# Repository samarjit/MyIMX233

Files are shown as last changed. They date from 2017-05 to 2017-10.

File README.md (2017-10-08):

# Let me see if I can build a linux Computer (It works now!)

I am starting to build a single board computer with freescale microprocessor iMX233 128 LQFP and 64MB DDR2 SDRAM in 66TSOP. This single board computer will be bare bones with lots of GPIO exposed.
There is no special goal for this project. I am just curious to see if it works. In future I might add an LCD. The PCB is two layered only and can be manufactured cheap.

## TODOs (done)
* Increase pad lengths of LQFP footprint. (done. Hope to mitigate the soldermask between pads issue  |<-0.06mm space-><-0.08mm web-><-0.06mm space->|  = 0.2mm) 
* Perhaps add a jumper on the 2.5v LineReg and separate out VDD_MEM to be able to test the 2.5v is not 0 due to loading. (skipped)
* 88 USB_ID SSP1_DETECT ? Should I use this to CD of SD card connector or micro USB ID pin?  In my circuit it is pulled low via LED. Tux,calculator does the same too.
* Add option to boot resistors LCD_RS and LCD_00..LCD_05 (done)
* 14 LCD_RS ? High for register boot mode. Or low with 47k resistor for OTP boot mode. Olimex is confusing OTP is set MMBR and LCD_RS is high. (done)
* Schottkey Diode D1 VDD4P2 direction. Its strange in ref diagram vs 5v wall. VDD4P2 -|>||- VDDBATT. (done Optional. Not populated in running board)
* Series resistor 1E for preventing oscillations (done 3 series resistor added, usb, batt, 4p2)
/in old circuit Test by removing Diode, and LED_RS to gnd via resistor.
* RESET circuit? Make sure not to get into USB recovery mode. add zener 1.0v so that it never reached 3.3v or just remove reset circuit altogether.
* Configure to get rid of batteries as per rev-c circuit. Add 1k resistors in DCDC_BATT and BATT and some caps to GND.
* Need to convert the SD card connector to a cheaper version available on ebay or alibaba. (done part-ATTEND 112J-TDAR-R01)
I got the files from https://forum.kicad.info/t/microsd-component-footprint-help/3095/5 and placed in parts/ folder. 
It would be awesome if I can find some 3D model of it. If someone finds it please create an issue. (Yes found)
* Make DDR RAM pin pads longer (new)
* Make alternate USB plug preferably through hole or longer pads in micro USB. (new)
* Make micro-SD pads larger and longer and add a few decoupling capacitors.(new)
* Make more rooms for the inductor as most inductors are really big 8mm long plus place for hand soldering.(new)

## TODOs (ignored)
* POWER off circuit? 
* Is Micro SD pullups on all pins necessary? SSP1_DETECT used? (done added them in the bottom side. Data3/CS pulled low)
* Added 120R between CLK nCLK.

### Length Tuning
* D0..D7 LDQS LDM - 39.7mm tuning (real 40.2mm)
* CLK nCLK - real 32.2/32.6mm
* D8..D15 UDQS UDM - 25.5mm tuning (real 26.0mm)
* Address: 32.35mm ~ 25mm
* CKE- 20.2mm
* SD: 24.8mm tuning (real 25.3mm)

## Installation steps
Cloning this repository should work.
It does use opendous
conn_fci from https://github.com/cpavlina/kicad-pcblib.git, https://github.com/cpavlina/kicad-schlib.git
Copy kicad-pcblib\conn-fci.pretty to  KiCad\share\kicad\modules\conn-fci.pretty
Add kicad-schlib-master\library\conn-fci.lib  to SchematicEditor -> ComponentLibraries
Add opendous to component libraries too.

## Drivers for this project.
* Until recently I didn't know of a decent opensource software for PCB designing or circuit designing which can be used to design complicated circuits involving microprocessor.
I recently discovered KiCAD which is opensource pcb designing software and people have done microprocessor design with it eg. OLinuXino. I am trying to learn PCB designing using KiCAD now.
* Second driver was Clementine Core project which I saw in circuitmaker website. This schematic looked so simple and pcb was on 2 layer design, which changed my thought process altogether that linux running board designs may be something I can try.
* Third driver was LibreCalc which almost proved that KiCAD can be used to design IMX233 based board. I hope to learn from their mistakes, but a newbee like me can uncover a whole lot of new mystries.

So I have put together a mashup of schematic design of IMX233 and 64MB RAM from freescale reference design and other sources. 

**Freescale microprocessor:**
* MCIMX233CAG4C

**DDR RAM - I think all these below RAM chips are compatible.**
* AS4C32M16MD1-5TCN
* HY5DU121622D(L)T(P)-J
* MT46V32M16P-5B:J (This is the only one I can source, so I am using this)

This project is a work in progress and there is no gurantee that I will ever be able to complete it :).

But if you want to try building same stuff as I am building. Go ahead and fork it.
Download KiCad. I am using nightly version of it, because it does not require you to export the netlist and import it again in pcb editor. Make the workflow really easy.
I can see one bug in KiCAD, which is after modifying the footprint by adding a step file. It looses the saved settings. 

Once you have installed KiCAD, open **MyIMX233.pro** file. 

[MyIMX233.sch](MyIMX233.sch) - Schematic file.

[MyIMX233.kicad_pcb](MyIMX233.kicad_pcb) - PCB

[ReferenceSch](ReferenceSch) - contains reference materials. I uploaded all of them for providing content incase someone wants to understand the design.

## Progress: 

### Oct 8 It worked! You can start building one today for yourself :)
Few soldering quirks are there. USB pads are quite small to solder. Also pad to hold USB in place is also very small and bad for soldering. Even the SD card pads are also small for soldering. These were new footprints so in next version I will make longer pads for these. RAM pads can be made slightly longer for reliable soldering. 
Soldered board and powered up without SD card. Some error were coming 0x80207002. Boot loader looking for I2C and it is not initialized. Turned out to be soldering of one pin was not proper for LQFP128. Fixed this pin issue then SD card missing related errors were coming. Added SD card with bogus data 0x8020A007 - ERROR_DDI_SD_CONFIG_BLOCK_NOT_FOUND. Added SD card formatted properly but still 0x8020A007. Little bit further digging showed that SD card MBR boot is not enabled by default. We need to burn an OPT bit HW_OCOTP_ROM0::SD_MBR_BOOT to enable booting from SD card. This process is irreversible. Default boot mode is BCB. I read up again librecalc's failure blog.  It gave two perl programs to burn the SD card with u-boot in BCB mode. The 2nd perl program didn't run as it assumed smaller SD cards only. I edited the perl program to make it find proper boot signatures. Now we can see something HTLC in UART console.
That's too less info to debug further. At this point I posted in freescale community. https://community.nxp.com/message/949934. I decided to blow the MBR OTP flag using BitBurner. Then added MBR based uSD card and same u-boot. Now again it shows HTLC. Good news is that MBR booting works. But it fails very soon. Need bootlets which gives more detailed log instead of u-boot. Turned out voltages are fluctuating all 3v3, 4v2, 1v8, 1v. They were fluctuating in a cycle. I burned official Olinuxino image in SD card. That seems to have bootlets so it gave more info. After right after memory `FRAC 0x92926192` it reboots. I heated up all the pins of DDR and iMX233 with soldering iron. It goes 1 more line ahead in log `init_ddr_mt46v32m16_133Mhz` and sometimes `power 0x00820710`. I added a big capacitor in place of battery which goes the log to further and says uSD card general error ending with r14<0>HTLLLL... I tried adding a few caps on 3v3. But nothing helped. Then I tried the other jumper of battery mode. Then it started loading kernel. 
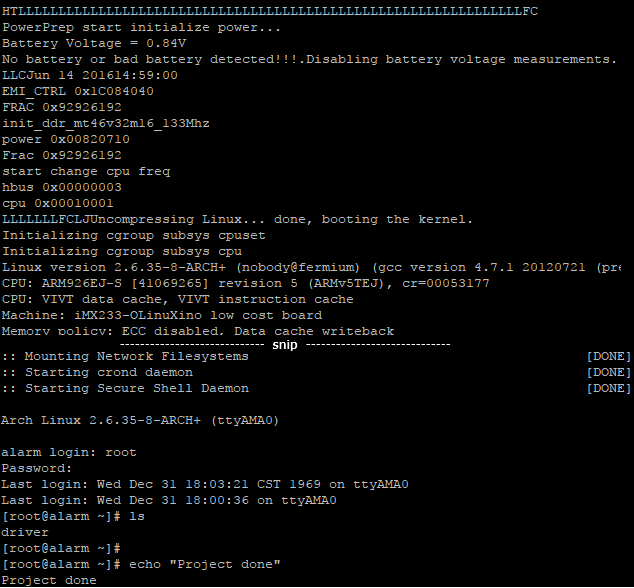
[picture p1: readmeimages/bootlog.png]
Bootup logs

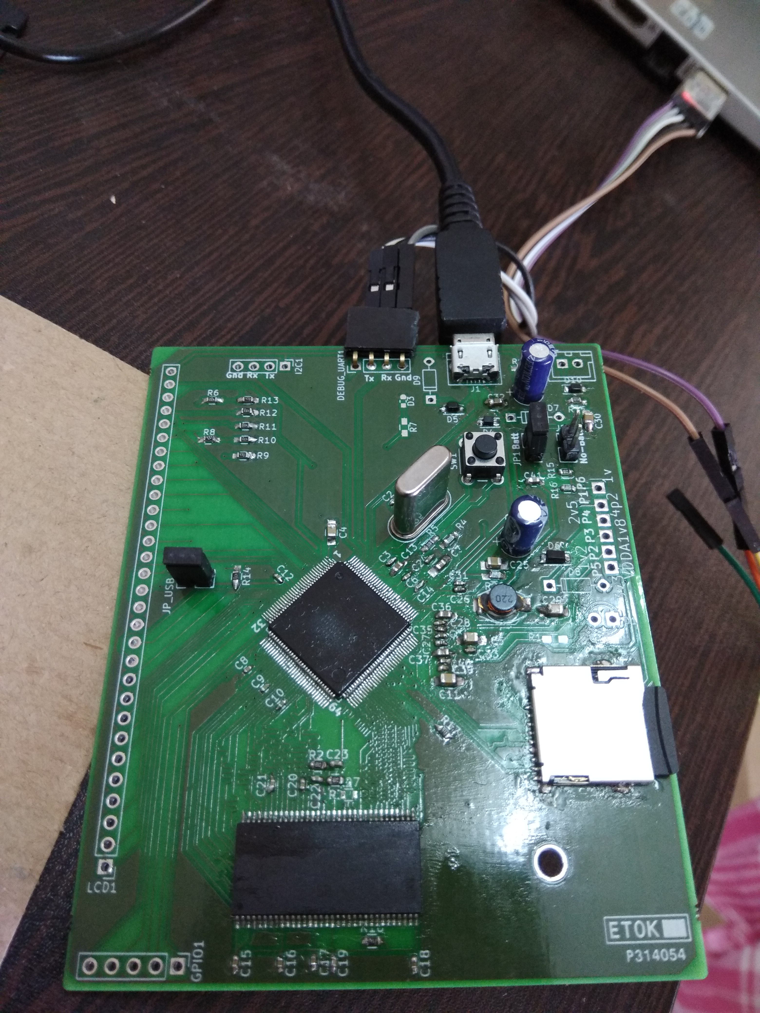
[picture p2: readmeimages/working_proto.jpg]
Final Board


### Aug 2017
Started modifying the schematic to make battery and USB wall power optional using jumpers. Also realized boot selection can be done using resistors. Sent for fabrication of PCB to pcbpower.

### July 2017 end first soldered board
Good news is most of the components fitted. Also I got some confidence about my KiCAD skills.
Some shortcomings were observed, like the pads for soldering were two short for the fine pitched LQFP128 0.4mm pitch and solder mask dams were not created between pads which made it incredibly hard to solder. I will have to customize the LQFP128 footprint to make it suitable for hand soldering. Some 0402 caps were placed very close, I realized the courtyard verification of components is not turned on by default. I had limited success like UART was working USB was working, BitBurner was working and showing all the OPT(One Time Programmable) bits. Some gibberish was coming on UART console. I used solder paste for soldering, so I thought some shorting might be happening. Then I tried to do reflow soldering to make the solder joints liquify once and then quickly cool it using a frying pan. It actually fried my board! I also mistakenly soldered uSD card with power on! Carelessness!
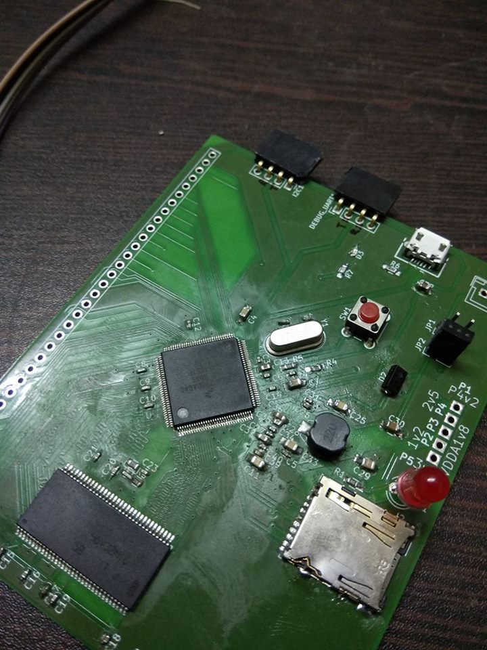
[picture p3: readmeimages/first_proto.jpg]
First Proto Soldered


* I also ordered components. I didn't realize this would be a pain. element14 is not that accessible for an individual. I ordered mostly from Shelfkey and some from KitsNSpares. I am still tensed if footprints I chose will match the actual components. Second I am very much tensed about soldering 0402 components.
* Final version of PCB sent for fab in pcbpower. 
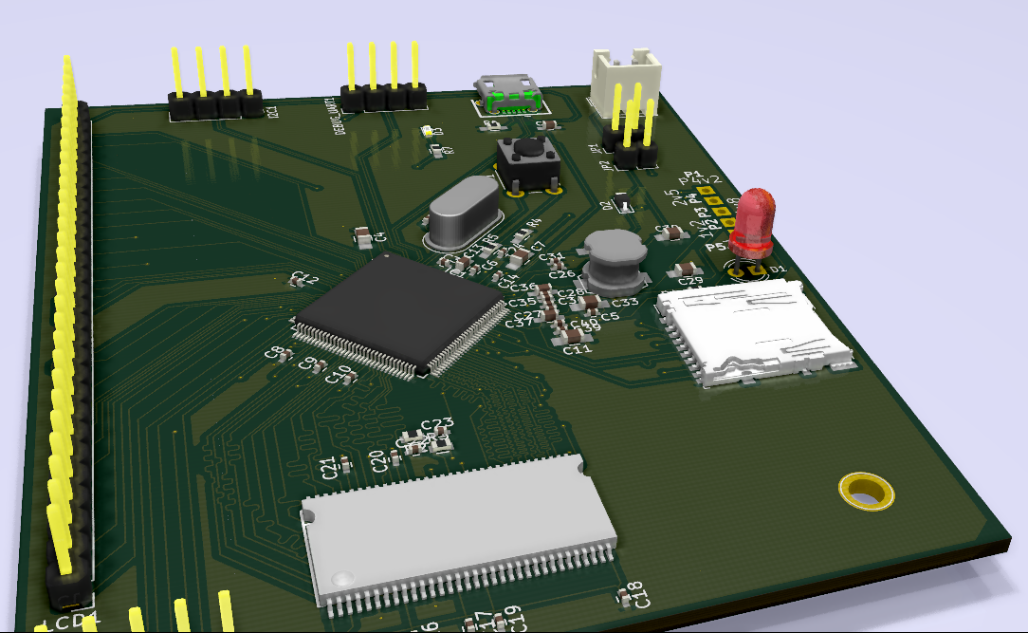
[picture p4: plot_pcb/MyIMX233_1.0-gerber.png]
Sent to fab


* Added few options to use DCDC. I was not comfortable of grounding DCDC_BATT and BATT pins, so I added a few jumpers. Also added provisions to add battery. 

* Learnt basic Freecad to build the Step files of DDR SDRAM 66TSOP. Here is the project I created - [MT46V32M16P-5B-Freecad-Step](https://github.com/samarjit/MT46V32M16P-5B-Freecad-Step).

* Initial version. DDR RAM child 3D missing and SD card's 3D missing.
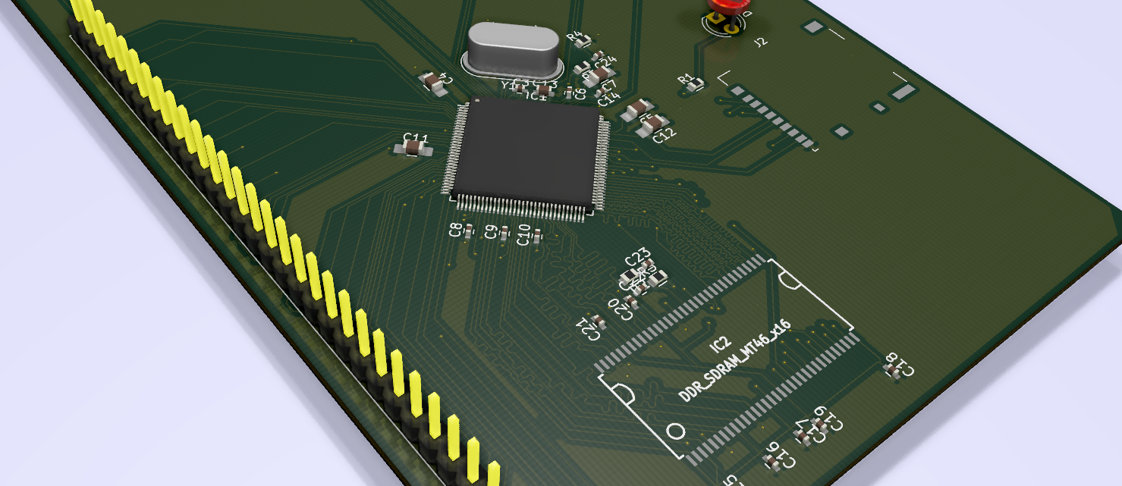
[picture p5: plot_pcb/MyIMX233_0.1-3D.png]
Initial plot


* Learnt Length Matching in Kicad. 

* Figured out placement of components. I am going with Clementine Core's placement which seems very good. 
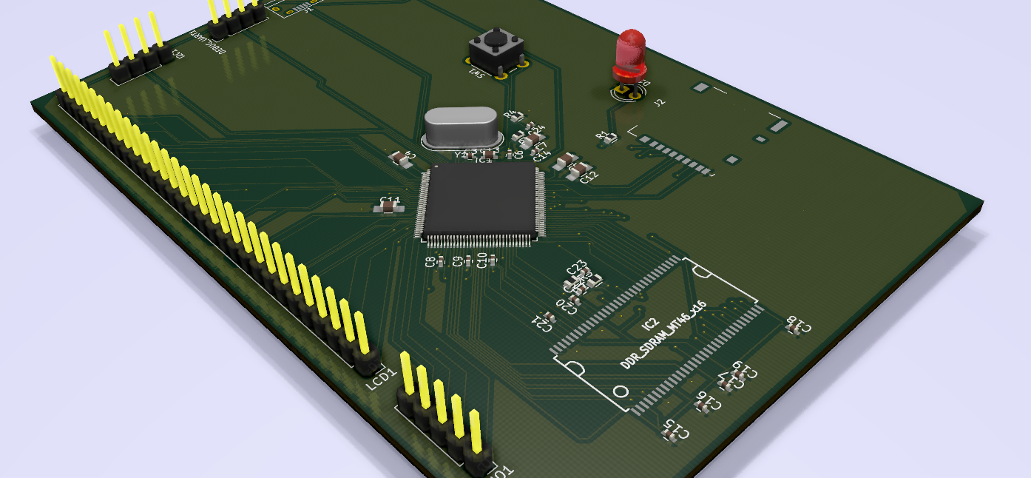
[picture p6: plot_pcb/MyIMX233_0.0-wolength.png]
Initial plot


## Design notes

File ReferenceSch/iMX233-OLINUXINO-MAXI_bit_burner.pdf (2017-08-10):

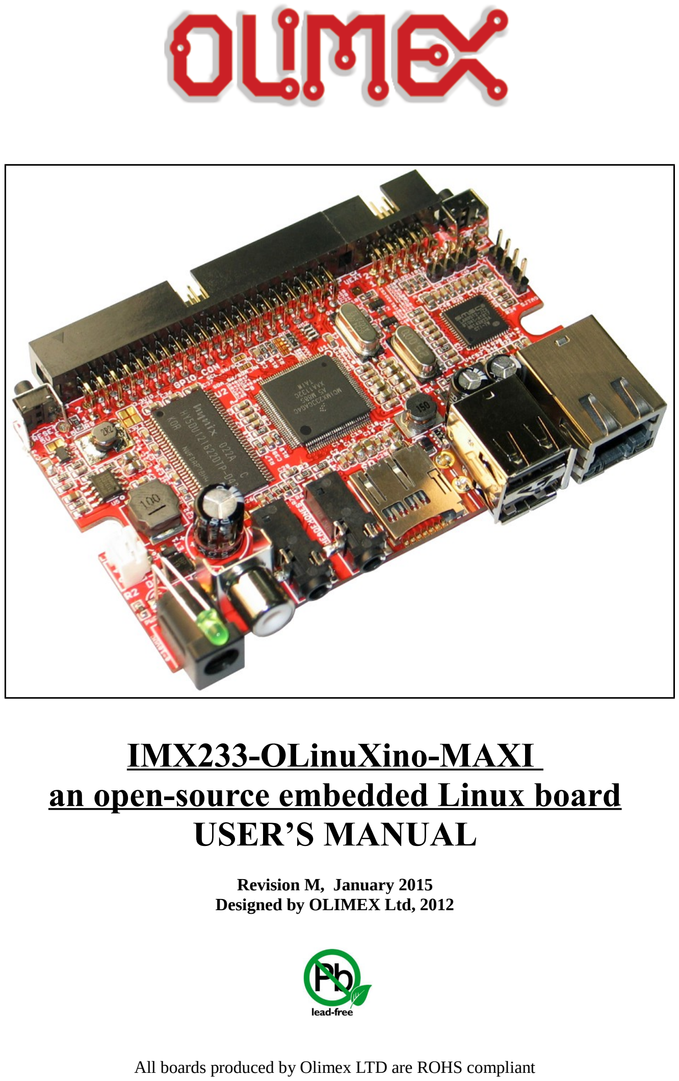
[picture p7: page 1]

# IMX233-OLinuXino-MAXI an open-source embedded Linux board USER’S MANUAL

Revision M, January 2015
Designed by OLIMEX Ltd, 2012

All boards produced by Olimex LTD are ROHS compliant

OLIMEX© 2015 | IMX233-OLinuXino-MAXI user's manual

### DISCLAIMER

© 2015 Olimex Ltd. Olimex®, logo and combinations thereof, are registered trademarks of Olimex Ltd. Other product names may be trademarks of others and the rights belong to their respective owners.

The information in this document is provided in connection with Olimex products. No license, express or implied or otherwise, to any intellectual property right is granted by this document or in connection with the sale of Olimex products.

This work is licensed under the Creative Commons Attribution-ShareAlike 3.0 Unported License. To view a copy of this license, visit http://www.creativecommons.org/licenses/by-sa/3.0/.

This hardware design by Olimex LTD is licensed under a Creative Commons Attribution-ShareAlike 3.0 Unported License.

The software is released under GPL.

It is possible that the pictures in this manual differ from the latest revision of the board.

The product described in this document is subject to continuous development and improvements. All particulars of the product and its use contained in this document are given by OLIMEX in good faith. However all warranties implied or expressed including but not limited to implied warranties of merchantability or fitness for purpose are excluded. This document is intended only to assist the reader in the use of the product. OLIMEX Ltd. shall not be liable for any loss or damage arising from the use of any information in this document or any error or omission in such information or any incorrect use of the product.

This evaluation board/kit is intended for use for engineering development, demonstration, or evaluation purposes only and is not considered by OLIMEX to be a finished end-product fit for general consumer use. Persons handling the product must have electronics training and observe good engineering practice standards. As such, the goods being provided are not intended to be complete in terms of required design-, marketing-, and/or manufacturing-related protective considerations, including product safety and environmental measures typically found in end products that incorporate such semiconductor components or circuit boards.

Olimex currently deals with a variety of customers for products, and therefore our arrangement with the user is not exclusive. Olimex assumes no liability for applications assistance, customer product design, software performance, or infringement of patents or services described herein.

THERE IS NO WARRANTY FOR THE DESIGN MATERIALS AND THE COMPONENTS USED TO CREATE OLINUXINO. THEY ARE CONSIDERED SUITABLE ONLY FOR OLINUXINO.

## Table of Contents

### CHAPTER 1: OVERVIEW

### 1. Introduction to the chapter

Thank you for choosing the OLinuXino single board computer from Olimex! This document provides a user’s guide for the Olimex OLinuXino board. As an overview, this chapter gives the scope of this document and lists the board’s features. The differences between the members of the OLinuXino family are mentioned. The document’s organization is then detailed.

The OLinuXino development board enables code development of applications running on the microcontroller i.MX233, manufactured by FreeScale Semiconductor.

OLinuXino is an open-source, open-hardware project and all documentation is available to the customer.

### 1.1 Features

- iMX233 ARM926J processor at 454Mhz
- 64 MB RAM
- SD-card connector for booting the Linux image
- TV PAL/NTSC video output
- 3 USB High Speed Host
- optional WIFI RTL8188CU module
- Stereo Audio Input
- Stereo Headphones Audio Output
- two Buttons
- UEXT connector (http://olimex.com/dev/OTHER/UEXT.pdf) for connection of different peripherial modules
- 40 pin GPIO for connection of other hardware
- Board is in shape for fit inside Pactec JM42 plastic box http://www.pactecenclosures.com/pdfs/drw_JM-42.pdf
- Power supply input 6-16VDC
- PCB dimensions: 3.70'' x 2.15'' (94.0mm x 54.6mm)
- Nominal dimensions: 3.70'' x 2.65'' (94.0mm x 67.3mm)

### 1.2 The OLinuXino family

Table of comparison
| OLinuXino-NANO | OLinuXino-MICRO | OLinuXino-MINI | OLinuXino-MAXI
Processor | iMX233 @ 454Mhz | iMX233 @ 454Mhz | iMX233 @ 454Mhz | iMX233 @ 454Mhz
Ram [MB] | 64 | 64 | 64 | 64
# USB hosts | 1 | 1 | 3 | 2

100/150 Mbit Ethernet* | No/WIFI option** | No/WIFI option** | No/WIFI option*** | Yes/WIFI option**
GPIO connector | 40pins | 60pins | 40pins | 40pins
# of buttons | 3 | 3 | 2 | 2

Reset button | Yes | Yes | Yes | Yes
DC power supply | 5V | 5V | 6V-16V | 6V-16V
Dimensions | 3.00'' x 0.80'' | 3.40'' x 1.70'' | 3.70'' x 2.65'' | 3.70'' x 2.65''
Breadboarding | Yes | Yes | No | No
Audio IN connector | No | No | Yes | Yes
Audio OUT connector | No | No | Yes | Yes
UEXT connector | Yes | No | Yes | Yes
Power jack | No**** | Yes | Yes | Yes
VGA connector | No | Yes | Yes | Yes

* 100Mbit Ethernet for the wired network of OLinuXino-MAXI. 150Mbit for the WIFI following 811.02n standard.

** All three boards have the option to work with MOD-WIFI_RTL8188, which is USB WIFI modem with RTL8188CU chip and can be purchased separately. MOD-WIFI_RTL8188 can be connected to any of the OLinuXino boards via the USB.

*** OlinuXino-MINI has additional option of having RTL8188CU hardware mounted! If you wish RTL8188CU embedded in the device you should purchase OLinuXino-MINI-WIFI. Choosing the embedded WIFI option will leave your USB-HOSTs available for use.

**** There is an easy access to the power pin holes, however. Especially, if you use a breadboard.

### 1.3 Target market and purpose of the board

The boards from the OLinuXino family are ready to use, easy to setup and are suitable for embedded programming enthusiasts, Linux hobbyists, gadget fans and also professionals (since its low cost makes it very good solution for application orientated embedded systems). The main usage of the board is software embedded development without the urge of understanding perfectly the hardware.

The strong points of the boards are the processor speed, the mobility of the board and the low price.

Customers have full access to the technical documentation of the board. The software is released under General Purpose License and the board is considered open-hardware.

### 1.4 Organization

Each section in this document covers a separate topic, organized as follow:
– Chapter 1 is an overview of the board usage and features
– Chapter 2 provides a guide for quickly setting up the board and software notes – Chapter 3 contains the general board diagram and layout
– Chapter 4 describes the component that is the heart of the board: the iMX233 microcontroller
– Chapter 5 is an explanation of the control circuitry associated with the microcontroller to reset. Also shows the clocks on the board
– Chapter 6 covers the connector pinout, peripherals and jumper description
– Chapter 7 shows the memory map
– Chapter 8 provides the schematics
– Chapter 9 contains the revision history, useful links and support information

### CHAPTER 2: SETTING UP THE OLINUXINO BOARD

### 2. Introduction to the chapter

This section helps you set up the OLinuXino development board for the first time. Please consider first the electrostatic warning to avoid damaging the board, then discover the hardware and software required to operate the board.

The procedure to power up the board is given, and a description of the default board behavior is detailed.

### 2.1 Electrostatic warning

OLinuXino is shipped in a protective anti-static package. The board must not be exposed to high electrostatic potentials. A grounding strap or similar protective device should be worn when handling the board. Avoid touching the component pins or any other metallic element.

### 2.3 Requirements

In order to set up the OLinuXino optimally, the following items are required:

- 6V to 16V source of power with 1A maximum amperage.
- SJTAG interface programmer
- USB keyboard
- Monitor with composite interface or Personal Computer + USB-SERIAL-CABLE
- SD card with Linux image

Note that the board arrives without SD card or Linux image. You can purchase a card with Linux separately. It is recommended that the user has basic Linux experience.

Some of the suggested items can be purchased by Olimex, for instance:
iMX233-OLinuXino-SD – SD card with the Linux image
USB-SERIAL-CABLE-F – USB serial console cable female (check “6.1.1 UART Debug” for info how to connect it to the board)
SY0612E – power supply adapter 12V/0.5A for iMX233-OLinuXino-Maxi

### 2.4 Powering the board

The board is powered either via the PWR jack or via a battery. It should be supplied from a 6V to 16V source with maximum current of 1A from the power jack.

All measures below are taken at 10V.

If measuring the current consumption it should be around 0.06A before initializing all the peripherals. The consumption raises to 0.12A without LAN and USB hosts initialized and Linux running. The consumption goes up 0.15A with the Linux running when LAN and both USB hosts initialized.

If you have a standard USB flash drive attached to a USB host, Linux and LAN running the typical consumption is around 0.20A.

When powered by the typical 3.7V battery the LAN and USB-hosts will be powered-off if you use the external 3.3V DC-DC (they will stil work if using the internal in the processor DC-DC). The consumption from the battery when Linux is running is around 0.75A.

IMPORTANT! We discovered a situation which might leave some of the SD cards (iMX233-OLinuXino-SD) in unrecoverable state when powering OLinuXino-MICRO. The problem might occur if two specific conditions are met simultaneously:

1)Plugged iMX233-OLinuXino-SD micro SD card with holographic sticker on its back side (some of the cards we have distributed are from a brand that places holographic sticker on their backs, the other half lack such a sticker)
2)Plugged USB-SERIAL-CABLE-F at the moment when powering the board

If you happen to have received SD card with holographic sticker on its back side and you use it with OLinuXino-MICRO and you plug USB-SERIAL-CABLE and then you power the board there is a chance of malfunction of the SD card.

There are two possible workarounds to protect the SD card. The first one is simpler and the second one requires some soldering experience.

Workaround 1: First insert the iMX233-OLinuXino-SD card and then power the board (and if powering the board from a battery also press the PWR button). Wait 4-5 seconds and then connect the USB-SERIAL-CABLE-F. After the initial power-up it is safe to use the reset button.

Workaround 2: You will need a Shottky diode. The Shottky should be soldered on the USB-SERIAL-CABLE-F TX line/wire (RED cable) with anode towards the board.

When you power the board by battery you have to press the PWR_BUT to start the board. If you start Linux and it is already running no matter which powering method you use (PWR_JACK or BAT) pressing the PWR_BUT will put the Linux in power-save mode.

When you power the board by battery you have to press the PWR_BUT to start the board. If you start Linux and it is already running no matter which powering method you use (PWR_JACK or BAT) pressing the PWR_BUT will put the Linux in power-save mode.

For the European customers we sell a power supply adapter 12V/0.5A – SY0612E.

### 2.5 Prebuilt software

Note that the boards arrive without Linux or SD card. The Linux image can be purchased separately on a SD card or you can built and adjust it yourself.

When we program the boards we change the default position of the following HW_OCOTP_ROM0 fuses of the processor:

SD_MBR_BOOT(3) - Blown
SD_POWER_GATE_GPIO(21:20) – 10-PWM3

For burning the fuse position we use the BitBurner software. This operation is discussed in details before. Proceed with great caution when burning fuses since it is irreversible operation.

The first batches of the board and the SD-card used the Debian Linux image. After that we switched over to ArchLinux for the ease of the package manager. Instructions how to build the ArchLinux can be found at the gitHub address of OLinuXino.

### 2.6 Using BitBurner

IMPORTANT! MODIFYING THE FUSES IS IRREVERSIBLE PROCESS! BURNING THE WRONG FUSES MIGHT DAMAGE OLINUXINO IRREVERSIBLY! BURNING WRONG FUSES MIGHT CAUSE BOOT PROBLEMS!

BURN FUSES AT OWN RISK!

The bit burning is done via the USB of the computer connected to the OLINUXINO board and the BitBurner software. To be able to burn the fuses you will need to make a custom cable that connects a USB with the 3 pin holes found at the bottom of the board named “GND”, “DP”, “DM” (check the picture below for a better view how the three wires must be connected.

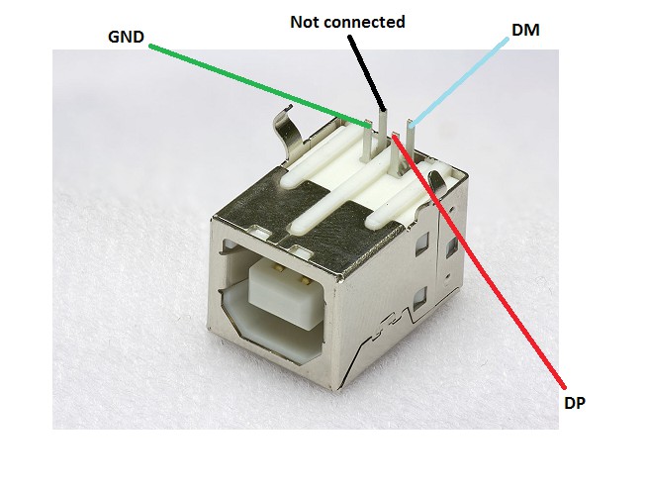
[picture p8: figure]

After soldering the three wires you can place a marker on each of them or use colored wires to be able to distinguish them. You can also use some gel to keep them tight on the USB connector. On the opposite side of the cables you might place 50mil (1.27mm) male connector following the order of the signals. Please also restrain from using wires longer than 20 cm since that might make the connection unreliable.

Download BitBurner from https://www.olimex.com/dev/OLINUXINO/iMX233-OLINUXINO/BitBurner.v1.0.4.6.zip. (https://www.olimex.com/dev/OLINUXINO/iMX233-OLINUXINO/BitBurner.v1.0.4.6.zip) Extract it and start the .exe. If you connect everything you should see and choose HID-compilant device from the “Select device” drop-down menu.

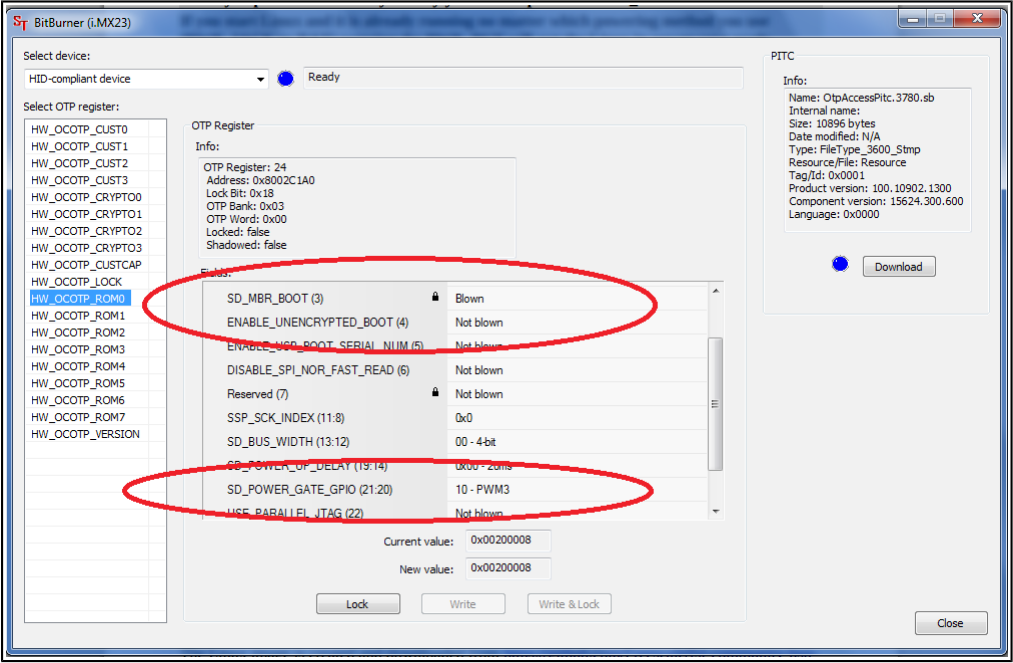
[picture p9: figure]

### 2.7 Building the Linux image

Note that building the Linux image from scratch is a time-consuming task. Even with powerful machine and fast internet connection it might take few hours compiling. Some Linux distributions might lack the tools required to compile/build/execute scripts/download from repository – how to get those is not discussed below.

The Linux image is created and downloaded from https://github.com/Freescale/fsl-community-bsp-platform. (https://github.com/Freescale/fsl-community-bsp-platform) For the test here we used Debian 6.0 with GNOME visual libraries. The steps we did:

1) From the terminal created folder “bin” in home folder:

user@dist$: mkdir bin
user@dist$: cd bin

Add bin directory to PATH in order to do the next steps easier. Else navigate to the right folders.

2) Installed `repo` utility needed for the bitbake file fetching from the repository:

user@dist$: curl https://dl-ssl.google.com/dl/googlesource/git-repo/repo > ~/bin/repo user@dist$: chmod a+x ~/bin/repo

3) Created directory for the project and download the BSP source from the git repository:

user@dist$: mkdir fsl-community-bsp
user@dist$: cd fsl-community-bsp

~/fsl-community-bsp$: repo init -u https://github.com/Freescale/fsl-community-bsp-platform -b denzil
~/fsl-community-bsp$: repo sync
4) You can change the settings for the build if you want at fsl-community-bsp/build/conf/local.conf. I changed the “machine” name to “imx233-olinuxino-maxi”.
For Linux kernel configurations and settings you can do (of course you can use also the default settings):

~/fsl-community-bsp$:. ./setup-environment build
~/fsl-community-bsp/build$:bitbake linux-imx -c menuconfig

Check the image below:

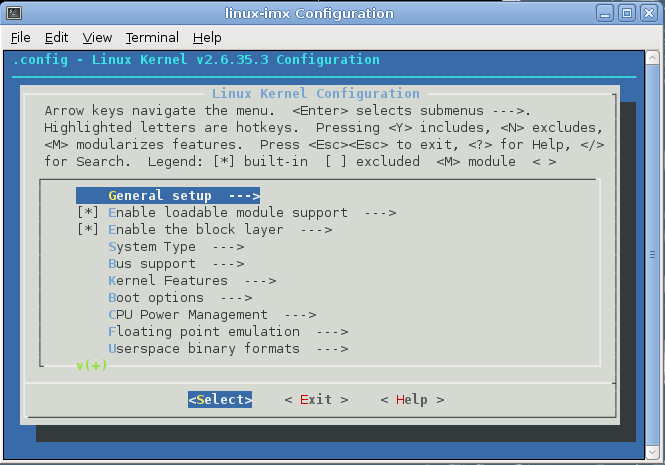
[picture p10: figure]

5) Now to start building the image:

~fsl-community-bsp$:. ./setup-environment build

~fsl-community-bsp/build $: bitbake core-image-minimal

Note: on different Linux distributions you might have different tools installed and you will probably need to install dependencies needed for the compile/build scripts. Here are some (but not all) of the mandatory ones: G++; diffstat; texi2html; chrpath; gawk; texinfo; some git client.

To ensure you have the latest version supported with all the updates visit https://github.com/OLIMEX/OLINUXINO and https://github.com/Freescale/fsl-community-bsp-platform. (https://github.com/Freescale/fsl-community-bsp-platform)

### 2.8 How to blink the LED

In this sub-chapter you will find a way to achieve the most basic task in electronics – the “Hello World” of electronics – blinking the LED.

First we set the pin responsible for the LED as an output and we can set its value manually to high or low position – make it blink manually. The LED mounted on the board uses GPIO65. You can use external diode instead of the one mounted – you have to look at the table “The Linux implementation of pins” in the hardware section to get the correct linux name for the GPIO pin.

echo out > /sys/class/gpio/gpio65/direction
echo 1 > /sys/class/gpio/gpio65/value

If you want to set the blink off you should change the value on the second line to:

echo 0 > /sys/class/gpio/gpio65/value

To show the info for all GPIOs:

ls /sys/class/gpio

To make it turn on – turn off automatically (e.g. blink) we use the text redactor VI to write the Linux script:

echo out > /sys/class/gpio/gpio65/direction
while true
do
echo 1 > /sys/class/gpio/gpio65/value sleep 1
echo 0 > /sys/class/gpio/gpio65/value
sleep 1
done

We save it as as “gpio” and we make it executable with

chmod +x gpio

then we execut the script with:

./gpio

The LED should start blinking with 0.5Hz.

### 2.9 How setup the I2C, SPI, UART

There are number of examples with our extension module board to achieve those connections on the UEXT. The examples might be used as an example for I2C, SPI or UART communication. You can find them at our GitHub page:
https://github.com/OLIMEX/OLINUXINO/tree/master/SOFTWARE/iMX233

NOTE that to use software I2C you have to set the SMD jumpers to the proper side. By default the board uses hardware I2C.

### 2.10 How to setup Arch-Linux distribution

This is a step-by-step guide for building the Archlinux image for Olimex OLinuXino-MAXI. The second and the third part of the document explain how to setup the internet connection on the board and how to use the GCC compiler to compile „HelloWorld“ example on the OLinuXino.

Two important preparations:
1)You have to download the latest software package from the GitHub of iMX233-OLinuXino, down in the code you will meet “xxxxxxx” which you will have to replace with the correct locations in the package.
2)When trying I2C examples I2C jumpers has to be configured for hardware I2C mode.
I. How to create SD-card with Archlinux image
1. Download the image files from: xxxxxxx . Put the files in desired folder, for example /home/User/Archlinux.
2. Insert the card-reader into the Linux host machine.

IMPORTANT NOTE – this example is given with "sdb1 and sdb2" devices but it could enumerate differently on your host, so confirm what it enumerates as before running fdisk!

3. Unmount the card-reader:
& sudo umounth /dev/sdb1
4. Format the SD-card using fdisk:
& sudo fdisk /dev/sdb
5. With the help of the menu create two partitions. The steps are the following:
5.1. Type “p” to view existing partitions on the SD-card
5.2. Type “d” to delete all partitions

5.3. Type “n” to create new one
5.4. Set “1” as partition number
5.5. Type “p” to select primary partition
5.6. Press Enter to select default beginning sector
5.7. Type “+32M” to create 32MB partition
5.8. Type “t” to change partition type
5.9. Type “53”
5.10. Type “n” to create another partition
5.11. Set “2” as partition number
5.12. Type “p” to set partition as primary
5.13. Press Enter to set default size of the partition
5.14. Type “w” to write partitions to the SD-card
6. Create the second partition with ext3 file system: & sudo mkfs.ext3 /dev/sdb2
7. Mount the second partition:
& sudo mount /dev/sdb2 /mnt/mmc

If you don't have mountpoint you should create one. Just type: sudo mkdir /mnt/dir

8. Login as root for the next operations:
& sudo su

IMPORTANT NOTE: It is necessary to log-in as root, not as super-user!

9. Extract the downloaded tarball into the second partitions:
& tar -xzf /home/User/Archlinux/xxxxx.tar.gz
10. The next step is to to write the bootloader and kernel image to the first partition. & dd if=/Archlinux/xxxxx.img of=/dev/sdb1 ibs=512 seek=4 conv=sync,notrunc
11. Unmount the SD-card, it should be ready for use.
& cd
& umount /dev/sdb2
12. Download the new kernel patch from: xxxxxxxxxxxxxxxxxxxx
13. Put the file in USB flash drive. Insert the flash drive into OLinuXino board. & mount /dev/sdc1 /mnt/usb
& cp -fv /home/User/Downloads/<file> /mnt/usb
& umount /mnt/usb

Again this is example. You should correct this commands with your paths and corresponding devices.

IMPORTANT NOTE: The following commands are entered into OLinuXino terminal.

14. Mount the flash drive
& mount /dev/sdb1 /mnt/usb
15. Run pacman to update the kernel:
& pacman -S /mnt/usb/kernel26-olinuxino-2.6.35.3-6-arm.pkg.tar.xz
16. Follow the instructions. Just type “y” when promted.
17. Reboot

IMPORTANT NOTE: If you are connected to internet, you can use the following command: & pacman -U http:// xxxxxxx.tar.xz.
Using this you can skip the part with the USB flash drive. Using the same command you could download different packages:
& pacman -Sy <package name>

II. Set up the internet

This is a working example, but you might wish to read some additional information, if this doesn't work for you.

With every reboot the device is assigned with different MAC address. To change this use the commands:

& ip link set dev usb0 down
& ip link set dev usb0 address aa:bb:cc:dd:ee:ff
& ip link set dev usb0 up

To set an IP address enter:
& ifconfig usb0 192.168.0.249
or whatever address you want.
After that add default gateway:
route add default gw 192.168.0.1 usb0

Finally you should add DNS-server. You should modify /etc/resolv.conf with vi, or other program. For example:
& vi /etc/resolv.conf

Press d several times to remove all lines. Press I to enter insert mode. Type:
& nameserver 192.168.0.1

(Again this is example. You should add you DNS-server.)
After you finish entering this press Esc. This will set the program in command mode. In command mode press:

& :wq

This should do the work. To check connection use ping. If it doesn't check your configuration again and router settings. You can use ifconfig to see OLinuXino settings.

III. Using GCC to make Hello_World
In the home folder there are some examples
& cd /home/examples
& ls
And you should see all files and folders. You can create new folder (if you want) with the command:
& mkdir <some dir>

To see our HelloWorld program go to /HelloWorld folder
& cd /home/examples/HelloWorld
& ls

In this folder are two files:
- hello
- hello_world.c

The C file is the sourse code. Actually this is text file with .c extention. Type vi or cat hello_world.c to view the source. You could modify the source whatever you want. After the source is ready to compile the file use:
& gcc -o hello_world.c hello

For more complicated compiling type:
& man gcc

To execute the program:
& ./hello <some name>

The result of the execution should be:

Hello <some name>.
In the other directory /home/i2c are three examples for hardware I2C. You could compile them using the same command:
& gcc -o <file>.c <file>

After execution you could see the I2C working using osciloscope connected to the corresponding GPIOs.

You can see that the LED1 on the board is blinking. This is a backgrond shell process. Again in the /home you can see a third folder led_blink. In this one there is a file led_blink. Type:
& cat led_blink

You can see that this is shell script. To execute this script every time the linux is loaded the path should be added to the file rc.local. & vi /etc/rc.local

Add the path to the script file: /home/examples/led_blink/led_blink &

The "&" means that the script will be running in background.

### 2.11 How to use a USB WiFi dongle based on RealTek RTL8188CUS and

RTL8192CU under ARCH Linux

This procedure was done on the Olinuxino-Maxi. It was connected with a wired ethernet during the procedure. Once the WiFi is functional, the wired ethernet can be removed. The microSD card can then be moved to another Olinuxino board such as the Micro.

Log into the Olinuxino board.

upgrade the system:
pacman -Syu

Then install development tools pacman -S base-devel

Delete empty directories:
rmdir /usr/lib/modules/2.6.35-6-ARCH+/build rmdir /usr/lib/modules/2.6.35-6-ARCH+/source

Install kernel source:
pacman -S kernel26-headers-olinuxino

Get the Realtek drivers from the Realtek web site: http://www.realtek.com.tw/downloads/downloadsView.aspx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

I downloaded RTL8188CUS (the one showing up on lsusb)
If you choose RTL8192CU you get the same file

The file comes as a zip file:
RTL819xCU _USB_linux_v3.4.3_4369.20120622.zip

Assume you downloaded it to your workstation.
Unzip the file.
Inside there is a folder called driver with a file inside called: rtl8188C_8192C_usb_linux_v3.4.3_4369.20120622.tar.gz

Copy that file to the Olinuxino target:
scp rtl8188C_8192C_usb_linux_v3.4.3_4369.20120622.tar.gz root@ip_addr_of_Olinuxino:/root

log into Olinuxino
cd /root
mkdir driver
mv rtl8188C_8192C_usb_linux_v3.4.3_4369.20120622.tar.gz driver cd driver
tar xzf rtl8188C_8192C_usb_linux_v3.4.3_4369.20120622.tar.gz cd rtl8188C_8192C_usb_linux_v3.4.3_4369.20120622
vi Makefile

Change the line:
CONFIG_PLATFORM_I386_PC = y to
CONFIG_PLATFORM_I386_PC = n

Below it add the line:
CONFIG_PLATFORM_ARM_iMX233 = y

find the block:
ifeq ($(CONFIG_PLATFORM_ARM_PXA2XX), y) EXTRA_CFLAGS += -DCONFIG_LITTLE_ENDIAN ARCH := arm
CROSS_COMPILE := arm-none-linux-gnueabi-KVER := 2.6.34.1
KSRC ?= /usr/src/linux-2.6.34.1
endif
---------------------------------------------------------Below it adds the block:
ifeq ($(CONFIG_PLATFORM_ARM_iMX233), y) EXTRA_CFLAGS += -DCONFIG_LITTLE_ENDIAN

ARCH := arm
CROSS_COMPILE := /usr/bin/
KVER := KVER := 2.6.35-6-ARCH+
KSRC ?= /usr/src/linux-2.6.35-6-ARCH+
MODDESTDIR := /usr/lib/modules/2.6.35-6-ARCH+/kernel/drivers/net/wireless/rtl818x endif
Save and exit:
:wq

make clean
make
rmmod 8192cu.ko (not really needed) insmod 8192cu.ko
make install

Verify that the driver has been installed:

[root@alarm wireless]# ls -l /sys/class/net total 0
drwxr-xr-x 4 root root 0 Aug 14 16:55 lo drwxr-xr-x 4 root root 0 Aug 14 16:55 usb0 drwxr-xr-x 5 root root 0 Aug 14 16:43 wlan0

wlan0 is the new driver

reboot

Make sure you can see both usb0 (ethernet) and wlan0 on all the following: ifconfig
ls -l /sys/class/net
iwconfig

you may need to bring the interface up manually: ip link set wlan0 up

scan for access points:
iwlist wlan0 scan
cp /etc/wpa_supplicant/wpa_supplicant.conf /etc/wpa_supplicant/wpa_supplicant.conf.original wpa_passphrase myssid "my_secret_passkey" > /etc/wpa_supplicant/wpa_supplicant.conf

Associate with access point according to the encryption type:
Encryption | Command
No Encryption | iwconfig wlan0 essid "linksys"
WEP w/ Hex Key | iwconfig wlan0 essid "linksys" key "0241baf34c"
WEP w/ ASCII passphrase iwconfig wlan0 essid "linksys" key "s:pass1"
WPA | wpa_supplicant -B -Dwext -i wlan0 -c /etc/wpa_supplicant/wpa_supplicant.conf

Verify association:
iwconfig wlan0

Assign IP address:
dhcpcd wlan0 | (dhcp)
or | (static)
ip addr add 192.168.0.2/24 dev wlan0 ip route add default via 192.168.0.1 -------------------------------------------------To set up automatically at boot:
pacman -S netcfg
pacman -S wpa_actiond
pacman -S ifplugd

cp /etc/network.d/examples/wireless-wpa /etc/network.d/my_wifi_network cp /etc/network.d/examples/ethernet-dhcp /etc/network.d/my_eth_network vi /etc/network.d/my_wifi_network
configure all parameters

vi /etc/network.d/my_eth_network
configure all parameters (make sure you change eth0 to usb0)

You can have multiple profiles (e.g. for roaming, etc.)

To manually connect a profile:
netcfg my_wifi_network
To manually disconnect a profile:
netcfg down my_wifi_network

There are 3 daemon options for configuring networks at boot time.

1. network – the original setting. don't use that since we're using netcfg
2. net-profiles
or
3. net-auto-wireless and net-auto-wired
This procedure is using the last option.

vi /etc/rc.conf
Look for DAEMONS=(..)
delete network and add:
net-auto-wireless and net-auto-wired

vi /etc/conf.d/netcfg
Change to: NETWORK=(@my_wifi_network @my_eth_network)
Make sure you have the correct names for WIRED_INTERFACE and WIRELESS_INTERFACE (change eth0 to usb0)
Also see:
https://wiki.archlinux.org/index.php/Beginners'_Guide#Setup_wireless_networkhttps://wiki.archlinux.org/index.php/Wireless_Setup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

Other commands:
ip link show wlan0

### CHAPTER 3: OLINUXINO BOARD DESCRIPTION

### 3. Introduction to the chapter

Here you get acquainted with the main parts of the board. Note the names used on the board might differ from the names used below to describe them. For the actual names check the OLinuXino board itself.

### 3.1 Layout (top view)

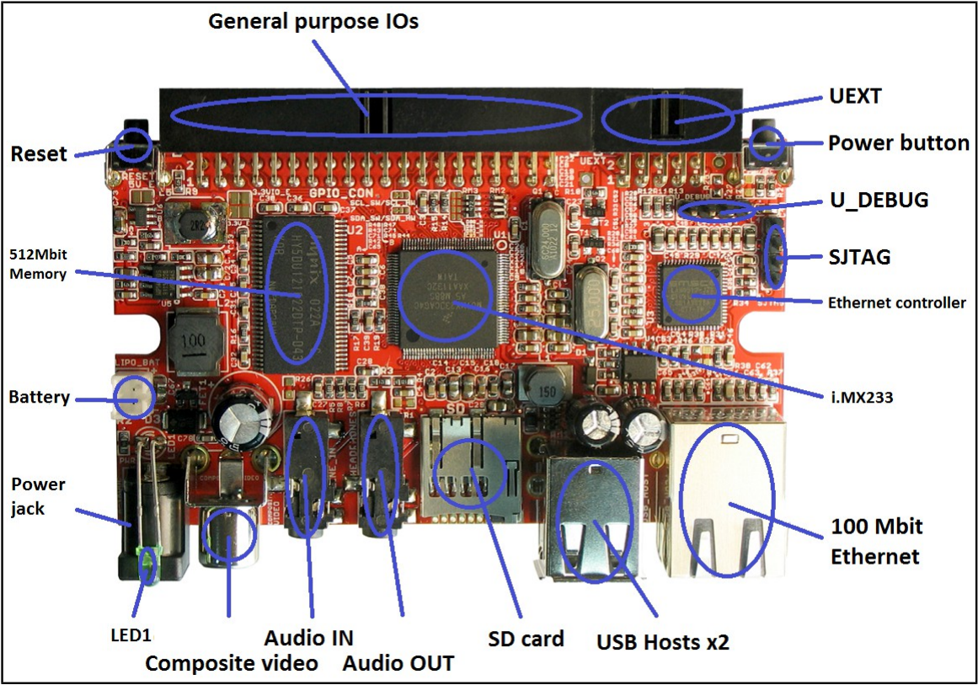
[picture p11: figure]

### CHAPTER 4: THE iMX233 MICROCONTROLLER

### 4. Introduction to the chapter

In this chapter is located the information about the heart of OLinuXino – its microcontroller. The information is a modified version of the datasheet provided by its manufacturers.

### 4.1 The microcontroller

- ARM926 CPU Running at 454 MHz
- Integrated ARM926EJ-S CP
- 16-Kbyte data cache and 16-Kbyte instruction cache
— One-wire JTAG interface
— Resistor-less boot mode selection using integrated OTP values
- 32Kbytes of Integrated Low-Power On-Chip RAM
- 64 Kbytes of Integrated Mask-Programmable On-Chip ROM
- 1 Kbit of On-Chip One-Time-Programmable (OCOTP) ROM
- Universal Serial Bus (USB) High-Speed (Up to 480 Mb/s), Full-Speed (Up to 12 Mb/s) — Full-speed/high-speed USB device and host functions
— Fully integrated full-speed/high-speed Physical Layer Protocol (PHY)
— Mass storage host-capable (uncertified by USB-IF)
- Power Management Unit
— Single inductor DC-DC switched converter with multi-channel output supporting Li-Ion batteries.
— Features multi-channel outputs for VDDIO (3.3 V), VDDD (1.2 V), VDDA (1.8 V), VDDM (2.5V) and regulated 4.2V source.
— Direct power from 5-V source (USB, wall power, or other source), with programmable current limits for load and battery charge circuits.
— Silicon speed and temperature sensors enable adaptive power management over temperature and silicon process.
- Audio Codec
— Stereo headphone DAC with 99 dB SNR
— Stereo ADC with 85 dB SNR
— Stereo headphone amplifier with short-circuit protection and direct drive to eliminate bulky capacitors
— Amplifiers are designed for click/pop free operation.
— Two stereo line inputs
— Microphone input
— SPDIF digital out
- 16-Channel Low-Resolution ADC

— 6 independent channels and 10 dedicated channels — Resistive touchscreen controller
— Temperature sensor controller
— Absolute accuracy of 1.3%
- Security Features
— Read-only unique ID for digital rights management algorithms
— Secure boot using 128-bit AES hardware decryption
— SHA-1 hashing hardware
— Customer-programmed (OTP) 128 bit AES key is never visible to software.
- External Memory Interface (EMI)
— Provides memory-mapped (load/store) access to external memories
— Supports the following types DRAM:
— 1.8V Mobile DDR
— Standard 2.5V DDR1
- Wide Assortment of External Media Interfaces
— High-speed MMC, secure digital (SD)
— Hardware Reed-Solomon Error Correction Code (ECC) engine offers industry-leading protection and performance for NANDs.
— Hardware BCH ECC engine allowing for up to 20-bit correction and programmable redundant area.
- Dual Peripheral Bus Bridges with 18 DMA Channels
— Multiple peripheral clock domains save power while optimizing performance.
— Direct Memory Access (DMA) with sophisticated linked DMA command architecture saves power and off-loads the CPU.
- Highly Flexible Display Controller
— 8-bit data ITU-R BT.656 D1 digital video stream output mode (PAL/NTSC), with onthe-fly RGB to YCbCr color-space-conversion.
— Flexible input formats
- Pixel Processing Pipeline (PXP)
— Provides full path from color-space conversion, scaling, alpha-blending to rotation without intermediate memory access
— Bi-linear scaling algorithm with cropping and letterboxing
— Alpha-blend, BITBLT, color-keying
— Memory efficient block-based rotation engine
- Integrated TV-Out Support
— Integrated PAL/NTSC TV-encoder fully pipelined to display controller’s D1 resolution output stream
— Integrated low-power 10-bit Video DAC (VDAC) for composite analog video output.
- Data Co-Processor (DCP)
— AES 128-bit encryption/decryption

— SHA-1 hashing
— High-speed memory copy
- Three Universal Asynchronous Receiver-Transmitters (UARTs)
— Two high-speed application UARTs operating up to 3.25 Mb/s with hardware flow control and dual DMA.
— Debug UART operates at up to 115Kb/s using programmed I/O.
- I2C Master/Slave
— DMA control of an entire EEPROM or other device read/write transaction without CPU intervention
- Dual Synchronous Serial Ports (for SPI, MMC, SDIO, Triflash)
— 1-bit, 4-bit and 8-bit MMC/SD/SDIO modes
— Compliant with SDIO Rev. 2.0
— SPI with single, dual and quad modes.
- Four-Channel 16-Bit Timer with Rotary Decoder
- Five-Channel Pulse Width Modulator (PWM)
- Real-Time Clock
— Alarm clock can turn the system on.
— Uses the existing 24-MHz XTAL for low cost or optional low power crystal (32.768 kHz or 32.0 kHz), customer-selectable via OTP.
- Customer-Programmable One-Time-Programmable (OTP) ROM via Integrated eFuse Block — Resistor-less boot mode selection
— 128-bit boot mode crypto key
— Boot mode specification of NAND characteristics for device that the customer is soldering to the board. This means no more costly delays waiting for new device support in t he boot ROM.
— Fully software-programmable and accessible
- Flexible I/O Pins
— All digital pins have drive-strength controls
— Most non-EMI digital pins have general-purpose input/output (GPIO) mode.

For comprehensive information on the microcontroller visit the Freescale’s web page for a datasheet.

At the moment of writing the microcontroller datasheet can be found at the following link: http://www.freescale.com/files/dsp/doc/ref_manual/IMX23RM.pdf

### CHAPTER 5: CONTROL CIRCUITY

### 5. Introduction to the chapter

Here you can find information about reset circuit and quartz crystals locations, the power supply circuit is discussed.

### 5.1 Reset

OLinuXino's reset circuit includes R9 (47KΩ), R10 (47 Ω), T1, T2, Q1 and a RESET button. The RESET is specific for the fact that it is accomplished when the quartz is disconnected using 3.3V and the transistors T1 and T2.

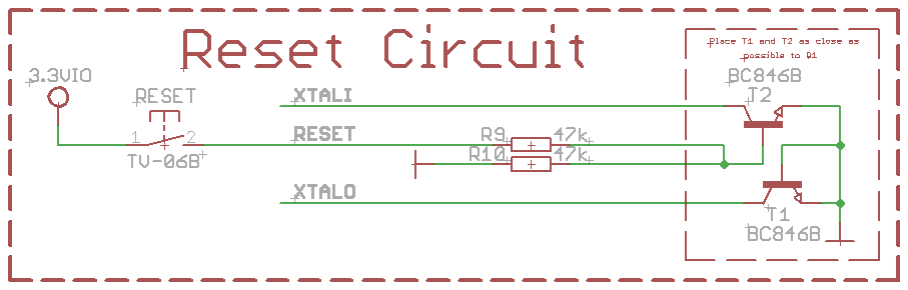
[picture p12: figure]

### 5.2 Clocks

24 MHz quartz crystal Q1 is connected to pins 121 and 122 of the iMX233 processor.

25 MHz quartz crystal Q2 is found at pins 60 and 61 of the Ethernet controller – LAN9512-JZX.

### 5.3 Power supply circuit

The power supply circuit of OLinuXino-MAXI allows flexible input supply from 6V to 16V direct current. This means a wide range of power supplies, adapters, converters are applicable. The maximum amperage recommended is 1A by default (0.250mA if 3.3VIO_E is closed – read below).

All measures below are taken at 10V external supply.
If measuring the current consumption it should be around 0.06A before initializing all the peripherals. The consumption raises to 0.12A without LAN and USB hosts initialized and Linux running. The consumption goes up 0.15A with the Linux running when LAN and both USB hosts initialized.

If you have a standard USB flash drive attached to a USB host, Linux and LAN running the typical consumption is around 0.20A.

When powered by the typical 3.7V battery the LAN and USB-hosts are disabled. The consumption when Linux is running is around 0.75A.

The board can be powered either from the power jack or from the LIPO_BAT connector. Note that since standard batteries can't provide the voltage needed for the board it is advisable to use the power from the power jack. When you use the LIPO_BAT connector and a battery the chip handling the Ethernet and the USB hosts is disabled. Also the power button has alternative function when the board is powered by a battery – check 6.13.

If you have successfully powered the board the red PWR LED will turn on. Note that it is possible to have the PWR LED on even if there isn't enough power for proper operation of the board and all the peripherals currently connected.

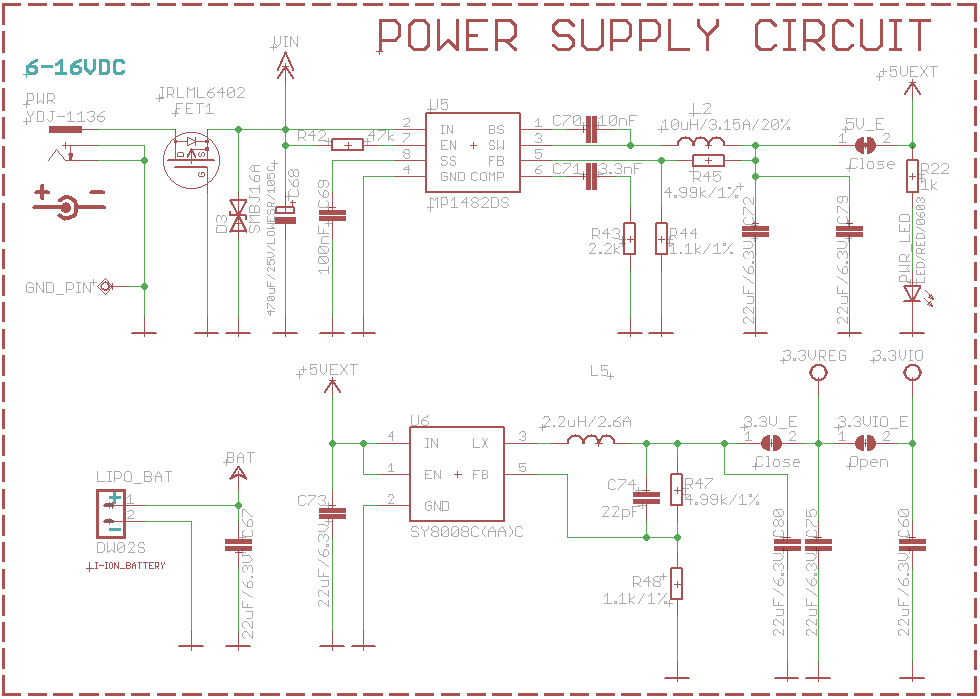
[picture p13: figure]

The jumper 5V_E (5V Enable) which is closed by default enables powering the board via the power supply circuit.

The 3.3V_E (3.3V Enable) jumper when closed enables the 3.3V power line.

Note the 3.3VIO_E jumper which by default is closed – if you open it (cut it) - it disables the U6 DC-DC converter and enables a built-in the iMX233 DC-DC. The problem is that the built-in DC-DC has a limit of 250mA of amperage the chip heats a bit so we decided to put external DC-DC for better stability. When working with 3.3VIO_E closed pay attention to the amperage used.

If 3.3VIO_E is closed(soldered) – it enables the additional DC-DC which is the better solution if powering the board from external supply. However, if 3.3VIO_E is closed and you power the board from a battery the LAN and the USB-HOSTs will not receive enough power and will be disabled.

### CHAPTER 6: CONNECTORS AND PINOUT

### 6. Introduction to the chapter

In this chapter are presented the connectors that can be found on the board all together with their pinout and notes about them. Jumpers functions are described. Notes and info on specific peripherals are presented. Notes regarding the interfaces are given.

### 6.1 Debugging interfaces

If you don't have a separate monitor or display around, and you don't wish to swap cables constantly with your personal computer using the debug interfaces provide better option for you OLinuXino experience.

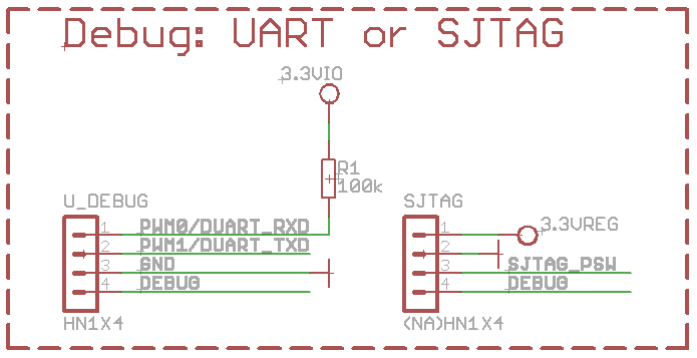
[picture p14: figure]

There are three debugging options available on the OLinuXino. It is preferable to use one of the first two – UART or SJTAG but in case you want to use the classic 6-wire parallel JTAG there is an option explained below.

### 6.1.1 UART debug

The first one is a debug UART interface – U_DEBUG. You can use our USB-SERIAL-CABLE for debugging via the UART.

In order to avoid SD card malfunction, when using the USB-SERIAL-CABLE-F with OLinuXino-MAXI it is advisable to first insert the iMX233-OLinuXino-SD card and then power the board (if using battery also press the PWR button). Wait 4-5 seconds and then connect the USB-SERIAL-CABLE-F.

Please also check “2.4 Powering the board” for detailed info.

Note on how to use the U_DEBUG with USB-SERIAL-CABLE-F which has RED GREEN BLUE wires GND=BLUE, RX(INPUT)=GREEN, TX(OUTPUT)=RED. You have to connect to OLinuXino-MAXI U_DEBUG connector in this sequence:

BLUE wire to pin.3 (GND)
GREEN wire to pin.2 (TX)
RED wire to pin.1 (RX)

U_DEBUG

Pin # | Signal Name | Processor Pin #
1 | PWM0/DUART_RXD | 125
2 | PWM1/DUART_TXD | 126
3 | GND | 30, 35, 98, 105, 112, 118
4 | DEBUG | 84

You can also check the pin names at the bottom of the board under the U_DEBUG header.

### 6.1.2 SJTAG debug

The second interface is the Serial JTAG (SJTAG) one-wire interface. It works with various external JTAG debugger dongles through a Freescale-defined FPGA/CPLD. SJTAG supports the Green Hills Slingshot and ETM probe debugger dongles, as well as those made by ARM, Abatron, and Lauterbach.

Note that the SJTAG interface comes without plastic header mounted.

The HW_DIGCTL_CTRL_USE_SERIAL_JTAG bit in the digital control block selects whether the one-wire serial JTAG interface or the alternative six-wire parallel JTAG interface is used. There are other options in the digital control block which might interest you and our advice is to check the iMX233's datasheet released by Freescale.

SJTAG

Pin # | Signal Name | Processor Pin #
1 | 3.3VREG | -
2 | GND | 30, 35, 98, 105, 112, 118
3 | SJTAG_PSW | 119
4 | DEBUG | 84

The pin names are also written at the bottom of the board for your convenience.

### 6.1.3 Classic JTAG debug

The third option is to use the classic 6-pin parallel JTAG (not including GND and VCC). There are pads left for this option at the bottom of the board under the SD card holder. They are named individually and framed near a “JTAG” name.

The important thing is that these pins are multiplexed with the SD card signals. In order to use the 6-pin JTAG you will have to stop using the SD card. Note also that the classic JTAG interface comes without plastic header mounted so in order to use it you will need to use wires for connection.

Consider the the software settings required to switch from SJTAG to 6-pin JTAG and vice verse referring to the iMX233 manual. For instance:

The HW_DIGCTL_CTRL_USE_SERIAL_JTAG bit in the digital control block selects whether the serial JTAG interface or the alternative six-wire parallel JTAG interface is used.

HW_DIGCTL_CTRL_USE_SERIAL_JTAG – 0×0 – Selects whether the one-wire serial JTAG interface or the alternative six-wire parallel JTAG interface is used. 0 = Parallel six-wire JTAG is enabled and is mapped to a collection of module pins that must be enabled by programming their MUXSEL bits in the pin control block. 1 = Serial JTAG is enabled and uses the dedicated DEBUG pin. The ROM bootcode writes this field prior to enabling JTAG, selecting which type of JTAG pin signaling to use. OLD_JTAG = 0×0 Use six-wire parallel JTAG mode. SERIAL_JTAG = 0×1 Use one-wire serial JTAG mode.

It is good idea to check the datasheet of the iMX233 processor for all the options in the digital control block. The processor's datasheet should be always the first piece of paper you consult when dealing with electronics.

Classic JTAG (multiplexed with SD card)

Pin # | Signal Name | Processor Pin #
1 | SSP1_DATA1 | 85
2 | SSP1_DATA0 | 84
3 | GND | 30, 35, 98, 105, 112, 118
4 | SSP1_SCK | 90
5 | SD_VCC | -
6 | SSP1_CMD | 83
7 | SSP1_DATA3 | 87
8 | SSP1_DATA2 | 86

Notice that the pad numeration is written at the bottom of OLinuXino-MAXI under the microSD card connector. Please check the manual part for microSD card for a schematic of the pins.

### 6.2 SD/MMC slot

The microSD card slot is a standard 8pin connector.

We have tested a number of microSD cards on the OLinuXino boards and all of them worked fine regardless manufacturer or capacity. However, keep in mind that some of the lower quality microSD cards might draw too much current from the slot which might cause power-state problems. If you suspect the microSD card is causing problems please try using another one of better quality for better results.

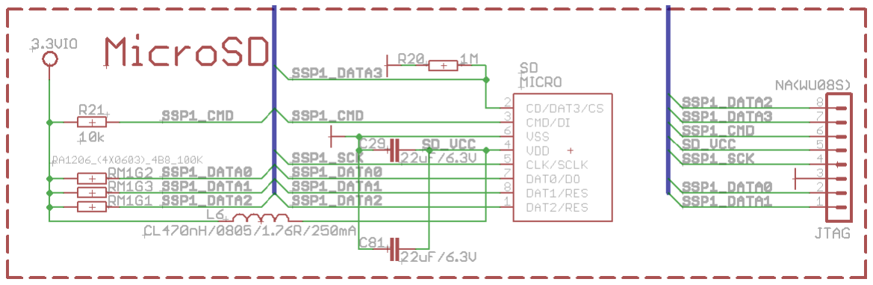
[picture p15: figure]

microSD card connector

Pin # | Signal Name | Processor Pin #
1 | SSP1_DATA2 | 86
2 | SSP1_DATA3 | 87
3 | SSP1_CMD | 83
4 | SD_VCC | -
5 | SSP1_SCK | 90
6 | GND | 30, 35, 98, 105, 112, 118
7 | SSP1_DATA0 | 84
8 | SSP1_DATA1 | 85

Notice that the pad numeration is written at the bottom of OLinuXino-MAXI under the microSD card connector.

When removing the card, please make sure that you release it from the connector by pushing and NOT by pulling the card directly (this can damage both the connector and the microSD card).

### 6.3 UEXT module

OLinuXino board has UEXT connector and can interface Olimex's UEXT modules.
For more information on UEXT please visit:

https://www.olimex.com/Products/Modules/UEXT/resources/UEXT_rev_B.pdf

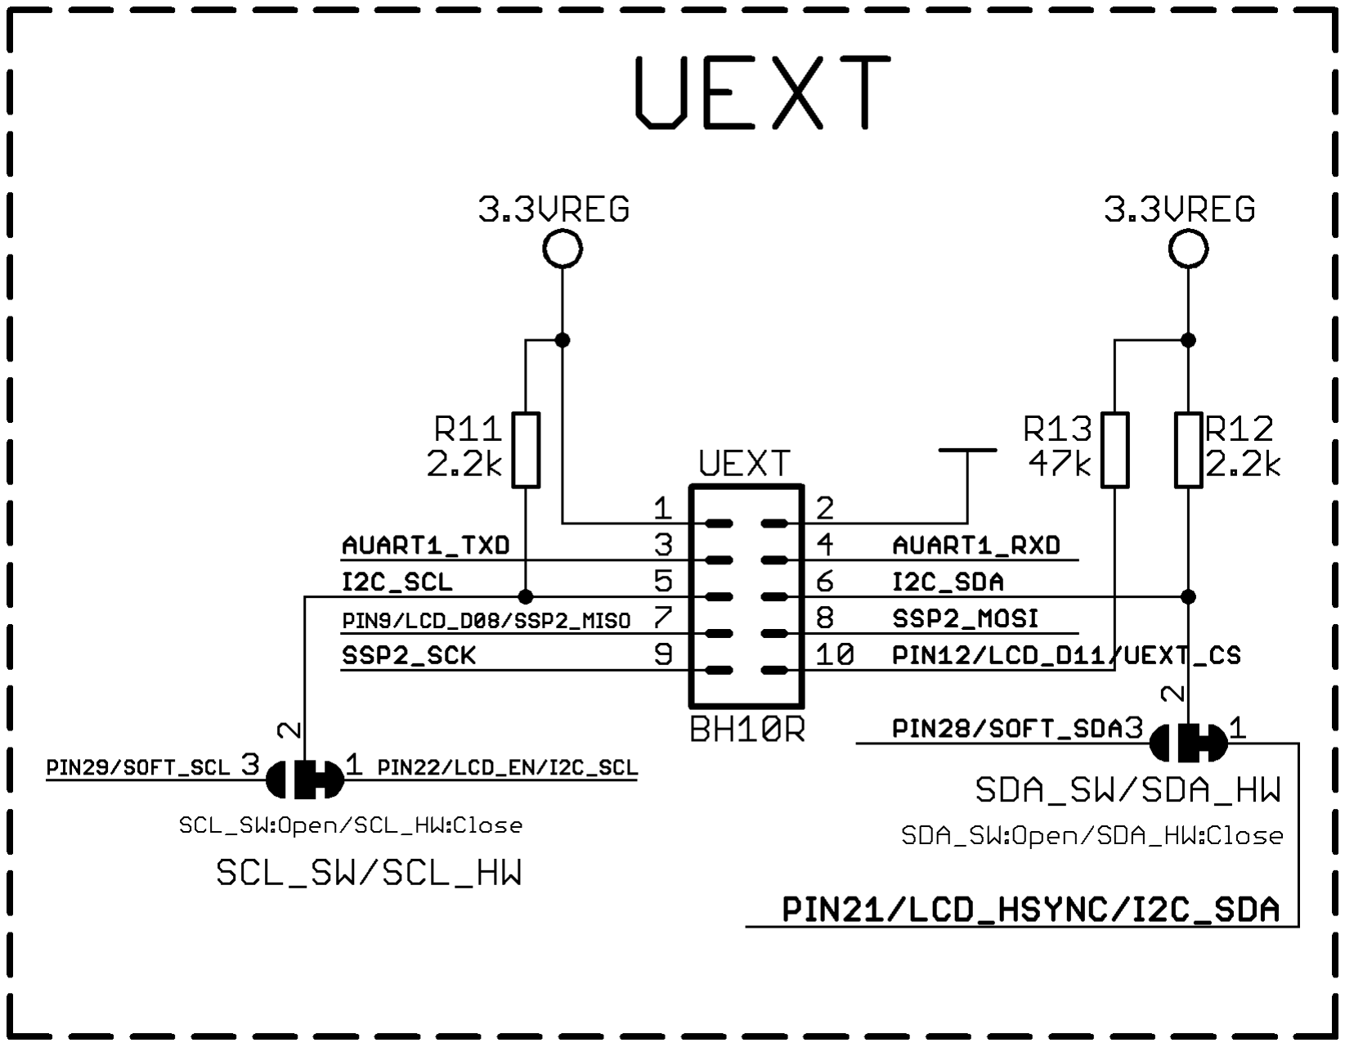
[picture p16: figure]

*Note the two jumpers PIN29/SOFT_CL – PIN22/LCD_EN/I2C_SCL, and PIN28/SOFT_SDA3 – PIN21/LCD_HSYNC/I2C_SDA which by default are set to hardware I2C. They can be used to set the I2C UEXT to a software I2C.

UEXT connector

Pin # | Signal Name | Processor Pin #
1 | +3.3VREG | -
2 | GND | -
3 | AUART1_TXD | 127
4 | AUART1_RXD | 128
5 | I2C_SCL | 34(default) OR 11*
6 | I2C_SDA | 31(default) OR 15*
7 | PIN9/LCD_D08/SSP2_MISO 22
8 | SSP2_MOSI | 21
9 | SSP2_SCK | 33
10 | PIN12/LCD_D11/UEXT_CS | 25

The UEXT pinout is also printed at the bottom of the board under the connector.

### 6.4 GPIO (General Purpose Input/Output) 40pin connector

The GPIO pins are led out on a separate 40pin connecter. They allow the user to attach additional hardware, check readings or perform hardware debug. The “GPIO Pin#” column shows connector number and does NOT represent the naming on the bottom of the board.

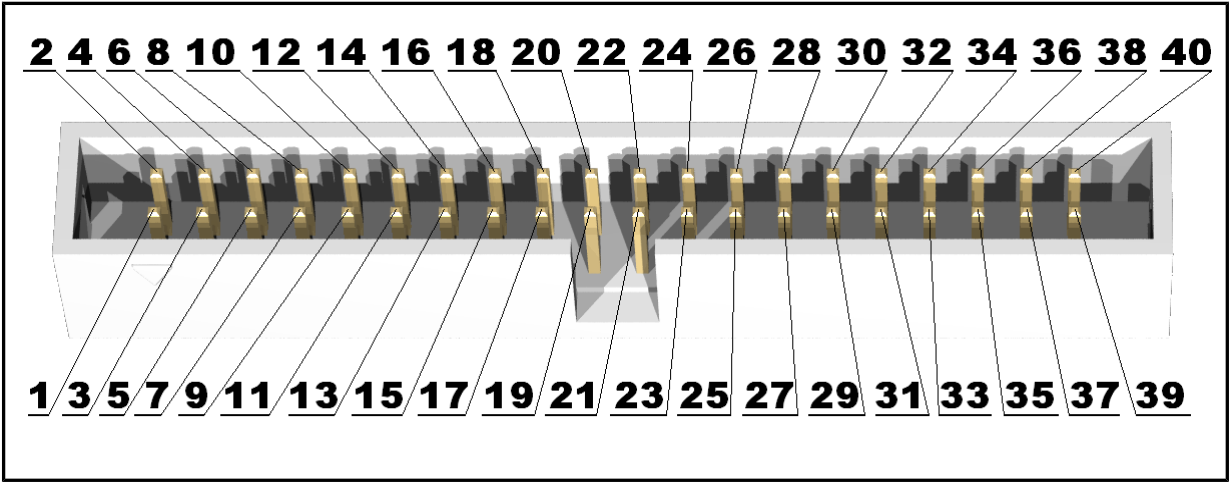
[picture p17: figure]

GPIO connector hardware

GPIO Pin# | Signal Name | Processor pin# | GPIO Pin# | Signal Name | Processor pin#
2 GND 10 PIN21/LCD_HSYNC/ | 30, 35, 98,
GPIO Pin# | Name | Processor pin# | GPIO Pin# | Name | Processor pin#
1 | BAT | 103 | 21 | PIN8/LCD_D07 | 9
| | 105, 112, 118 | 22 | PIN27/PWM2 | 91
3 | PIN17/LCD_D16 | 19 | 23 | PIN7/LCD_D06 | 8
4 | PIN18/LCD_D17/LAN_RES 20 | 24 | PIN28/SOFT_SDA | 31
5 | PIN16/LCD_D15 | 28 | 25 | PIN6/LCD_D05 | 7
6 | PIN19/LCD_DOTCLK | 17 | 26 | PIN29/SOFT_SCL | 34
7 | PIN15/LCD_D14 | 29 | 27 | PIN5/LCD_D04 | 6
8 | PIN20/LCD_VSYNC | 16 | 28 | PIN30 | 81
9 | PIN14/LCD_D13 | 26 | 29 | PIN4/LCD_D03 | 5
| I2C_SDA | 15 | 30 | PIN31 | 82
11 | PIN13/LCD_D12 | 27 | 31 | PIN3/LCD_D02 | 4
12 | PIN22/LCD_EN/I2C_SCL | 11 | 32 | PIN32/LRADC1 | 107
13 | PIN12/LCD_D11/UEXT_CS 25 | 33 | PIN2/LCD_D01 | 3
14 | PIN23/LCD_DISP | 12 | 34 | PIN33/LRADC0 | 108
15 | PIN11/LCD_D10 | 24 | 35 | PIN1/LCD_D00 | 2
16 | PIN24/LCD_WR | 13 | 36 | PIN34/MIC | 116
17 | PIN10/LCD_D09 | 23 | 37 | +5VUEXT | 102
18 | PIN25/LCD_RS | 14 | 38 | 3.3VREG | -

### 19 PIN9/LCD_D08/

| SSP2_MISO | 22 | 39 | VIN | -
20 | PIN26/LCD_CS | 10 | 40 | GND | 30, 35, 98, 105, 112, 118

The hardware is associated differently in the Linux following the GPIO naming conventions suggested in the iMX233 datasheet. You can check the connection between Linux naming of the pin, Olimex naming of the pin and the consecutive connector pin number in the table below. The ones filled with “Not implemented” doesn't have Linux support by the time of writing and will be updated overtime. “Linux GPIO” is the one you should use in Linux (the one in the datasheet); “OLinuXino name” is the pin as written on the bottom of the board. ”OLinuXino GPIO Connector

#” is the consecutive number of pins with BAT being Pin#1 and GND#40.

Note that if “OLinuXino Name” starts with P and then is followed by a number X, the PX is the name written on the bottom of the board (under the connector) with white ink. If “OLinuXino Name” is other text it is a signal used for the hardware of the board but still can be controller by the Linux (it can't be found at the GPIO connector though).

The Linux implementation of pins Linux
GPIO/iMX2

### 33 GPIO

| OLinuXino Name | OLinuXino GPIO
| | Connector # | Linux
| | | GPIO/iMX2
| | | 33 GPIO | OLinuXino
| | | | Name | OLinuXino GPIO
| | | | | Connector #
0 | PIN9 | 19 | 32 to 39 | Not
implemented Not implemented
1 | PIN10 | 17 | 51 | PIN25 | 18
2 | PIN11 | 15 | 52 | PIN24 | 16
3 | PIN12 | 13 | 53 | PIN26 | 20
4 | PIN13 | 11 | 55 | PIN22 | 12
5 | PIN14 | 9 | 56 | PIN21 | 10
6 | PIN15 | 7 | 64 | JTAG_TDO1
| | | | SSP1_CMD | Not implemented
7 | PIN16 | 5 | 65 | LED1 | Not implemented
16 | PIN17 | 3 | 91 | PIN30 | 28
17 | PIN18 | 4 | 92 | PIN31 | 30
19 | TEST_PAD | Not implemented
20 | UEXT_SPI2_MOSI | 9
23 | PIN29 | 26
24 | UEXT_SPI2_SCK | Not implemented
25 | PIN28 | 24
30 | UEXT_TX1 | Not implemented
31 | UEXT_RX1 | Not implemented

Below you can find the GPIO_CON as seen in the schematic:

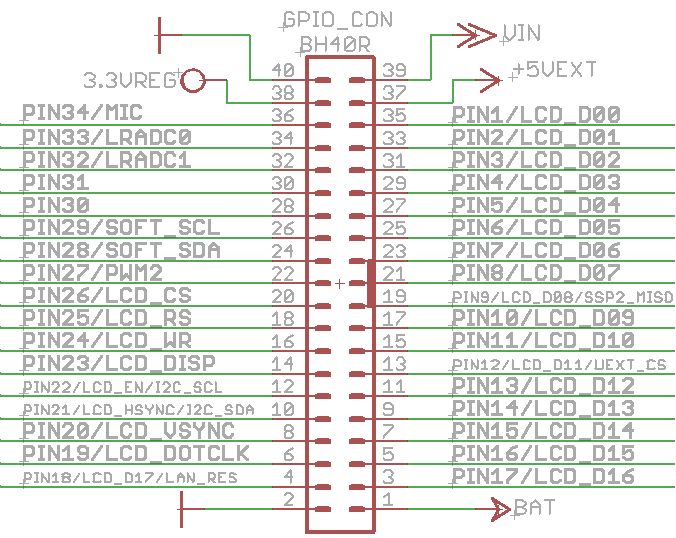
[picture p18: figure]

When looking at the bottom of OLinuXino-MAXI near the GPIO connector there is also an additional GND pad named GND_PIN which is a fast way to have access to a ground signal.

### 6.5 USB HOSTs

The USB hosts and the Ethernet are controller by a single chip (LAN9512) which handles both functionality.

The LAN9512 contains a Hi-Speed USB 2.0 hub with two fully-integrated downstream USB 2.0 PHYs, an integrated upstream USB 2.0 PHY, a 10/100 Ethernet MAC/PHY controller, and an EEPROM controller. It offers SMSC's highest level of USB 2.0 and 10/100 Ethernet compliance and interoperability. Additionally, the LAN9512 devices simplify system design by leveraging the existing USB stack and reducing the PCB footprint by up to 65% compared to discrete competitive solutions. USB-based networking technology offers a cost-effective and smart design alternative to traditional PCI/PCI-Express networking solutions due to the flexibility of routing and placement of Ethernet and USB connectivity ports.

The big advantage of having USB hosts available over USB devices is that you can use them to power devices.

The signals follow the familiar and standard USB host pattern:

USB 2-level host

PIN# | SIGNAL NAME
1 | USB_PWR_A
2 | USB_HOST_D-
3 | USB_HOST_D+
4 | GND

### 6.6 LAN connector

The Ethernet connectivity is handled by the LAN9512 controller (which also incorporates a USB module in it). The signals found on the Ethernet connector are listed in the table below:

LAN connector
PIN# | SIGNAL NAME
1 | TX+
2 | TX-
3 | VDD
4 | NOT CONNECTED
5 | NOT CONNECTED
6 | VDD
7 | RX+
8 | RX-

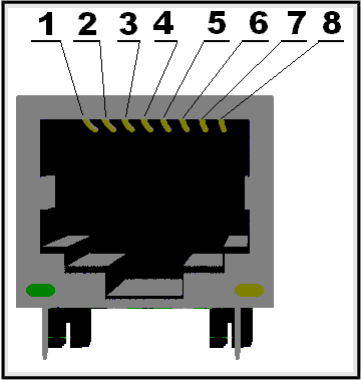
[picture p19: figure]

The two leds on the front side of the LAN connector show the state of the Ethernet. The meaning behind the different states can be found in the table below:

LED | Color | Usage
Right | Green | Link status
Left | Yellow | Activity status

### 6.7 PWR Jack

The power jack used is the typical 2.5mm one used by Olimex in most of our products. You should provide between 6 and 16 volts @ 1A to the board.

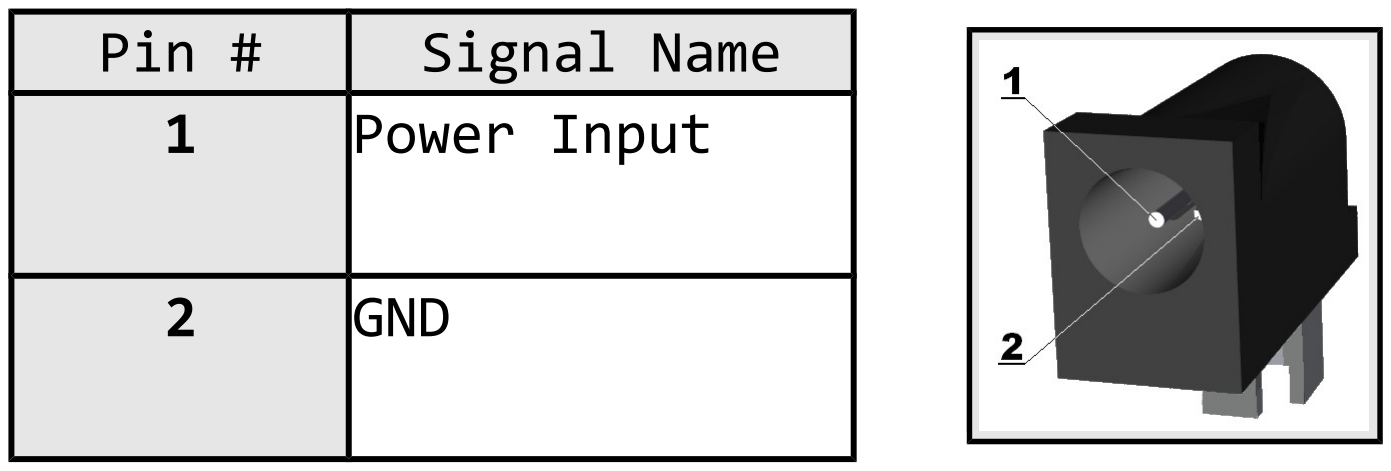
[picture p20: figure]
Pin #; Signal Name; 1 Power Input; 2 GND

More info about the power supply can be found in chapter 5 of this manual

### 6.8 Headphones and line-in connector

Standard audio jack and phone jack are mounted for the audio interfacing.

Headphones/Audio out connector
Pin# | SIGNAL NAME | Processor Pin#
2 | L channel | 113
3 | R channel | 109
5 | GND | GND pins

The headphones resistance is 16 Ohms!

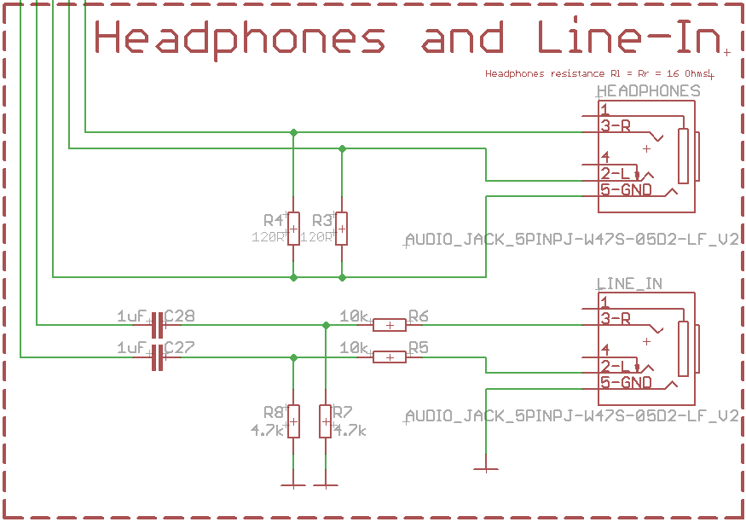
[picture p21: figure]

### 6.9 Battery connector

When using the battery connector keep in mind that it is an energy solution that wouldn't be able to power the board and all the peripherals. The voltage of a 3.7V LIPO battery would be enough to power the processor and the memory but won't be enough to power the LAN and the USB hosts.

Pin # | Signal Name

### 1 VBAT

### 2 GND

The pins are also written on the top of the board in the base of the connector.

### 6.10 Composite video connector

The composite video is the connector you should use if you wish OLinuXino-MAXI video output on a monitor.

The whole signal is controlled by pin #104 from the iMX233 processor.

The + signal is lead to the middle of the connector. The outside part is the GND.

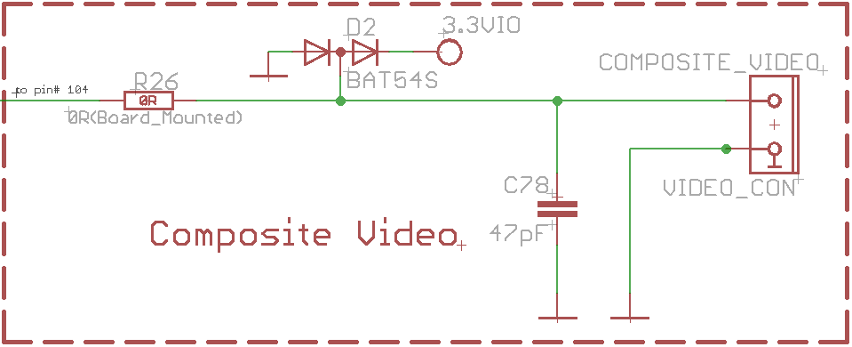
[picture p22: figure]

### 6.11 Boot mode positions

The iMX233 can boot the operating system from different locations. The default location for the Linux files we used is the microSD card. There are 4(four) jumpers responsible for the boot location: D03, D02, D01 and D00. They are located on the top of the board between the processor and 40pin GPIO connector. Note that the jumpers are SMD type and opening a jumper would require cutting, closing a jumper would require soldering. To be able to do the quoted operations you will need basic engineering skills and experience. You can check below the table or the schematic for the correct positions. Value of “1” means the jumper is closed.

BOOT MODE D03 | d02 | d01 | d00
USB 0 | 0 | 0 | 0
3.3V I2C Master 0 | 0 | 0 | 1
33.3V SPI Flash 1 Master 0 | 0 | 1 | 0
3.3V SPI Flash 2 Master 0 | 0 | 1 | 1
3.3V NAND 0 | 1 | 0 | 0
Start up waits for JTAG
debugger connection 0 | 1 | 1 | 0
3.3V SD/MMC 1 (Default!!!) 1 | 0 | 0 | 1
3.3V SD/MMC 2 1 | 0 | 1 | 0

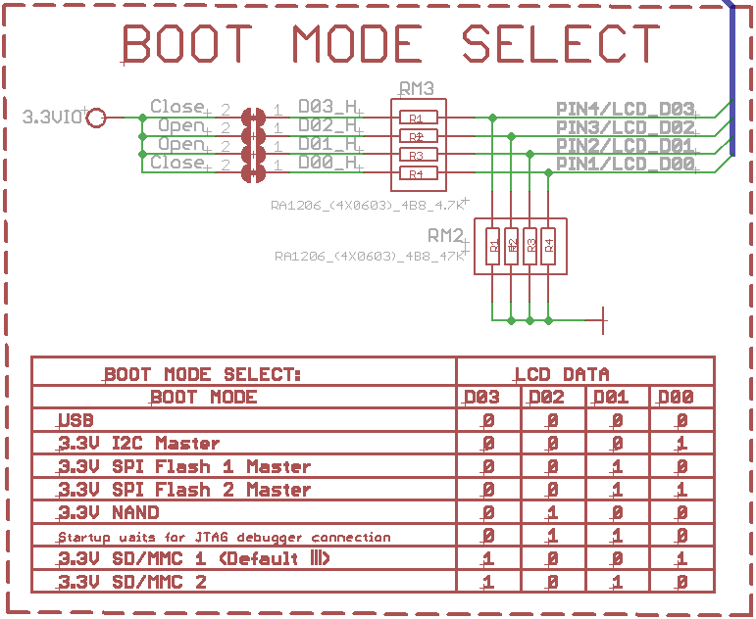
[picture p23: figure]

### 6.12 Jumper description

Please note that all the jumpers on the board are SMD type. If you feel insecure of your soldering/cutting technique it is better not to try to adjust the jumpers.

### 6.12.1 SCL_SW/SCL_HW and SDA_SW/SDA_HW

Those two jumpers must be moved together – there are two available options – configuring software I2C interface (SCL_SW, SDA_SW) or hardware I2C interface (SCL_HW, SDA_HW positions).

Jumpers are set to SCL_HW and SDA_HW by default. This defines hardware I2C.

6.12.2 5V_E

The 5V_E jumper allows control over the powering line. If you want to disable the 5V powering line open 5V_E jumper.

The default position is closed.

6.12.3 3.3V_E and 3.3VIO_E jumpers

Important these jumpers must be moved together! Closing both of 3.3V_E and 3.3VIO_E at the same time will damage the processor. One of them has to be open (unsoldered/cut). There are two possible positions:

1) 3.3V_E closed (soldered), 3.3VIO_E open (unsoldered/cut)
2) 3.3V_E open (unsoldered/cut), 3.3VIO_E closed (soldered)

In the default variant 1) the board uses the mounted by OLIMEX DC-DC 3.3V convertor which when the board is powered by external supply is the better alternative. However, if you use battery it will not power the chip handling the USB and the LAN functionality. Basically the board will lack USB-HOSTs and LAN when jumpers are set in variant 1) and the board is powered by a battery via the BAT connector.

If you set the jumpers in 2) state the board's 3.3V will be handled by the built-in iMX233 DC-DC but the problem is it isn't configured to be used with another chip so it doesn't provide enough current for all the USB-HOSTs and the LAN which might cause some of the devices plugged in the USB to lack power and also might burn the chip if too much current is drawn. However, in this 2) mode of jumpers it is possible to power the board from a battery and still have some current on the USB-HOSTs and the LAN. The maximum current the built-in DC-DC can provide safely is 200mA.

### 6.12.4 Boot mode selecting jumpers

These jumpers are discussed in chapter 6.11 of this manual.

### 6.13 Additional hardware components

The components below are mounted on OLinuXino but are not discussed above. They are listed here for completeness:

Reset button – used to reset the board

Power button – when Linux is running pressing PWR_BUT will put the board in low power mode; when powered by battery PWR_BUT is used to initially power up the board – and pressing the board again after it is powered will put it low power mode

Recovery pads (REC) - these can be used for attaching a recovery button; when powered by battery the recovery button is used to bring the processor to normal power mode – you can short-circuit the pads for this feature without having to mount a button

512 (32M x 16) MBit DDR SDRAM – the exact memory used at the moment of writing is Xylinx H5DU5xxxyyy

LED1 + Power LED

### 6.14 Accessories

Here you will find additional information for Olimex products you can use with OLinuXino-MAXI purchase

### 6.14.1 USB-SERIAL-CABLE-F

The cable for the U_DEBUG interface that can be purchased for additional cost has three cables. It is important to specify in your purchase order whether you want the USB-SERIAL-CABLE variant with male a male or female connectors.

You will need a drivers that can be downloaded from the page of USB-SERIAL-CABLE: https://www.olimex.com/Products/Components/Cables/USB-Serial-Cable/USB-Serial-Cable-F/.

### CHAPTER 7: BLOCK DIAGRAM AND MEMORY

### 7. Introduction to the chapter

On the next page you can find a memory map for this family of processors. It is strongly recommended to refer to the original datasheet released by Freescale for one of higher quality.

### 7.1 Memory addresses

Below is the table with some of the most frequently used addresses. For full list of addresses check the manual released by Freescale (Chapter Memory Map).

Decode block | Device | Mnemonic | Start address | End address | Size
AHB | On-chip RAM | OCRAM | 0×00000000 | 0×00007FFF | 32KB
| On-chip RAM alias | OCRAM | 0×00008000 | 0×3FFFFFFF
| External memory | | 0×40000000 | 0×5FFFFFFF | 512MB
| Default Slave | | 0×60000000 | 0×7FFFFFFF | 512M

### 7.2 Processor block diagram

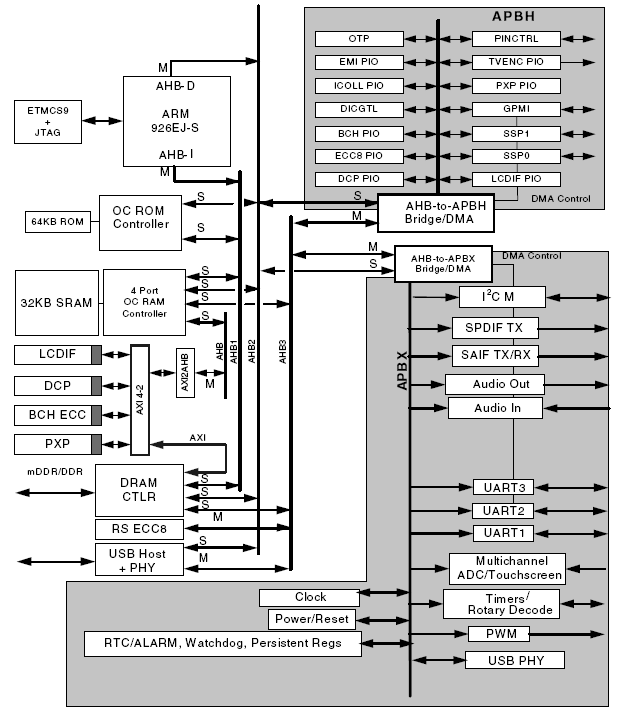
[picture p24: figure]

### 7.3 Physical memory map

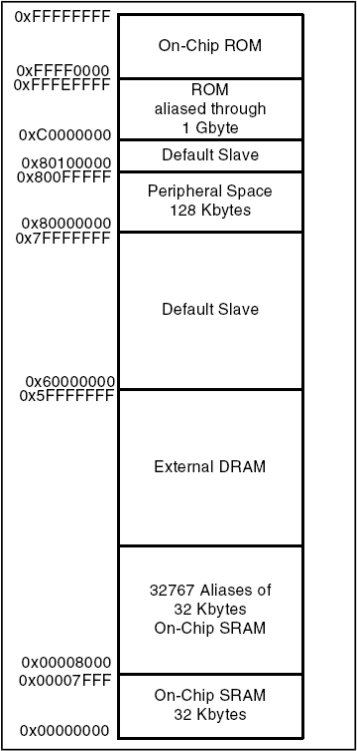
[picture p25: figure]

### CHAPTER 8: SCHEMATICS

### 8. Introduction to the chapter

In this chapter are located the schematics describing logically and physically OLinuXino.

### 8.1 Eagle schematic

OLinuXino schematic is visible for a reference here. You can also find it on the GitHub for OLinuXino at our site: https://www.olimex.com/Products/OLinuXino/iMX233/iMX233-OLinuXino-MAXI/. (https://www.olimex.com/Products/OLinuXino/iMX233/iMX233-OLinuXino-MAXI/) The link to the GitHub is located in HARDWARE section.

The EAGLE schematic is situated on the next page for quicker reference.

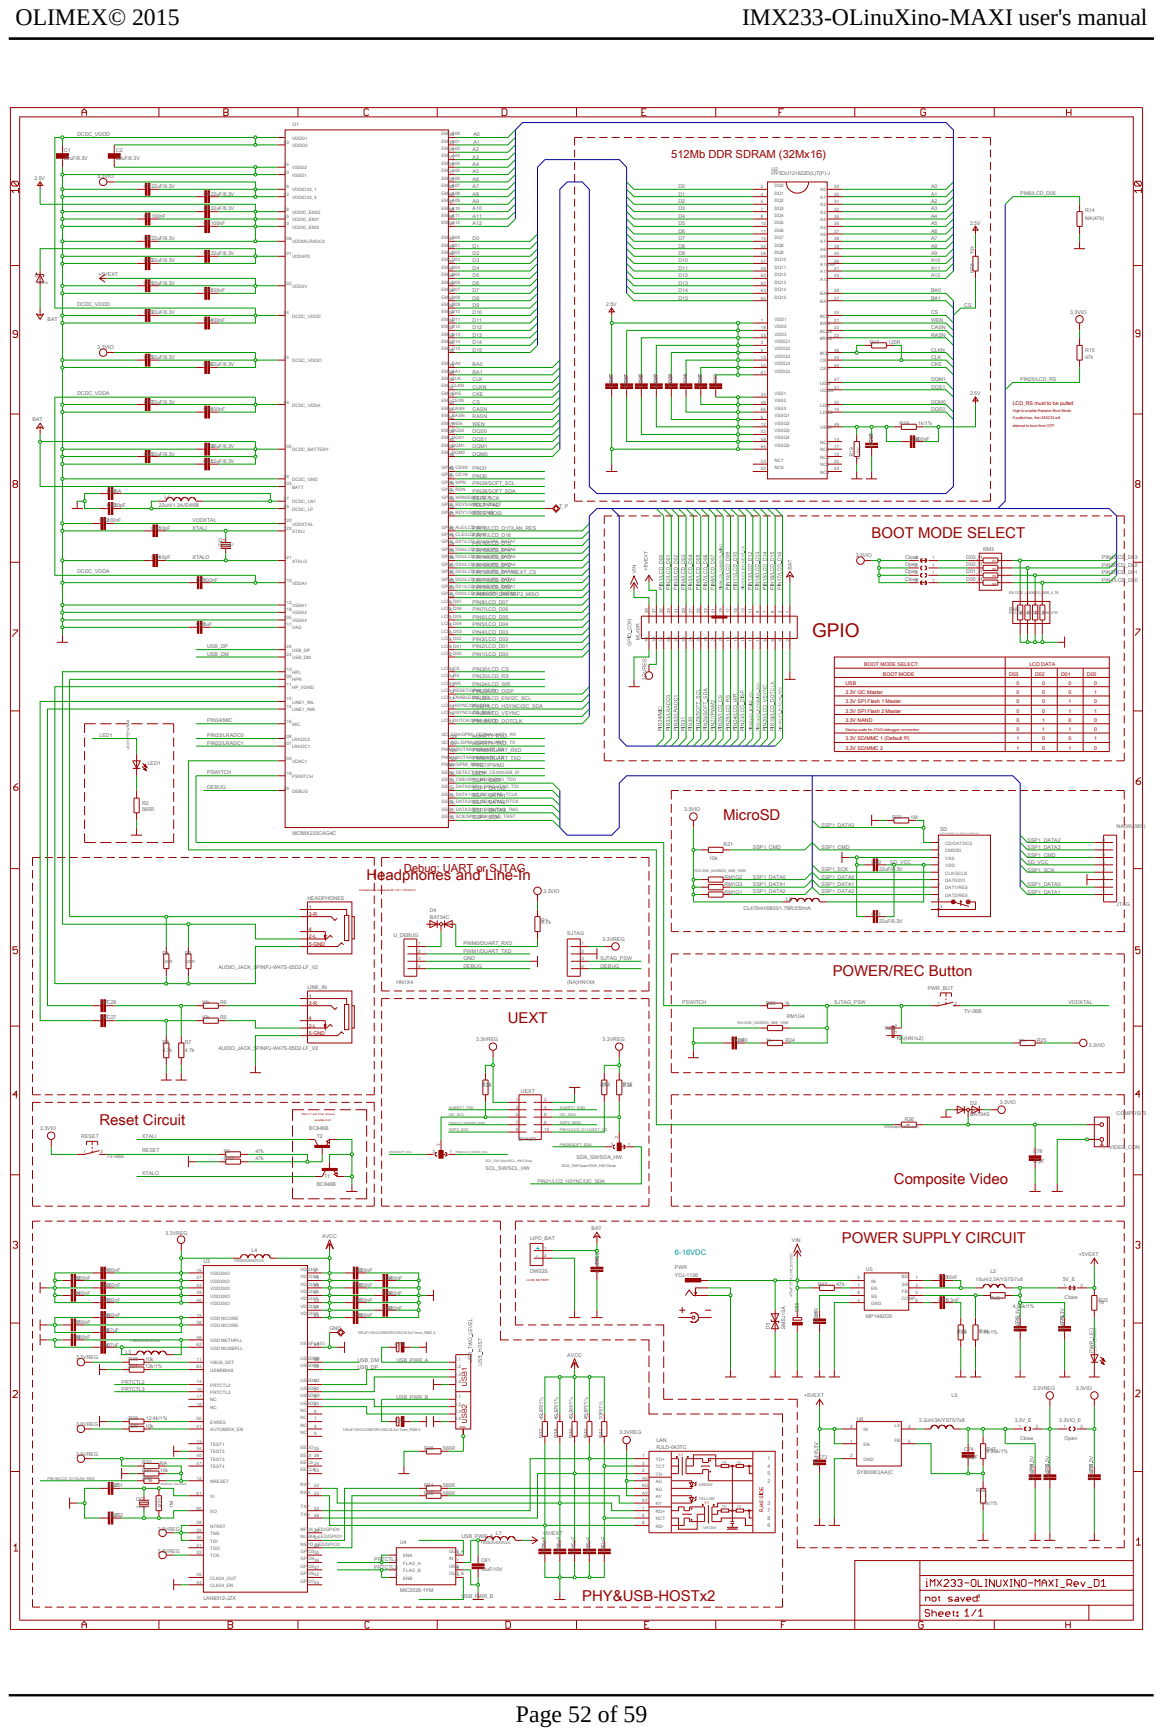
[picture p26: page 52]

LCD_RS must to be pulled

High to enable Resistor Boot Mode.
If pulled low, the i.MX233 will
attempt to boot from OTP.

Startup waits for JTAG debugger connection
3.3V SD/MMC 1 (Default !!!)
3.3V SD/MMC 2

Debug: UART or SJTAG
Headphones and Line-In

Headphones resistance Rl = Rr = 16 Ohms!

### 8.2 Physical dimensions

Note that all dimensions are in inches.

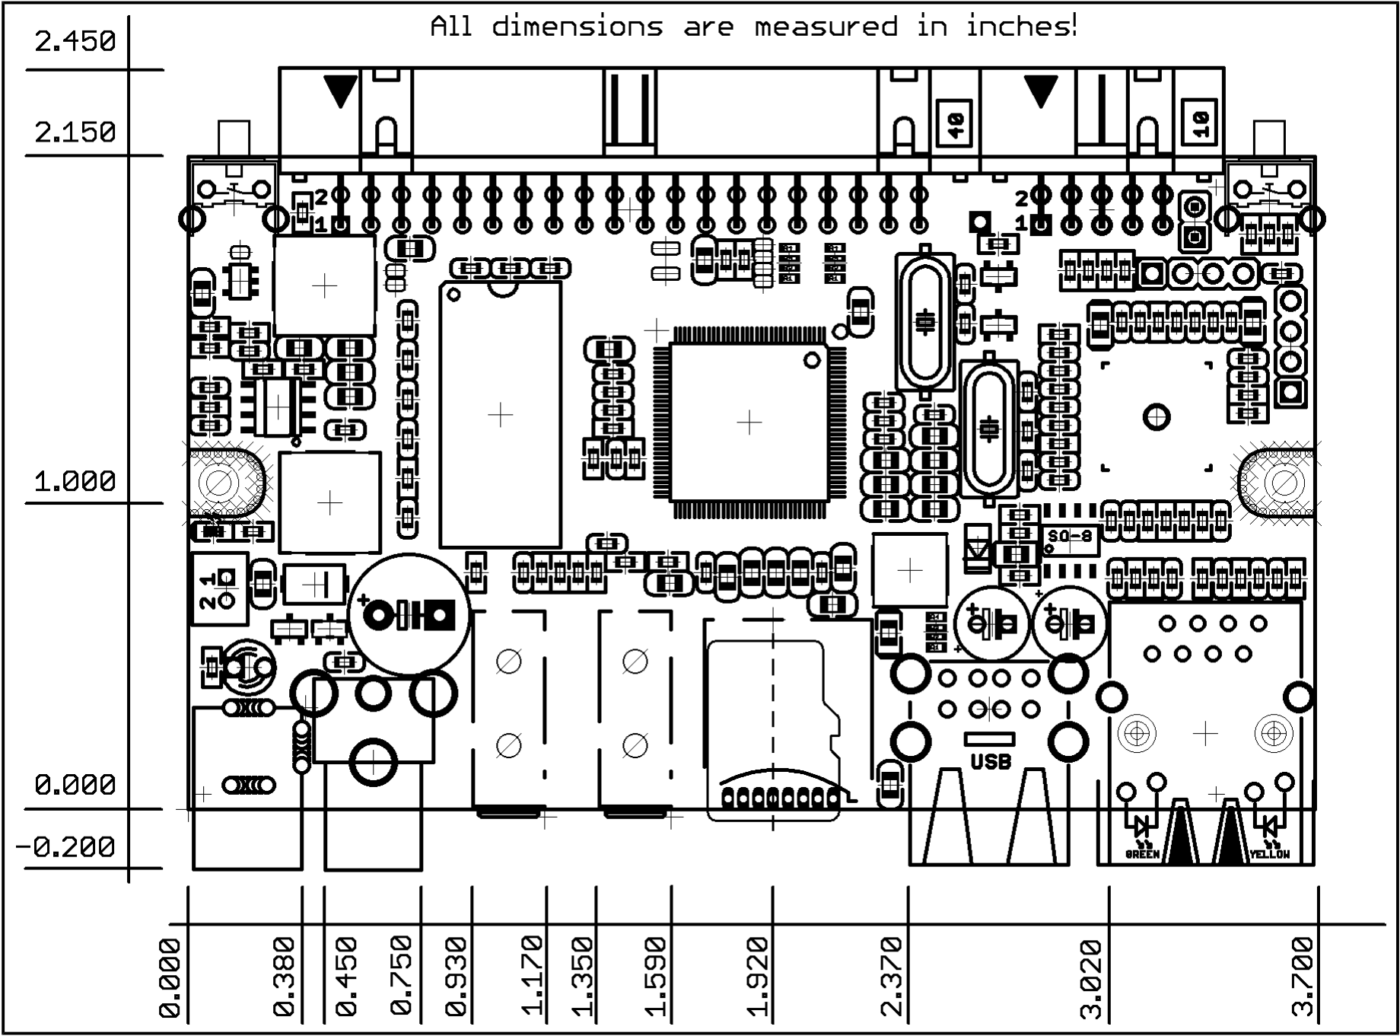
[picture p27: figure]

The three highest elements on the board in order from the tallest to the shortest are: inductor L2; USB host connector; Ethernet/LAN connector.

### CHAPTER 9: REVISION HISTORY AND SUPPORT

### 9. Introduction to the chapter

In this chapter you will find the current and the previous version of the document you are reading. Also the web-page for your device is listed. Be sure to check it after a purchase for the latest available updates and examples.

### 9.1 Document revision

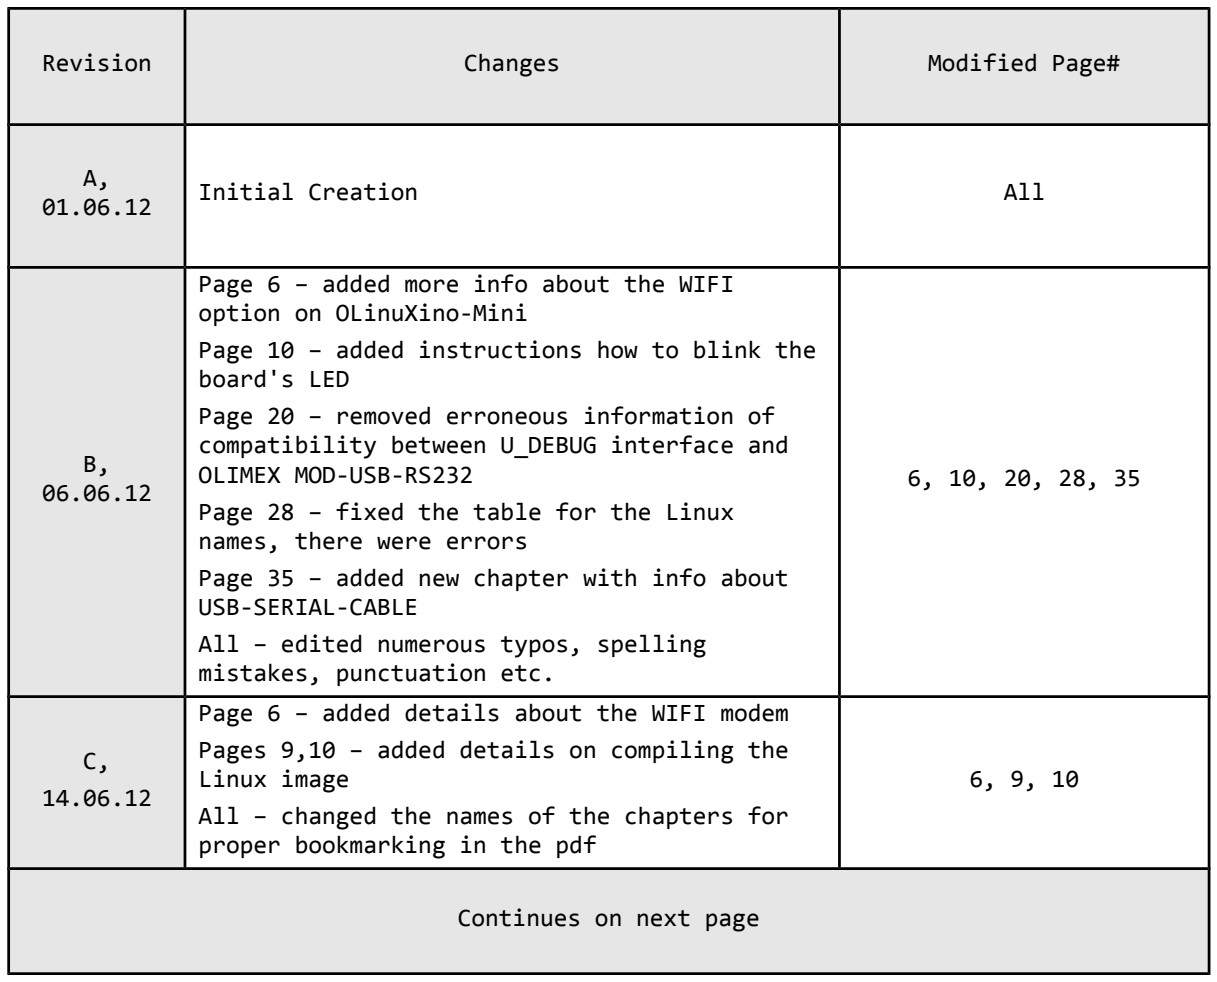
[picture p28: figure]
Revision; Changes; Modified Page#; Initial Creation; All; Page 6 – added more info about the WIFI option on OLinuXino-Mini; board's LED; compatibility between U_DEBUG interface and OLIMEX MOD-USB-RS232 Page 28 – fixed the table for the Linux names, there were errors; USB-SERIAL-CABLE All – edited numerous typos, spelling mistakes, punctuation etc.; Linux image; proper bookmarking in the pdf; Continues on next page

Page 10 – added instructions how to blink the

Page 20 – removed erroneous information of

Page 35 – added new chapter with info about

Page 6 – added details about the WIFI modem Pages 9,10 – added details on compiling the

All – changed the names of the chapters for

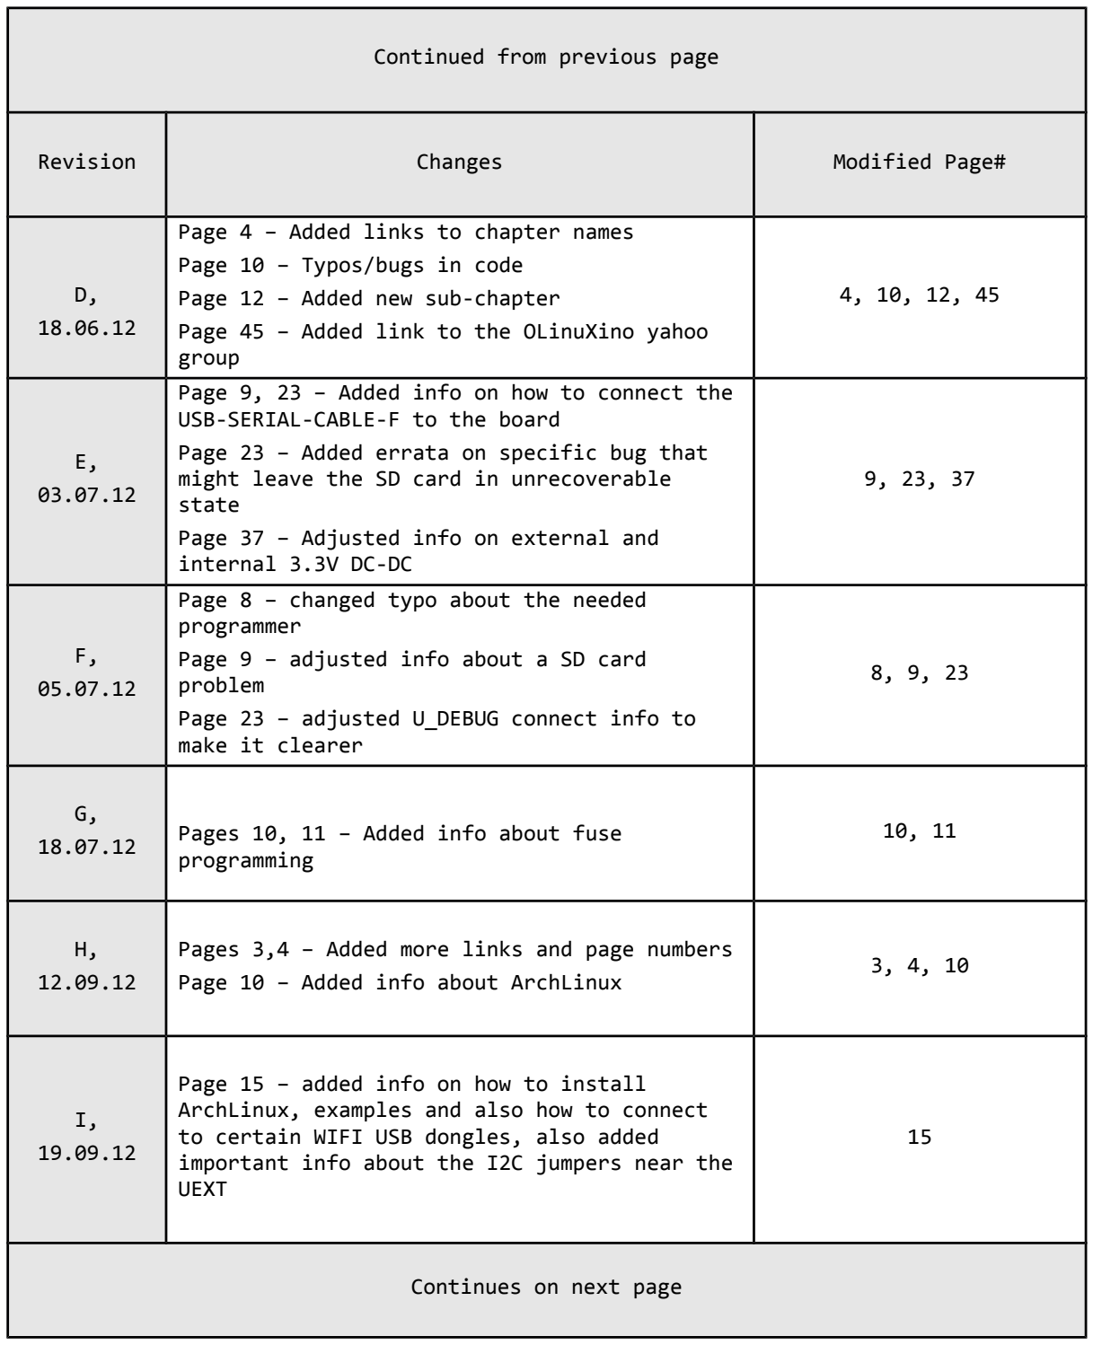
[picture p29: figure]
Continued from previous page; Revision; Changes; Modified Page#; Page 4 – Added links to chapter names Page 10 – Typos/bugs in code Page 12 – Added new sub-chapter; group; USB-SERIAL-CABLE-F to the board; state Page 37 – Adjusted info on external and internal 3.3V DC-DC; Page 8 – changed typo about the needed programmer Page 9 – adjusted info about a SD card problem; make it clearer; programming; Page 10 – Added info about ArchLinux; Page 15 – added info on how to install; to certain WIFI USB dongles, also added; UEXT; Continues on next page

Page 45 – Added link to the OLinuXino yahoo

Page 9, 23 – Added info on how to connect the

Page 23 – Added errata on specific bug that might leave the SD card in unrecoverable

Page 23 – adjusted U_DEBUG connect info to

18.07.12 Pages 10, 11 – Added info about fuse

Pages 3,4 – Added more links and page numbers

ArchLinux, examples and also how to connect

important info about the I2C jumpers near the

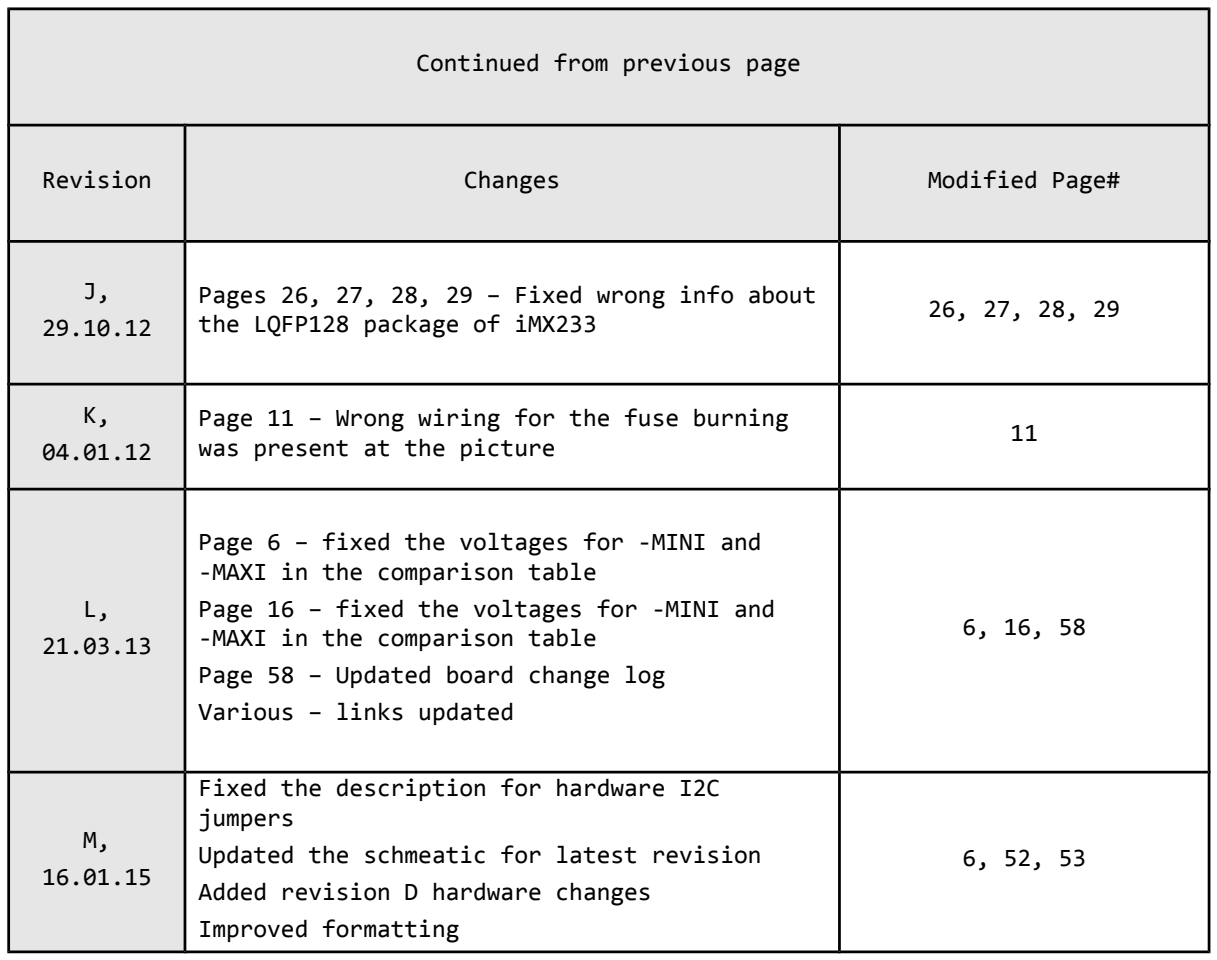
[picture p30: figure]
Continued from previous page; Revision; Changes; Modified Page#; the LQFP128 package of iMX233; was present at the picture; -MAXI in the comparison table; -MAXI in the comparison table Page 58 – Updated board change log Various – links updated; Fixed the description for hardware I2C jumpers; Added revision D hardware changes Improved formatting

Pages 26, 27, 28, 29 – Fixed wrong info about

Page 11 – Wrong wiring for the fuse burning

Page 6 – fixed the voltages for -MINI and

Page 16 – fixed the voltages for -MINI and

Updated the schmeatic for latest revision

### 9.2 Board revision

Revision | Notable Changes
B | Initial release of the board
B1 | R14 removed

C

1. Renamed from iMX233-OLINUXINO_Rev_C to iMX233-OLINUXINO-MAXI_Rev_C
2. BOOT jumpers moved to bottom of the board and the distance between them was increased
3. Jumpers 3.3V_E and 3.3VIO_E moved to bottom and the distance between them was increased
4. Jumpers SW_SCL/HW_SCL and SW_SCK/HW_SCK were made bigger and default position moved to hardware I2C
5. 5V_E jumper moved to bottom
6. The FET located in parallel to power supply was removed
7. Q2 moved away from D1
8. The 40pin GPIO connector symbol was edited so it represents reality (not symmetrical cut)
9. PWR_JACK and RCA connectors separated further
10. R1 changed from 100k to 4.7k because a Schottky
diode is added on the RX line

C1 C23 and C24 changed from 33pF to 15pf

D

1. Replaced the package of the microSD card with an easier to place one
2. Fixed the accidentally mirrored LiPo print at the bottom
3. Changed C23, C24 to 10pF from 4.7pF. The 4.7pF capacitors allow better start of the board but affect the video output quality since the frequency gets disturbed. 10pF is a good compromise.

D1

After some series changed C83 to 20pF (from 100pF). The problem was that the Debian 3.11 image does not recognize mass storage drive. Other USB devices can be recognized. The capacitor value is critical because if 100pF is placed the board starts better on battery, but does not recognize any mass storage drive. IF 10pF is placed – the mass storage drive is recognized but the board starts more difficult only with battery supply. So the compromise is 20 pF.

### 9.3 Useful web links and purchase codes

The web page you can visit for more info on your device is https://www.olimex.com/Products/OLinuXino/iMX233/iMX233-OLinuXino-MAXI/
A place for general questions, FAQ or friendly talk: https://www.olimex.com/forum/index.php?board=1.0 (https://www.olimex.com/forum/index.php?board=1.0)
You can get the latest updates on the software at: https://github.com/OLIMEX/OLINUXINO The OLinuXino Linux images sources: https://github.com/Freescale/fsl-community-bsp-platform

ORDER CODES:

iMX233-OLinuXino-MAXI – the best version of OLinuXino featuring Ethernet controller iMX233-OLinuXino-MINI – the mini version of the single-board computer iMX233-OLinuXino-MICRO – tiny in size, tiny in price and perfect for breadbording

iMX233-OLinuXino-MINI-WIFI – the MINI version of OLinuXino + embedded RTL8128CU WIFI module

iMX233-OLinuXino-SD – SD card with the Linux image which can be used with every board from the OLinuXino family
MOD-WIFI_RTL8188 – external USB WIFI modem with RTL8188 chip USB-SERIAL-CABLE – USB serial console cable for U_DEBUG
SY0612E – power supply adapter 12V/0.5A for iMX233-OLinuXino-MAXI and iMX233-OLinuXino-MINI (Will not work with OLinuXino-MICRO)
SY0605E – power supply adapter 5V/1A for iMX233-OLinuXino-MICRO (Will not work with iMX233-OLinuXino-MAXI and iMX233-OLinuXino-MINI)

How to order?
You can order directly from our web shop or from any of our distributors.
Visit https://www.olimex.com/ for more info.
The full list of distributors can be found here: https://www.olimex.com/Distributors/

### 9.4 Product support

For product support, hardware information and error reports mail to: support@olimex.com. Note that we are primarily a hardware company and our software support is limited.

Please consider reading the paragraph below about the warranty of Olimex products.

All goods are checked before they are sent out. In the unlikely event that goods are faulty, they must be returned, to OLIMEX at the address listed on your order invoice.
OLIMEX will not accept goods that have clearly been used more than the amount needed to evaluate their functionality.

If the goods are found to be in working condition, and the lack of functionality is a result of lack of knowledge on the customers part, no refund will be made, but the goods will be returned to the user at their expense.

All returns must be authorized by an RMA Number. Email support@olimex.com for authorization number before shipping back any merchandise. Please include your name, phone number and order number in your email request.

Returns for any unaffected development board, programmer, tools, and cables permitted within 7 days from the date of receipt of merchandise. After such time, all sales are considered final.

Returns of incorrect ordered items are allowed subject to a 10% restocking fee. What is unaffected? If you hooked it to power, you affected it. To be clear, this includes items that have been soldered to, or have had their firmware changed. Because of the nature of the products we deal with (prototyping electronic tools) we cannot allow returns of items that have been programmed, powered up, or otherwise changed post shipment from our warehouse.

All returned merchandise must be in its original mint and clean condition. Returns on damaged, scratched, programmed, burnt, or otherwise 'played with' merchandise will not be accepted.

All returns must include all the factory accessories which come with the item. This includes any In-Circuit-Serial-Programming cables, anti-static packing, boxes, etc.

With your return, enclose your PO#. Also include a brief letter of explanation of why the merchandise is being returned and state your request for either a refund or an exchange. Include the authorization number on this letter, and on the outside of the shipping box.

Please note: It is your responsibility to ensure that returned goods reach us. Please use a reliable form of shipping. If we do not receive your package we will not be held liable.

Shipping and handling charges are not refundable. We are not responsible for any shipping charges of merchandise being returned to us or returning working items to you.

The full text might be found at https://www.olimex.com/wiki/GTC#Warranty for future reference.

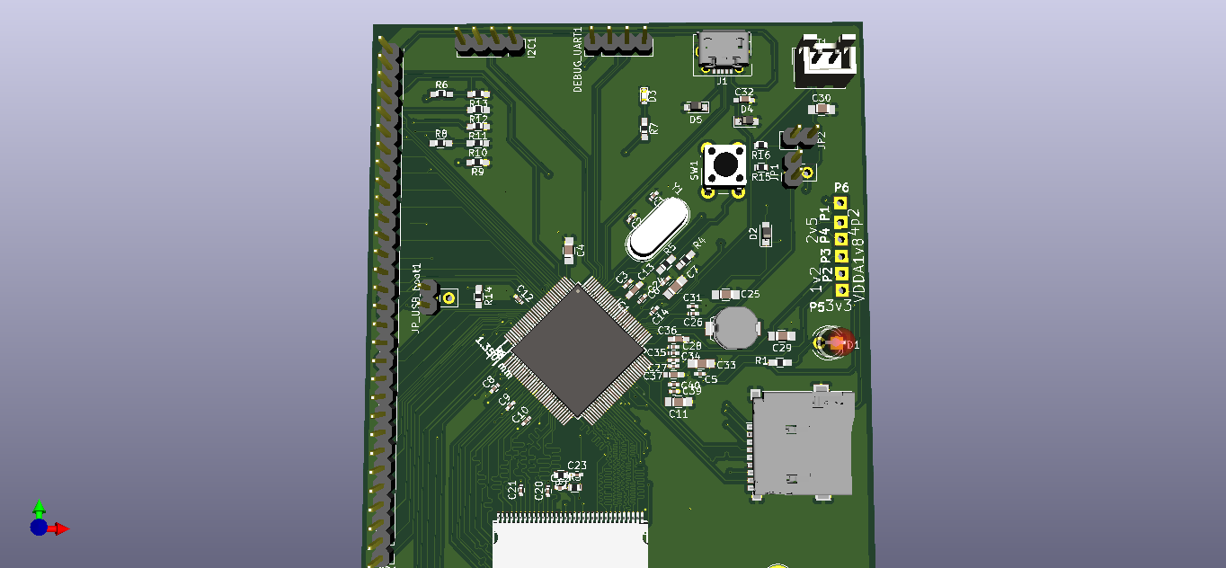
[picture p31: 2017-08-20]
plot_pcb/MyIMX233_1.1.png

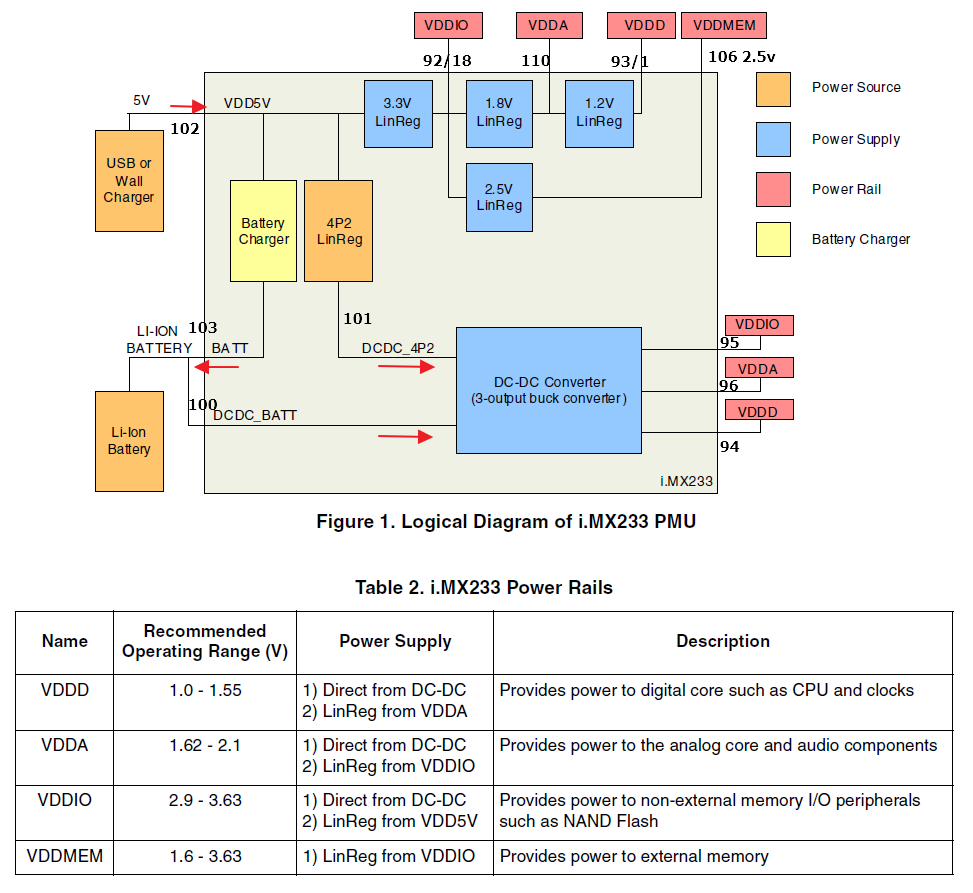
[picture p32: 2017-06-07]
ReferenceSch/PowerDiag.png

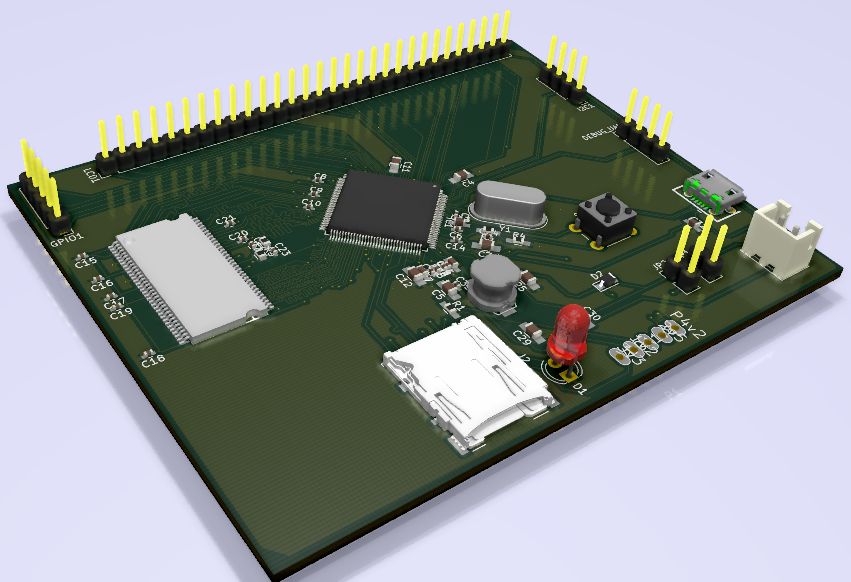
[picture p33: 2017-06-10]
plot_pcb/MyIMX233_0.3-battery_inductor.png

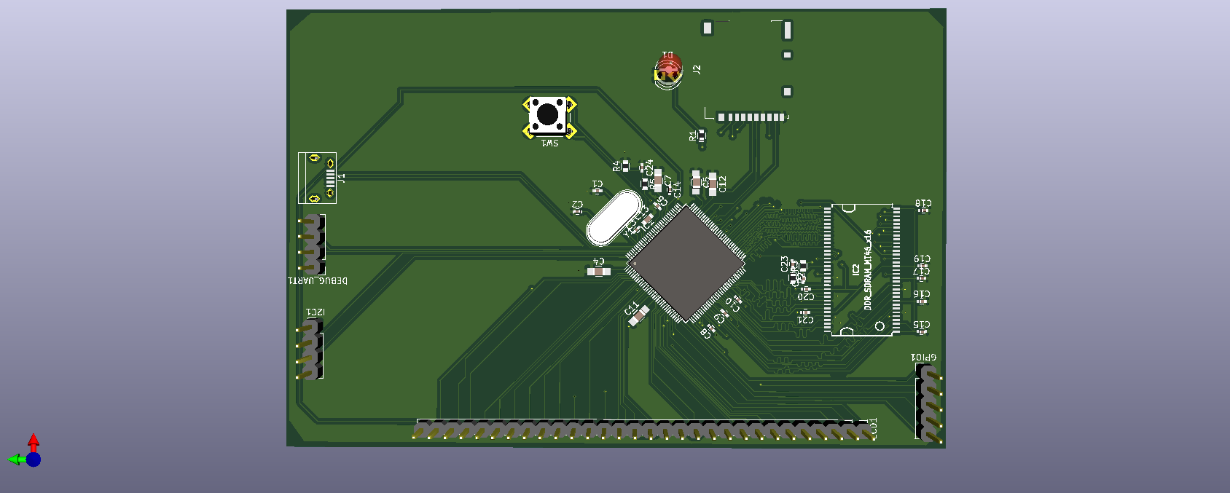
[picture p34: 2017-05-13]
plot_pcb/MyIMX233_0.1-pcb_length.png

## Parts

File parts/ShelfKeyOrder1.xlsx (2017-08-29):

SL | Quantity | Part Number | Description | Unit Price in INR | Price in INR
1 | 50 | CC0402KRX5R6BB104 | CERAMIC CAPACITOR 0.1uF(100nF) 10V 10% X5R 0402 | 1.21 | 60.5
 |  |  | SK-CC0402KRX5R6BB104
2 | 50 | CC0402KRX7R7BB103 | CERAMIC CAPACITOR 0.01uF(10nF) 16V 10% X7R 0402 | 1.1 | 55
 |  |  | SK-CC0402KRX7R7BB103
3 | 20 | CC0805KKX7R7BB106 | CERAMIC CAPACITOR 10uF 16V X7R 0805 | 2.34 | 46.8
 |  |  | SK-CC0805KKX7R7BB106
4 | 20 | 04023U120GAT2A | CERAMIC CAPACITOR 12PF NPO 5% 25V 0402 | 1.1 | 22
 |  |  | SK-04023U120GAT2A
5 | 20 | 04025A180JAT2A | CERAMIC CAPACITOR 18PF 50V 5% NP0 0402 | 1.95 | 39
 |  |  | SK-04025A180JAT2A
6 | 46 | CC0805MKX5R8BB226 | CERAMIC CAPACITOR 22UF 25V 20% X5R 0805 | 4.88 | 224.48
 |  |  | SK-CC0805MKX5R8BB226
7 | 10 | CL21A476MQCLRNC | CERAMIC CAPACITOR 47UF 6.3V 20% X5R 0805 | 8.2 | 82
 |  |  | SK-CL21A476MQCLRNC
8 | 4 | 24MHz-KDS | CRYSTAL RESONATOR 24MHZ THROUGH HOLE | 5.81 | 23.24
 |  |  | SK-24MHz-KDS
9 | 20 | 06033D105KAT2A | CERAMIC CAPACITOR 1uF 25V 10% X5R 0603 | 1.46 | 29.2
 |  |  | SK-06033D105KAT2A
10 | 30 | GRM155R61C105KE01D | CERAMIC CAPACITOR 1uF 16V 10% X5R 0402 | 1.38 | 41.4
 |  |  | SK-GRM155R61C105KE01D
11 | 11 | MMSZ5226B-7-F | ZENER DIODE 3.3V 500MW SOD123 | 3.91 | 43.01
 |  |  | SK-MMSZ5226B-7-F
12 | 15 | MM3Z5V1T1G | ZENER DIODE 5.1V 200MW SOD323 | 5.86 | 87.9
 |  |  | SK-MM3Z5V1T1G
13 | 1 | L7805CV | INTEGRATED CIRCUIT REGULATOR LDO 5V 1.5A TO220AB 7805 | 17.49 | 17.49
 |  |  | SK-L7805CV
14 | 6 | NLV32T-2R2J-PF | 2.2UH 1210 320mA WIRE WOUND CHIP INDUCTOR | 12.44 | 74.64
 |  |  | SK-NLV32T-2R2J-PF
15 | 3 | ISC1210EB220K | SHEILDED WIRE WOUND CHIP INDUCORS 22UH 1210 150mA | 16.59 | 49.77
 |  |  | SK-ISC1210EB220K
16 | 2 | NLV32T-150J-PF | 15UH 1210 130mA WIRE WOUND CHIP INDUCTOR | 12.44 | 24.88
 |  |  | SK-NLV32T-150J-PF
17 | 30 | ERJ-3EKF1001V | RESISTOR 1KOHM 1/10W 1% 0603 SMD | 0.18 | 5.4
 |  |  | SK-ERJ-3EKF1001V
18 | 20 | RC0603FR-071K5L | RESISTOR 1.5KOHM 1/10W 1% 0603 SMD | 0.33 | 6.6
 |  |  | SK-RC0603FR-071K5L
19 | 13 | ERJ-3RSFR10V | RESISTOR 0.1OHM 1% 1/10W 0603 SMD | 2.05 | 26.65
 |  |  | SK-ERJ-3RSFR10V
20 | 20 | RC0402FR-071K5L | RESISTOR 1.5KOHM 1/16W 1% 0402 SMD | 0.44 | 8.8
 |  |  | SK-RC0402FR-071K5L
21 | 20 | ERJ-2RKF1003X | RESISTOR 100K OHM 1% 1/10W 0402 SMD | 0.33 | 6.6
 |  |  | SK-ERJ-2RKF1003X
22 | 20 | RR0816P-103-D | RESISTOR 10KOHM 1/16W 5% 0603 SMD | 1.65 | 33
 |  |  | SK-RR0816P-103-D
23 | 20 | RC0603FR-07100KL | RESISTOR 100KOHM 1/10W 1% 0603 SMD | 0.33 | 6.6
 |  |  | SK-RC0603FR-07100KL
24 | 20 | CRCW040210K0FKED | RESISTOR 10KOHM 1% 0402 SMD | 0.44 | 8.8
 |  |  | SK-CRCW040210K0FKED
25 | 15 | RC0402FR-0747KL | RESISTOR 47KOHM 1% 1/16W 0402 SMD | 2.07 | 31.05
 |  |  | SK-RC0402FR-0747KL
26 | 20 | RC0603FR-0747KL | RESISTOR 47KOHM 1/10W 1% 0603 SMD | 0.33 | 6.6
 |  |  | SK-RC0603FR-0747KL
27 | 5 | YELLOW-LED-0805 | YELLOW LED 588NM SMD 0805 | 3.66 | 18.3
 |  |  | SK-YELLOW-LED-0805
28 | 5 | KP-2012EC | LED RED 0805 15MCD 625NM WATER CLEAR | 1.93 | 9.65
 |  |  | SK-KP-2012EC
29 | 5 | RED-DIFF-0603 | DIFFUSED LED RED 0603 SMD | 2.81 | 14.05
 |  |  | SK-RED-DIFF-0603
30 | 5 | LTST-C190GKT | CLEAR GREEN LED 0603 SMD | 1.9 | 9.5
 |  |  | SK-LTST-C190GKT
31 | 5 | 381-2-JUMPER-C | CONN JUMPER SHORTING CLOSE 02 PIN | 0.71 | 3.55
 |  |  | SK-381-2-JUMPER-C
32 | 10 | 415-2P-JUMPER-2.54MM-CLOSE | 415 SERIES 2PIN JUMPER 2.54MM CLOSE TYPE | 0.55 | 5.5
 |  |  | SK-415-2P-JUMPER-2.54MM-CLOSE
33 | 5 | B2B-PH-K-S-TYO | 2POSITION WIRE TO BOARD CONNECTOR HEADER SHROUDED 2MM THROUGH HOLE | 2.71 | 13.55
 |  |  | SK-B2B-PH-K-S-TYO
34 | 5 | 2510-5-2.54MM | CONNECTOR HEADER MTA & RECEPTABLE VERTICAL 5 POSITION 2.54MM | 3.66 | 18.3
 |  |  | SK-2510-5-2.54MM
35 | 4 | MTA-2PIN-CONN-M/F | CONNECTOR HEADER & RECEPTABLE VERTICAL 2-POSITION TIN 3.96MM | 4.88 | 19.52
 |  |  | SK-MTA-2PIN-CONN-M/F
36 | 3 | 320-1X40-F-SOLDER | 320 SERIES FEMALE FLOW SOLDER 1X40 STRAIGHT | 26.24 | 78.72
 |  |  | SK-320-1X40-F-SOLDER
37 | 3 | 322-F-1X40-2.54MM-R/A | 322 SERIES FEMALE FLOW SOLDER 2.54MM 1 X 40 RIGHT ANGLE | 20.99 | 62.97
 |  |  | SK-322-F-1X40-2.54MM-R/A
38 | 2 | USB2.0-CONNECTORS-MALE | USB 2.0 A MALE STANDARD STRAIGHT | 19.24 | 38.48
 |  |  | SK-USB2.0-CONNECTORS-MALE
39 | 2 | MICRO-USB/B-5F/SMD | MICRO USB FEMALE B-TYPE 5PIN SMD | 27.98 | 55.96
 |  |  | SK-MICRO-USB/B-5F/SMD
40 | 2 | USB2.0-CONNECTORS | USB 2.0 SERIES A RECEPTABLE, STANDARD RIGHT ANGLE MALE | 17.49 | 34.98
 |  |  | SK-USB2.0-CONNECTORS
41 | 2 | BAT74 | SCHOTTKY DIODE 30V 200MA SOT143B | 8.05 | 16.1
 |  |  | SK-BAT74
42 | 2 | ZHCS400TA | SCHOTTKY DIODE 40V 400MA SOD323 PACKAGE | 6.15 | 12.3
 |  |  | SK-ZHCS400TA
43 | 4 | BAT54W-7 | SCHOTTKY DIODE 30V 200MA SOT323 | 2.59 | 10.36
 |  |  | SK-BAT54W-7
44 | 4 | SS24S-E3/61T | SCHOTTKY DIODE 40V 2A DO214AC | 9.03 | 36.12
 |  |  | SK-SS24S-E3/61T
45 | 30 | RC0402FR-071KL | RESISTOR 1KOHM 1/16W 1% 0402 SMD | 0.55 | 16.5
 |  |  | SK-RC0402FR-071KL
46 | 2 | 32.768KHz/KDS | CRYSTAL 32.7680KHZ 12.5PF Through hole | 14.52 | 29.04
 |  |  | SK-32.768KHz/KDS
47 | 2 | 32.768KHz-DT-38 | TUNING FORK CRYSTAL RESONATOR 32.767KHZ DT-38 (ECS-.327-8-14X) | 7.32 | 14.64
 |  |  | SK-32.768KHz-DT-38
48 | 5 | 12065A8R2CAT2A | CERAMIC CAPACITOR 8.2PF 50V NP0 1206 | 2 | 10
 |  |  | SK-12065A8R2CAT2A
49 | 1 | 7447709150 | INDUCTOR POWER 15UH 6.5A SMD | 106.84 | 106.84
 |  |  | SK-7447709150
50 | 20 | C1608X5R1C106M080AB | CERAMIC CAPACITOR 10UF 16V 20% X5R 0603 | 3.12 | 62.4
 |  |  | SK-C1608X5R1C106M080AB
51 | 1 | EVM-3YSX50B53 | TRIMMER 5K OHM 0.15W SMD | 18.36 | 18.36
 |  |  | SK-EVM-3YSX50B53
52 | 2 | 3296-POT-10K | TRIMMER POTENTIOMETER 10K OHM | 14.52 | 29.04
 |  |  | SK-3296-POT-10K
53 | 1 | 3296-POT-100K | TRIMMER POTENTIOMETER 100K OHM | 12.44 | 12.44
 |  |  | SK-3296-POT-100K
54 | 30 | RC0603FR-07100RL | RESISTOR 100OHM 1/10W 1% 0603 SMD | 0.88 | 26.4
 |  |  | SK-RC0603FR-07100RL
55 | 20 | RC0402JR-07470RL | RESISTOR 470 OHM 5% 1/16W 0402 SMD | 0.22 | 4.4
 |  |  | SK-RC0402JR-07470RL
56 | 20 | RC0603FR-07470RL | RESISTOR 470OHM 1/10W 1% 0603 SMD | 0.33 | 6.6
 |  |  | SK-RC0603FR-07470RL
57 | 20 | RC0402FR-07470KL | RESISTOR 470KOHM 1/16W 1% 0402 SMD | 0.44 | 8.8
 |  |  | SK-RC0402FR-07470KL
58 | 20 | RC0603FR-07470KL | RESISTOR 470KOHM 1/10W 1% 0603 SMD | 0.33 | 6.6
 |  |  | SK-RC0603FR-07470KL
59 | 20 | RC0603FR-07220KL | RESISTOR 220KOHM 1/10W 1% 0603 SMD | 0.33 | 6.6
 |  |  | SK-RC0603FR-07220KL
60 | 15 | RC0402JR-0747RL | RESISTOR 47OHM 1/16W 5% 0402 SMD | 0.33 | 4.95
 |  |  | SK-RC0402JR-0747RL
61 | 10 | CRCW060347R0FKEA | RESISTOR 47OHM 1/10W 1% 0603 SMD | 1.65 | 16.5
 |  |  | SK-CRCW060347R0FKEA
62 | 20 | RCS04024K70JNED | RESISTOR 4.7K OHM 5% 1/5W 0402 SMD | 0.51 | 10.2
 |  |  | SK-RCS04024K70JNED
63 | 20 | CRCW06034K70FKEA | RESISTOR 4.7KOHM 1/10W 1% 0603 SMD | 1.65 | 33
 |  |  | SK-CRCW06034K70FKEA
64 | 20 | RC0402FR-07330RL | RESISTOR SMD 330OHM 1% 1/16W 0402 | 0.55 | 11
 |  |  | SK-RC0402FR-07330RL
65 | 15 | RC0603FR-07330RL | RESISTOR 330OHM 1/10W 1% 0603 SMD | 0.33 | 4.95
 |  |  | SK-RC0603FR-07330RL
66 | 15 | 04025A150JAT2A | CERAMIC CAPACITOR 15PF 50V 5% NP0 0402 | 1.54 | 23.1
 |  |  | SK-04025A150JAT2A
67 | 15 | GRM219R61C475KE15D | CERAMIC CAPACITOR 4.7UF 16V X5R 0805 | 1.76 | 26.4
 |  |  | SK-GRM219R61C475KE15D
68 | 15 | C1608X5R1C475K080AC | CERAMIC CAPACITOR 4.7UF 16V 10% X5R 0603 | 3.12 | 46.8
 |  |  | SK-C1608X5R1C475K080AC
69 | 2 | DC-JACK | DC POWER JACK CONNECTOR [ 5.5/3.5 Dia] | 10.37 | 20.74
 |  |  | SK-DC-JACK
70 | 5 | 1505-3PIN-DT127 | 1505 SERIES TERMINAL BLOCK STACKABLE PBT 03 PIN | 11.6 | 58
 |  |  | SK-1505-3PIN-DT127
71 | 2 | 10118194-0001LF | MICRO USB CONNECTOR B TYPE RECEPTACLE SMT R/A | 63.84 | 127.68
 |  |  | SK-10118194-0001LF
72 | 5 | BB-535-E7904 | VARIABLE CAPACITENCE DIODE 30V 20MA SOD-323 | 26.24 | 131.2
 |  |  | SK-BB-535-E7904
73 | 2 | ECRJA050G14X | 8.5PF ~ 50PF TRIMMER VARIABLE CAPACITOR | 35.14 | 70.28
 |  |  | SK-ECRJA050G14X
74 | 4 | 708-JST-XH-2.5MM-2P-M/F | 708 SERIES XH 2.5MM 2 PIN MALE & FEMALE WITH WIRE | 6.1 | 24.4
 |  |  | SK-708-JST-XH-2.5MM-2P-M/F
75 | 2 | 708-JST-XH-2.5MM-3P-M/F | 708 SERIES XH 2.5MM 3 PIN MALE & FEMALE WITH WIRE | 9.77 | 19.54
 |  |  | SK-708-JST-XH-2.5MM-3P-M/F
76 | 4 | 708-JST-XH-2.5MM-5P-M/F | 708 SERIES XH 2.5MM 05 PIN MALE & FEMALE WITH WIRE | 11.6 | 46.4
 |  |  | SK-708-JST-XH-2.5MM-5P-M/F
 |  |  |  | Shipment Charge | 0
 | Total : 2553.12
 | [Including Shipment Charge]

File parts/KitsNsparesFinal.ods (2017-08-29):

Description | Manufacturer | Element14 part number | Qty | Price
SDRAM, DDR, 512MBIT, 66TSOP; DRAM Memory Configuration:32M x 16bit; Access Time:5ns; Page Size:-; No. of Pins:66Pins; Memory Case Style:TSOP; Operating Temperature Min:0°C; Operating Temperature Max:70°C; IC Interface Ty | MICRON | MT46V32M16P-5B:J | 1 | Rs.648 |  | 648
MPU, 32BIT, I.MX233, IND, 128LQFP; Product Range:i.MX23 Series; MPU Core Size:32bit; Program Memory Size:16KB; No. of Pins:128Pins; MPU Case Style:LQFP; Supply Voltage Min:-; Supply Voltage Max:1.4V; Operating Temperatur | NXP | MCIMX233CAG4C | 1 | Rs.370 |  | 370
USB Connector Type:Micro USB Type B; USB Standard:USB 2.0; Gender:Receptacle; No. of Positions:5Ways; Connector Mounting:Surface Mount; Orientation:Right Angle; Contact Material:Copper Alloy; Contact Pl | MOLEX | 105017-0001 | 1 | Minimum order quantity-14000
CONNECTOR, MICRO SD, STANDARD, 8POS, SMT; Product Range:DM3 Series; Connector Type:Micro SD; No. of Contacts:8Contacts; Contact Material:Copper Alloy; Contact Plating:Gold Plated Contacts; Contact Termination:Surface Mou | HIROSE(HRS) | DM3AT-SF-PEJM5 | 1 | Rs.271 |  | 271
CRYSTAL, 24MHZ, 30PF, HC49; Product Range:HC-49/4H Series; Frequency Nom:24MHz; Frequency Stability + / -:50ppm; Frequency Tolerance + / -:30ppm; Crystal Case:Through Hole, 11mm x 4.7mm; Load Capacitance:30pF; Operating | IQD FREQUENCY PRODUCTS | LFXTAL003325 | 2 | Rs.40 |  | 40
CAP, MLCC, C0G, 30PF, 50V, 0402; Ceramic Capacitor Case:0402 [1005 Metric]; Capacitance:30pF; Voltage Rating:50V; Capacitance Tolerance:± 5%; Dielectric Characteristic:C0G / NP0; Product Range:GRM Series; Packaging:Cut T | MURATA | MC0402N300J500CT or 0402N300J500CT | 100 | Rs.1 | http://in.element14.com/productimages/standard/en_US/4595607.jpg | 1
INDUCTOR, 15UH, 10%, 0.8A TH RADIAL; Product Range:1100R Series; Inductance:15µH; Inductance Tolerance:± 10%; DC Resistance Max:0.19ohm; RMS Current (Irms):800mA; Saturation Current (Isat):800mA; Packaging:Each; SVHC:No | MURATA POWER SOLUTIONS | 11R153C | 1 | Rs.26 |  | 26
INDUCTOR, POWER, 2.2UH, SEMI SHIELDED; Product Range:SRN3015 Series; Inductance:2.2µH; RMS Current (Irms):1.8A; Saturation Current (Isat):1.65A; Inductor Construction:Semishielded; DC Resistance Max:0.072ohm; Power Induc | BOURNS | SRN3015-2R2M | 1 | Rs.49 |  | 49
XTAL, 24.000MHZ, 18PF, SMD, 5.0X3.2; Frequency Nom:24MHz; Crystal Case:SMD, 5mm x 3.2mm; Frequency Stability + / -:30ppm; Load Capacitance:18pF; Frequency Tolerance + / -:30ppm; Product Range:7A Series; Operating Tempera | TXC | 7A-24.000MAAJ-T | 1 | Minimum order quantity-1000 | http://in.element14.com/productimages/standard/en_US/4824453.jpg
INDUCTOR, POWER, 22UH, SEMI SHIELDED; Product Range:SRN6045 Series; Inductance:22µH; RMS Current (Irms):1.5A; Saturation Current (Isat):1.9A; Inductor Construction:Shielded; DC Resistance Max:0.142ohm; Power Inductor Cas | BOURNS | SRN6045-220M | 1 | Rs.40 |  | 40
DIODE, VARICAP, 18.6PF, 0.02A, SC-79; Capacitance Cd Max @ Vr F:18.6pF; Forward Current If(AV):20mA; Repetitive Reverse Voltage Vrrm Max:10V; Operating Temperature Max:125°C; Diode Case Style:SC-79; No. of Pins:2 Pin; Pa | INFINEON | BBY5702VH6327XTSA1or BB135 | 2 | Minimum order quantity-5
BOARD-BOARD CONNECTOR HEADER, 6 POSITION, 2ROWContacts; Contact Materi | HARWIN | M22-2520305 | 2 | Rs.31 |  | 31
USB Connector Type:USB Type A; USB Standard:USB 2.0; Gender:Receptacle; No. of Positions:4Ways; Connector Mounting:Surface Mount; Orientation:Right Angle; Contact Material:Phosphor Bronze; Contact Plati | MULTICOMP | MC32602 | 1 | Rs.84 |  | 84
USB, 2.0 TYPE A, PLUG, SMT; USB Connector Type:USB Type A; USB Standard:USB 2.0; Gender:Plug; No. of Positions:4Ways; Connector Mounting:Surface Mount; Orientation:Horizontal; Contact Material:Copper Alloy; Contact Plati | MULTICOMP | MC000991 | 1 | Minimum order quantity-10 | MULTICOMP MCPS3316MT150
MCPS3316MT150 - INDUCTOR, 15UH, 2A, 20%, 25MHz | MULTICOMP | MCPS3316MT150 | 1 | Rs.12 |  | 12
MCPD1608MT150 - INDUCTOR, UN-SHIELDED, 15UH, SMD | MULTICOMP | MCPD1608MT150 | 1 | Rs.5 | MULTICOMP MCPD1608MT150 | 5
 |  | Total amount |  | Rs.1935 (Including tax and shipping charges) |  | 1577
 |  |  |  |  |  | 358

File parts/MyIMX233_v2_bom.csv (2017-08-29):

Id | Designator | Package | Quantity | Designation | Supplier and ref
1 | J2 | 1pin | 1 | CONN_01X01
2 | C42 | CP_Radial_D5.0mm_P2.50mm | 1 | 22uF
3 | R27 | R_0603 | 1 | 120R
4 | R25,R26,R19 | R_0603_HandSoldering | 3 | 0.1ohm
5 | R20 | R_0603_HandSoldering | 1 | 470k
6 | R21,R23,R22 | R_0603_HandSoldering | 3 | 100k
7 | R24 | R_0603_HandSoldering | 1 | 10k
8 | D10,D4,D5 | D_SOD-323_HandSoldering | 3 | 5.1v
9 | C41,C37,C36,C13 | C_0603_HandSoldering | 4 | 1u
10 | D7,D9 | D_DO-35_SOD27_P7.62mm_Horizontal | 2 | 5.1v
11 | D8 | D_DO-35_SOD27_P7.62mm_Horizontal | 1 | 3.3v
12 | C38 | CP_Radial_D5.0mm_P2.50mm | 1 | 10uF
13 | D6 | D_SOD-123 | 1 | 3.3v
14 | R17,R18 | R_0603 | 2 | 47K
15 | XS1 | uSDcard | 1 | SD_ebay-uSD-push/push_SMD
16 | IC1 | LQFP-128_14x14mm_Pitch0.4mm | 1 | iMX233
17 | Y1 | Crystal_HC49-4H_Vertical | 1 | 24Mhz
18 | JP_USB_boot1 | Pin_Header_Straight_1x02_Pitch2.54mm | 1 | USB_boot
19 | JP1 | Pin_Header_Straight_1x02_Pitch2.54mm | 1 | WithBatt
20 | R15,R16 | R_0603 | 2 | 1K
21 | J1 | USB_Micro-B_MOLEX_105017-0001 | 1 | USB_OTG
22 | R6,R8 | R_0603_HandSoldering | 2 | 4.7k
23 | R14,R13,R9,R12,R10,R11 | R_0603_HandSoldering | 6 | 47k
24 | P6 | GOGO_TESTPAD2 | 1 | 1v
25 | D3 | LED_0603 | 1 | LED
26 | R7,R1 | R_0603_HandSoldering | 2 | 1k
27 | P1 | GOGO_TESTPAD2 | 1 | 4p2
28 | P2 | GOGO_TESTPAD2 | 1 | 1v2
29 | P4 | GOGO_TESTPAD2 | 1 | 2v5
30 | P5 | GOGO_TESTPAD2 | 1 | 3v3
31 | P3 | GOGO_TESTPAD2 | 1 | VDDA1v8
32 | C12,C39,C24,C33,C35,C31,C8,C20,C19,C18,C17,C16,C23,C14,C10,C9,C6,C3,C15,C21,C22 | C_0402 | 21 | 100n
33 | C40,C34,C28 | C_0402 | 3 | 10n
34 | R3,R2 | R_0603 | 2 | 1K1%
35 | C32 | C_0603_HandSoldering | 1 | 4.7uf
36 | C30,C29 | C_0805_HandSoldering | 2 | 47u
37 | BT1 | JST_XH_B02B-XH-A_02x2.50mm_Straight | 1 | Battery
38 | D2 | D_SOD-323_HandSoldering | 1 | D_Batt
39 | R5 | R_0603_HandSoldering | 1 | 1K
40 | R4 | R_0603_HandSoldering | 1 | 100K
41 | IC2 | TSOP66_JEDEC_DDR_SDRAM | 1 | DDR_SDRAM_MT46_x16
42 | DEBUG_UART1,I2C1 | Pin_Header_Straight_1x04_Pitch2.54mm | 2 | CONN_01X04
43 | JP2 | Pin_Header_Straight_1x02_Pitch2.54mm | 1 | WithoutBatt
44 | L1 | Bourns22uh6x6mm | 1 | 22uH
45 | C26,C27 | C_0402 | 2 | 1u
46 | C25,C11,C5,C4 | C_0805_HandSoldering | 4 | 22u
47 | LCD1 | Pin_Header_Straight_1x30_Pitch2.54mm | 1 | CONN_01X30
48 | GPIO1 | Pin_Header_Straight_1x05_Pitch2.54mm | 1 | CONN_01X05
49 | C1,C2 | C_0402 | 2 | 10p
50 | SW1 | SW_PUSH_6mm | 1 | SWITCH_PUSHBUTTON
51 | C7 | C_0805_HandSoldering | 1 | 1u
52 | D1 | LED_D4.0mm | 1 | LED

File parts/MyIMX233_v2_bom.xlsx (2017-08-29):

Id | Designator | Package | Quantity | Designation | Supplier and ref
1 | BT1 | JST_XH_B02B-XH-A_02x2.50mm_Straight | 1 | Battery
2 | C1,C2 | C_0402 | 2 | 10p
3 | C12,C39,C24,C33,C35,C31,C8,C20,C19,C18,C17,C16,C23,C14,C10,C9,C6,C3,C15,C21,C22 | C_0402 | 21 | 100n
4 | C25,C11,C5,C4 | C_0805_HandSoldering | 4 | 22u
5 | C26,C27 | C_0402 | 2 | 1u
6 | C30,C29 | C_0805_HandSoldering | 2 | 47u
7 | C32 | C_0603_HandSoldering | 1 | 4.7uf
8 | C38 | CP_Radial_D5.0mm_P2.50mm | 1 | 10uF
9 | C40,C34,C28 | C_0402 | 3 | 10n
10 | C41,C37,C36,C13 | C_0603_HandSoldering | 4 | 1u
11 | C42 | CP_Radial_D5.0mm_P2.50mm | 1 | 22uF
12 | C7 | C_0805_HandSoldering | 1 | 1u
13 | D1 | LED_D4.0mm | 1 | LED
14 | D10,D4,D5 | D_SOD-323_HandSoldering | 3 | 5.1v | Zener
15 | D2 | D_SOD-323_HandSoldering | 1 | D_Batt | Schottkey (ZHCS400TA)
16 | D3 | LED_0603 | 1 | LED
17 | D6 | D_SOD-123 | 1 | 3.3v | Zener
18 | D7,D9 | D_DO-35_SOD27_P7.62mm_Horizontal | 2 | 5.1v | Zener
19 | D8 | D_DO-35_SOD27_P7.62mm_Horizontal | 1 | 3.3v | Zener
20 | DEBUG_UART1,I2C1 | Pin_Header_Straight_1x04_Pitch2.54mm | 2 | CONN_01X04
21 | ~~GPIO1~~ | ~~Pin_Header_Straight_1x05_Pitch2.54mm~~ | ~~1~~ | ~~CONN_01X05~~
22 | IC1 | LQFP-128_14x14mm_Pitch0.4mm | 1 | iMX233 | Mouser-freescale MCIMX233DAG4C
23 | IC2 | TSOP66_JEDEC_DDR_SDRAM | 1 | DDR_SDRAM_MT46_x16 | Mouser-micron MT46V32M16P-5B:J
24 | J1 | USB_Micro-B_MOLEX_105017-0001 | 1 | USB_OTG
25 | JP_USB_boot1 | Pin_Header_Straight_1x02_Pitch2.54mm | 1 | USB_boot
26 | JP1 | Pin_Header_Straight_1x02_Pitch2.54mm | 1 | WithBatt
27 | JP2 | Pin_Header_Straight_1x02_Pitch2.54mm | 1 | WithoutBatt
28 | L1 | Bourns22uh6x6mm | 1 | 22uH | MCPD1608MT150
29 | P6 | GOGO_TESTPAD2 | 1 | 1v
30 | R14,R13,R9,R12,R10,R11 | R_0603_HandSoldering | 6 | 47k
31 | R15,R16 | R_0603 | 2 | 1K
32 | R17,R18 | R_0603 | 2 | 47K
33 | R20 | R_0603_HandSoldering | 1 | 470k
34 | R21,R23,R22 | R_0603_HandSoldering | 3 | 100k
35 | R24 | R_0603_HandSoldering | 1 | 10k
36 | R25,R26,R19 | R_0603_HandSoldering | 3 | 0.1ohm
37 | R27 | R_0603 | 1 | 120R
38 | R3,R2 | R_0603 | 2 | 1K1%
39 | R4 | R_0603_HandSoldering | 1 | 100K
40 | R5 | R_0603_HandSoldering | 1 | 1K
41 | R6,R8 | R_0603_HandSoldering | 2 | 4.7k
42 | R7,R1 | R_0603_HandSoldering | 2 | 1k
43 | SW1 | SW_PUSH_6mm | 1 | SWITCH_PUSHBUTTON
44 | XS1 | uSDcard | 1 | SD_ebay-uSD-push/push_SMD
45 | Y1 | Crystal_HC49-4H_Vertical | 1 | 24Mhz
46 | ~~P1~~ | ~~GOGO_TESTPAD2~~ | ~~1~~ | ~~4p2~~
47 | ~~P2~~ | ~~GOGO_TESTPAD2~~ | ~~1~~ | ~~1v2~~
48 | ~~P3~~ | ~~GOGO_TESTPAD2~~ | ~~1~~ | ~~VDDA1v8~~
49 | ~~P4~~ | ~~GOGO_TESTPAD2~~ | ~~1~~ | ~~2v5~~
50 | ~~P5~~ | ~~GOGO_TESTPAD2~~ | ~~1~~ | ~~3v3~~
51 | ~~LCD1~~ | ~~Pin_Header_Straight_1x30_Pitch2.54mm~~ | ~~1~~ | ~~CONN_01X30~~
52 | ~~J2~~ | ~~1pin~~ | ~~1~~ | ~~CONN_01X01~~

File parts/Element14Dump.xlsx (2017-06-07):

Description | Manufacturer | Manufacturer Part Number | Quantity | Unit Price | Line Total |  | KitsNSpares | qty | Shelfkey
SDRAM, DDR, 512MBIT, 66TSOP; DRAM Memory Configuration:32M x 16bit; Access Time:5ns; Page Size:-; No. of Pins:66Pins; Memory Case Style:TSOP; Operating Temperature Min:0°C; Operating Temperature Max:70°C; IC Interface Ty | MICRON | MT46V32M16P-5B:J | 1 | INR 664.25 | INR 664.25 | 664.25 | 648
MPU, 32BIT, I.MX233, IND, 128LQFP; Product Range:i.MX23 Series; MPU Core Size:32bit; Program Memory Size:16KB; No. of Pins:128Pins; MPU Case Style:LQFP; Supply Voltage Min:-; Supply Voltage Max:1.4V; Operating Temperatur | NXP | MCIMX233CAG4C | 1 | INR 369 | INR 369 | 369.00 | 370
USB Connector Type:Micro USB Type B; USB Standard:USB 2.0; Gender:Receptacle; No. of Positions:5Ways; Connector Mounting:Surface Mount; Orientation:Right Angle; Contact Material:Copper Alloy; Contact Pl | MOLEX | 105017-0001 | 1 | INR 64.61 | INR 64.61 | 64.61 | 68
CONNECTOR, MICRO SD, STANDARD, 8POS, SMT; Product Range:DM3 Series; Connector Type:Micro SD; No. of Contacts:8Contacts; Contact Material:Copper Alloy; Contact Plating:Gold Plated Contacts; Contact Termination:Surface Mou | HIROSE(HRS) | DM3AT-SF-PEJM5 | 1 | INR 237.92 | INR 237.92 | 237.92 | 271
CRYSTAL, 24MHZ, 30PF, HC49; Product Range:HC-49/4H Series; Frequency Nom:24MHz; Frequency Stability + / -:50ppm; Frequency Tolerance + / -:30ppm; Crystal Case:Through Hole, 11mm x 4.7mm; Load Capacitance:30pF; Operating | IQD FREQUENCY PRODUCTS | LFXTAL003325 | 2 | INR 39.24 | INR 78.48 | 78.48 | 40 |  | -
CRYSTAL, 24M, 18PF CL, HC49/4H; Frequency Nom:24MHz; Crystal Case:Through Hole, 11.5mm x 4.65mm; Frequency Stability + / -:50ppm; Load Capacitance:18pF; Frequency Tolerance + / -:30ppm; Product Range:-; Operating Tempera | CITIZEN FINETECH MIYOTA | HC49US24.000MABJ-UB | 2 | INR 39.44 | INR 78.88 | 78.88 | NA |  | Shelfkey
CAP, MLCC, C0G, 30PF, 50V, 0402; Ceramic Capacitor Case:0402 [1005 Metric]; Capacitance:30pF; Voltage Rating:50V; Capacitance Tolerance:± 5%; Dielectric Characteristic:C0G / NP0; Product Range:GRM Series; Packaging:Cut T | MURATA | MC0402N300J500CT or 0402N300J500CT | 100 | INR 0.75 | INR 75 | 75.00 | 1 |  | -
CAP, MLCC, X7R, 0.1UF, 16V, 0402; Ceramic Capacitor Case:0402 [1005 Metric]; Capacitance:0.1µF; Voltage Rating:16V; Capacitance Tolerance:± 5%; Dielectric Characteristic:X7R; Product Range:GRM Series; Packaging:Cut Tape; | MURATA | GRM155R71C104JA88D | 100 | INR 0.79 | INR 79 | 79.00 | 60 | 30 | Shelfkey | 402
CAP, MLCC, X7R, 0.01UF, 50V, 0402; Ceramic Capacitor Case:0402 [1005 Metric]; Capacitance:0.01µF; Voltage Rating:50V; Capacitance Tolerance:± 5%; Dielectric Characteristic:X7R; Product Range:MC Series; Packaging:Cut Tape | MULTICOMP | MC0402B103J500CT | 100 | INR 0.71 | INR 71 | 71.00 | NA |  | Shelfkey | 402
CAPACITOR, MLCC, NP0, 15PF, 50V, 0402; Ceramic Capacitor Case:0402 [1005 Metric]; Capacitance:15pF; Voltage Rating:50V; Capacitance Tolerance:± 5%; Dielectric Characteristic:C0G / NP0; Product Range:-; Packaging:Cut Tape | WALSIN | 0402N150J500CT | 20 | INR 0.34 | INR 6.8 | 6.80 |  |  | Shelfkey
CAP, MLCC, C0G/NP0, 18PF, 50V, 0402; Ceramic Capacitor Case:0402 [1005 Metric]; Capacitance:18pF; Voltage Rating:50V; Capacitance Tolerance:± 5%; Dielectric Characteristic:C0G / NP0; Product Range:MC Series; Packaging:Cu | MULTICOMP | MC0402N180J500CT | 20 | INR 0.8 | INR 16 | 16.00 | 20 |  | Shelfkey | 402
CAP, MLCC, X5R, 1UF, 6.3V, 0402; Ceramic Capacitor Case:0402 [1005 Metric]; Capacitance:1µF; Voltage Rating:6.3V; Capacitance Tolerance:± 20%; Dielectric Characteristic:X5R; Product Range:GRM Series; Packaging:Cut Tape; | MURATA | GRM155R60J105ME19D | 10 | INR 1.77 | INR 17.7 | 17.70 | NA |  | Shelfkey | 402
CAP, MLCC, X5R, 1UF, 6.3V, 0603; Ceramic Capacitor Case:0603 [1608 Metric]; Capacitance:1µF; Voltage Rating:6.3V; Capacitance Tolerance:± 10%; Dielectric Characteristic:X5R; Product Range:GRM Series; Packaging:Cut Tape; | MURATA | GRM188R60J105KA01D | 10 | INR 1.81 | INR 18.1 | 18.10 | 120 | 20 | Shelfkey | 603
CAP, MLCC, X5R, 1UF, 10V, 0603; Ceramic Capacitor Case:0603 [1608 Metric]; Capacitance:1µF; Voltage Rating:10V; Capacitance Tolerance:± 10%; Dielectric Characteristic:X5R; Product Range:C Series; Packaging:Cut Tape; Oper | KEMET | C0603C105K8PACTU | 10 | INR 1.81 | INR 18.1 | 18.10 | ERROR |  | Shelfkey
CAP, MLCC, X5R, 22UF, 6.3V, 0805; Ceramic Capacitor Case:0805 [2012 Metric]; Capacitance:22µF; Voltage Rating:6.3V; Capacitance Tolerance:± 20%; Dielectric Characteristic:X5R; Product Range:-; Packaging:Cut Tape; Operati | AVX | 08056D226MAT2A | 10 | INR 7.98 | INR 79.8 | 79.80 |  |  | Shelfkey | 805
CAP, MLCC, X5R, 47UF, 6.3V, 1206; Ceramic Capacitor Case:1206 [3216 Metric]; Capacitance:47µF; Voltage Rating:6.3V; Capacitance Tolerance:± 20%; Dielectric Characteristic:X5R; Product Range:GRM Series; Packaging:Cut Tape | MURATA | GRM31CR60J476ME19L | 10 | INR 16.47 | INR 164.7 | 164.70 |  |  | Shelfkey | 805
CAP, MLCC, X5R, 4.7UF, 6.3V, 0603; Ceramic Capacitor Case:0603 [1608 Metric]; Capacitance:4.7µF; Voltage Rating:6.3V; Capacitance Tolerance:± 10%; Dielectric Characteristic:X5R; Product Range:CC Series; Packaging:Cut Tap | YAGEO (PHYCOMP) | CC0603KRX5R5BB475 | 10 | INR 4.6 | INR 46 | 46.00 |  |  | Shelfkey
CAP, MLCC, X6S, 4.7UF, 25V, 0805; Ceramic Capacitor Case:0805 [2012 Metric]; Capacitance:4.7µF; Voltage Rating:25V; Capacitance Tolerance:± 10%; Dielectric Characteristic:X6T; Product Range:GRM Series; Packaging:Cut Tape | MURATA | GRM21BC81E475KA12L | 10 | INR 5.26 | INR 52.6 | 52.60 |  |  | Shelfkey
RES, CERAMIC, 1K, 1%, 0.1W, 0603; Resistance:1kohm; Voltage Rating:75V; Resistor Case Style:0603 [1608 Metric]; Power Rating:100mW; Resistance Tolerance:± 1%; Product Range:MCMR Series; Packaging:Cut Tape; Resistor Eleme | MULTICOMP | MCMR06X1001FTL | 100 | INR 0.065 | INR 6.5 | 6.50 |  |  | Shelfkey | 603
RES, THICK FILM, 470K, 1%, 0.1W, 0603; Resistance:470kohm; Voltage Rating:50V; Resistor Case Style:0603 [1608 Metric]; Power Rating:100mW; Resistance Tolerance:± 1%; Product Range:MCWR Series; Packaging:Cut Tape; Resisto | MULTICOMP | MCWR06X4703FTL | 50 | INR 0.34 | INR 17 | 17.00 |  |  | Shelfkey | 402 - 603
RES, THICK FILM, 220K, 1%, 0.1W, 0603; Resistance:220kohm; Voltage Rating:50V; Resistor Case Style:0603 [1608 Metric]; Power Rating:100mW; Resistance Tolerance:± 1%; Product Range:MCWR Series; Packaging:Cut Tape; Resisto | MULTICOMP | MCWR06X2203FTL | 50 | INR 0.36 | INR 18 | 18.00 |  |  | Shelfkey | 603
RES, THICK FILM, 47KOHM, 1%, 0.1W; Resistance:47kohm; Voltage Rating:50V; Resistor Case Style:0603 [1608 Metric]; Power Rating:100mW; Resistance Tolerance:± 1%; Product Range:MCWR Series; Packaging:Cut Tape; Resistor Ele | MULTICOMP | MCWR06X4702FTL | 50 | INR 0.37 | INR 18.5 | 18.50 |  |  | Shelfkey | 402-603
RES, THICK FILM, 470R, 1%, 0.0625W, 0402; Resistance:470ohm; Voltage Rating:50V; Resistor Case Style:0402 [1005 Metric]; Power Rating:62.5mW; Resistance Tolerance:± 1%; Product Range; Available until stocks are exhausted | MULTICOMP | MC00625W04021470R | 50 | INR 0.056 | INR 2.8 | 2.80 |  |  | Shelfkey | 402-603
RES, THICK FILM, 47R, 1%, 0.0625W, 0402; Resistance:47ohm; Voltage Rating:50V; Resistor Case Style:0402 [1005 Metric]; Power Rating:62.5mW; Resistance Tolerance:± 1%; Product Range:M; Available until stocks are exhausted | MULTICOMP | MC00625W0402147R | 50 | INR 0.071 | INR 3.55 | 3.55 |  |  | Shelfkey | 402-603
RES, THICK FILM, 330R, 5%, 0.063W, 0402; Resistance:330ohm; Voltage Rating:50V; Resistor Case Style:0402 [1005 Metric]; Power Rating:63mW; Resistance Tolerance:± 5%; Product Range:RC Series; Packaging:Cut Tape; Resistor | YAGEO (PHYCOMP) | RC0402JR-07330RL | 10 | INR 0.66 | INR 6.6 | 6.60 |  |  | Shelfkey | 402-603
RES, THICK FILM, 10KOHM, 1%, 0.0625W; Resistance:10kohm; Voltage Rating:50V; Resistor Case Style:0402 [1005 Metric]; Power Rating:62.5mW; Resistance Tolerance:± 1%; Product Range:MCWR Series; Packaging:Cut Tape; Resistor | MULTICOMP | MCWR04X1002FTL | 40 | INR 0.33 | INR 13.2 | 13.20 |  |  | Shelfkey | 402
RES, THICK FILM, 4K7, 1%, 0.0625W, 0402; Resistance:4.7kohm; Voltage Rating:50V; Resistor Case Style:0402 [1005 Metric]; Power Rating:62.5mW; Resistance Tolerance:± 1%; Product Range:MCWR Series; Packaging:Cut Tape; Resi | MULTICOMP | MCWR04X4701FTL | 20 | INR 0.33 | INR 6.6 | 6.60 |  |  | Shelfkey
RES, THICK FILM, 100R, 5%, 0.063W, 0402; Resistance:100ohm; Voltage Rating:50V; Resistor Case Style:0402 [1005 Metric]; Power Rating:63mW; Resistance Tolerance:± 5%; Product Range:RC Series; Packaging:Cut Tape; Resistor | YAGEO (PHYCOMP) | RC0402JR-07100RL | 20 | INR 0.66 | INR 13.2 | 13.20 |  |  | Shelfkey | 603
RES, THICK FILM, 100K, 5%, 0.063W, 0402; Resistance:100kohm; Voltage Rating:50V; Resistor Case Style:0402 [1005 Metric]; Power Rating:63mW; Resistance Tolerance:± 5%; Product Range:RC Series; Packaging:Cut Tape; Resistor | YAGEO (PHYCOMP) | RC0402JR-07100KL | 40 | INR 0.66 | INR 26.4 | 26.40 |  |  | Shelfkey | 402-0603
RES, THICK FILM, 220 OHM, 1%, 0.0625W; Resistance:220ohm; Voltage Rating:50V; Resistor Case Style:0402 [1005 Metric]; Power Rating:62.5mW; Resistance Tolerance:± 1%; Product Range:MCWR Series; Packaging:Cut Tape; Resisto | MULTICOMP | MCWR04X2200FTL | 50 | INR 0.33 | INR 16.5 | 16.50
RES, THICK FILM, 150R, 1%, 0.063W, 0402; Resistance:150ohm; Voltage Rating:50V; Resistor Case Style:0402 [1005 Metric]; Power Rating:63mW; Resistance Tolerance:± 1%; Product Range:CRG Series; Packaging:Cut Tape; Resistor | TE CONNECTIVITY | CRG0402F150R | 50 | INR 0.54 | INR 27 | 27.00
CAP, MLCC, C0G/NP0, 10PF, 50V, 0402; Ceramic Capacitor Case:0402 [1005 Metric]; Capacitance:10pF; Voltage Rating:50V; Capacitance Tolerance:± 5%; Dielectric Characteristic:C0G / NP0; Product Range:GRM Series; Packaging:C | MURATA | GRM1555C1H100JA01D | 20 | INR 0.49 | INR 9.8 | 9.80 |  |  | Shelfkey | 8.2pf
INDUCTOR, 15UH, 10%, 0.8A TH RADIAL; Product Range:1100R Series; Inductance:15µH; Inductance Tolerance:± 10%; DC Resistance Max:0.19ohm; RMS Current (Irms):800mA; Saturation Current (Isat):800mA; Packaging:Each; SVHC:No | MURATA POWER SOLUTIONS | 11R153C | 1 | INR 26.44 | INR 26.44 | 26.44 | 26
INDUCTOR, 2.2UH, POWER, NON-SHIELDED; Product Range:SDR0302 Series; Inductance:2.2µH; RMS Current (Irms):1.65A; Saturation Current (Isat):1.85A; Inductor Construction:Unshielded; DC Resistance Max:0.09ohm; Power Inductor | BOURNS | SDR0302-2R2ML | 2 | INR 41.6 | INR 83.2 | 83.20 | 271 | 4.7uh,10uh | Shelfkey | 320mA
INDUCTOR, POWER, 2.2UH, SEMI SHIELDED; Product Range:SRN3015 Series; Inductance:2.2µH; RMS Current (Irms):1.8A; Saturation Current (Isat):1.65A; Inductor Construction:Semishielded; DC Resistance Max:0.072ohm; Power Induc | BOURNS | SRN3015-2R2M | 1 | INR 31.86 | INR 31.86 | 31.86 | 68
INDUCTOR, UNSHLD, 15UH, 20%, 2.3A; Product Range:AEC-Q200 SDE0604A Series; Inductance:15µH; Inductance Tolerance:± 20%; Inductor Construction:Unshielded; DC Resistance Max:0.14ohm; RMS Current (Irms):2.3A; Saturation Cur | BOURNS | SDE0604A-150M | 1 | INR 45.58 | INR 45.58 | 45.58 | XX |  | Shelfkey | 150mA
INDUCTOR, SEMI-SHLD, 15UH, 20%, 1.8A; Product Range:SRN5040 Series; Inductance:15µH; RMS Current (Irms):1.8A; Saturation Current (Isat):2A; Inductor Construction:Semishielded; DC Resistance Max:0.096ohm; Power Inductor C | BOURNS | SRN5040-150M | 1 | INR 31.86 | INR 31.86 | 31.86 | xx |  | Shelfkey | 6.5A
CRYSTAL, 32.768KHZ, 12.5PF, 3.2 X 1.5MM; Frequency Nom:32.768kHz; Crystal Case:SMD, 3.2mm x 1.5mm; Frequency Stability + / -:-; Load Capacitance:12.5pF; Frequency Tolerance + / -:50ppm; Product Range: 46W3157 | TXC | 9HT10-32.768KBZF-T | 1 | INR 44.37 | INR 44.37 | 44.37 |  |  | Shelfkey
CRYSTAL, 32.768KHZ, 12.5PF, CYLINDER; Product Range:AB26TRB Series; Frequency Nom:32.768kHz; Frequency Stability + / -:-; Frequency Tolerance + / -:20ppm; Crystal Case:Cylinder SMD, 6mm x 1.9mm Dia; L 13J1807 | ABRACON | AB26TRB-32.768KHZ-T. | 1 | INR 38.62 | INR 38.62 | 38.62 |  |  | Shelfkey
XTAL, 24.000MHZ, 18PF, SMD, 5.0X3.2; Frequency Nom:24MHz; Crystal Case:SMD, 5mm x 3.2mm; Frequency Stability + / -:30ppm; Load Capacitance:18pF; Frequency Tolerance + / -:30ppm; Product Range:7A Series; Operating Tempera | TXC | 7A-24.000MAAJ-T | 1 | INR 59.16 | INR 59.16 | 59.16 | 68 |  | -
DIODE, RF, SCHOTTKY, SOT-23; Diode Configuration:Single; Reverse Voltage Vr:15V; Forward Current If Max:1A; Forward Voltage VF Max:340mV; Capacitance Ct:1pF; Diode Case Style:SOT-23; No. of Pins:3 Pin; Packaging:Cut Tape | BROADCOM LIMITED | HSMS-2820-TR1G | 1 | INR 54.17 | INR 54.17 | 54.17 | xx |  | Shelfkey
SCHOTTKY RECTIFIER, 1A, 15V, DO-214AA-2; Repetitive Reverse Voltage Vrrm Max:15V; Forward Current If(AV):1A; Diode Configuration:Single; Diode Case Style:DO-214AA; No. of Pins:2Pins; Forward Voltage VF Max:330mV; Forward | VISHAY | VS-10BQ015-M3/5BT | 1 | INR 42 | INR 42 | 42.00 | xx |  | Shelfkey
DIODE, RF, SCHOTTKY, DUAL, SOT-23; Diode Configuration:Dual Common Cathode; Reverse Voltage Vr:20V; Forward Current If Max:1mA; Forward Voltage VF Max:1V; Capacitance Ct:1.2pF; Diode Case Style:SOT-23; No. of Pins:3 Pin; | BROADCOM LIMITED | HSMS-2814-TR1G | 1 | INR 101.57 | INR 101.57 | 101.57 | xx |  | Shelfkey
INDUCTOR, POWER, 22UH, SEMI SHIELDED; Product Range:SRN6045 Series; Inductance:22µH; RMS Current (Irms):1.5A; Saturation Current (Isat):1.9A; Inductor Construction:Shielded; DC Resistance Max:0.142ohm; Power Inductor Cas | BOURNS | SRN6045-220M | 1 | INR 38.06 | INR 38.06 | 38.06 | 68 | 22uh
CERAMIC CAPACITOR 12PF 50V, C0G, 10%, 0402; Ceramic Capacitor Case:0402 ^1005 Metric]; Capacitance:12pF; Voltage Rating:50V; Capacitance Tolerance: 10%; Dielectric Characteristic:C0G / NP0; Product R 06R4778 | MULTICOMP | MC0402N120K500CT | 10 | INR 0.5 | INR 5 | 5.00 | KitsNSpares |  | Shelfkey | 402
CAP, MLCC, X5R, 10UF, 6.3V, 0805; Ceramic Capacitor Case:0805 [2012 Metric]; Capacitance:10µF; Voltage Rating:6.3V; Capacitance Tolerance:± 10%; Dielectric Characteristic:X5R; Product Range:C Series; Packaging:Cut Tape; | KEMET | C0805C106K9PACTU | 20 | INR 4.37 | INR 87.4 | 87.40 | ok |  | Shelfkey | 805
CAP, MLCC, X5R, 10UF, 6.3V, 0603; Ceramic Capacitor Case:0603 [1608 Metric]; Capacitance:10µF; Voltage Rating:6.3V; Capacitance Tolerance:± 20%; Dielectric Characteristic:X5R; Product Range:GRM Series; Packaging:Cut Tape | MURATA | GRM188R60J106ME47J | 10 | INR 6.3 | INR 63 | 63.00 |  |  | Shelfkey | 603
CONNECTOR, HEADER, THT, RA, 2.54MM, 6WAY; Product Range:MC34 Series; No. of Contacts:6Contacts; Gender:Header; Pitch Spacing:2.54mm; Contact Termination Type:Through Hole; No. of Rows:1Rows; Contact Plating:Gold Plated C | MULTICOMP | MC34751 | 3 | INR 7.65 | INR 22.95 | 22.95 | 68 |  | Shelfkey | 2.54mm white
CONNECTOR, HEADER, THT, 2.54MM, 10WAY; Product Range:2213S Series; No. of Contacts:10Contacts; Gender:Header; Pitch Spacing:2.54mm; Contact Termination Type:Through Hole; No. of Rows:2Rows; Contact Plating:Gold Plated Co | MULTICOMP | 2213S-10G | 7 | INR 7.47 | INR 52.29 | 52.29 | 68 |  | Shelfkey | 3.96mm m/f pair
CONNECTOR, HEADER, THT, 2.54MM, 4WAY; Product Range:2211S Series; No. of Contacts:4Contacts; Gender:Header; Pitch Spacing:2.54mm; Contact Termination Type:Through Hole; No. of Rows:1Rows; Contact Plating:Gold Plated Cont | MULTICOMP | 2211S-04G | 10 | INR 2.99 | INR 29.9 | 29.90 | 68 |  | Shelfkey
HEADER, THT, VERTICAL, 2.54MM, 10WAY; Product Range:2211S Series; No. of Contacts:10Contacts; Gender:Header; Pitch Spacing:2.54mm; Contact Termination Type:Through Hole; No. of Rows:1Rows; Contact Plating:Gold Plated Con | MULTICOMP | 2211S-10G | 10 | INR 7.65 | INR 76.5 | 76.50 | 68 |  | Shelfkey | black 2.54mm
Accessory Type:Jumper; For Use With:2.54mm Headers; No. of Positions:2Ways; Pitch Spacing:2.54mm; Product Range:-; SVHC:No SVHC (15-Jun-2015) | AMPHENOL FCI | 68786-202 | 3 | INR 5.9 | INR 17.7 | 17.70 | 68 |  | Shelfkey
SHUNT, 2 POSITION, 2.54MM; Accessory Type:Shunt; For Use With:Pin Headers; No. of Positions:2Positions; Pitch Spacing:2.54mm; Product Range:969 Series 10R6270 | 3M | 969102-0000-DA. | 10 | INR 7.97 | INR 79.7 | 79.70 | 68 |  | Shelfkey
LED, 0805, YELLOW/GREEN, 40MCD,; LED Colour:Yellow Green; LED Mounting:SMD; Bulb Size:1.25mm x 1.4mm; Forward Current If:20mA; Forward Voltage:2V; Wavelength Typ:575nm; Luminous Intensity:40mcd; Viewing Angle:140°; Lens | DIALIGHT | 5988160107F. | 5 | INR 4.07 | INR 20.35 | 20.35 |  |  | Shelfkey | 805
LED, 1.25MM X 1.3MM, RED, 230MCD, 630NM; LED Colour:Red; LED Mounting:SMD; Bulb Size:-; Forward Current If:20mA; Forward Voltage:1.95V; Wavelength Typ:630nm; Luminous Intensity:80mcd; Viewing Angle:120°; Lens Shape:Recta | KINGBRIGHT | KP-2012SURCK | 10 | INR 3.9 | INR 39 | 39.00 |  |  | Shelfkey | 603
DIODE, VARICAP, 20PF, 0.02A, SOD-323; Capacitance Cd Max @ Vr F:20pF; Forward Current If(AV):20mA; Repetitive Reverse Voltage Vrrm Max:30V; Operating Temperature Max:150°C; Diode Case Style:SOD-323; No. of Pins:2 Pin; Pa | INFINEON | BB535E7904HTSA1 | 2 | INR 29.62 | INR 59.24 | 59.24 | xx |  | -
DIODE, VARICAP, 18.6PF, 0.02A, SC-79; Capacitance Cd Max @ Vr F:18.6pF; Forward Current If(AV):20mA; Repetitive Reverse Voltage Vrrm Max:10V; Operating Temperature Max:125°C; Diode Case Style:SC-79; No. of Pins:2 Pin; Pa | INFINEON | BBY5702VH6327XTSA1or BB135 | 2 | INR 34.7 | INR 69.4 | 69.40 | 20 |  | -
DIODE, ZENER, 0.500W, 3.3V, SOD123F; Zener Voltage Vz Typ:3.3V; Power Dissipation Pd:500mW; Diode Case Style:SOD-123F; Zener Tolerance ±:2.5%; No. of Pins:2Pins; Operating Temperature Max:150°C; Packaging:Each; Product R | NEXPERIA | NZH3V3A | 2 | INR 14 | INR 28 | 28.00 | 15 |  | Shelfkey
Zener Voltage Vz Typ:5.1V; Power Dissipation Pd:500mW; Diode Case Style:SOD-123; Zener Tolerance ±:5%; No. of Pins:2Pins; Operating Temperature Max:150°C; Packaging:Cut Tape; Product Range:MMSZxxxT1G Se | FAIRCHILD SEMICONDUCTOR | MMSZ5231B | 2 | INR 16.43 | INR 32.86 | 32.86 |  |  | Shelfkey
IC, V REG +5.0V, 7805, TO-220-3; Output Type:Fixed; Input Voltage Min:10V; Input Voltage Max:35V; Fixed Output Voltage Nom.:5V; Adjustable Output Voltage Min:-; Adjustable Output Voltage Max:-; Output Current:1A; Linear | FAIRCHILD SEMICONDUCTOR | LM7805CT | 1 | INR 50.13 | INR 50.13 | 50.13 |  |  | Shelfkey
HEADER, TOP ENTRY, 2WAY,2MM; Pitch Spacing:2mm; No. of Contacts:2Contacts; Gender:Header; Product Range:PH Series; Contact Termination Type:Through Hole; No. of Rows:1Rows; Contact Plating:Tin Plated Contacts; Contact Ma | JST (JAPAN SOLDERLESS TERMINALS) | B2B-PH-K-S(LF)(SN) | 2 | INR 14.42 | INR 28.84 | 28.84 |  |  | Shelfkey
BOARD-BOARD CONNECTOR HEADER, 6 POSITION, 2ROWContacts; Contact Materi | HARWIN | M22-2520305 | 2 | INR 16.12 | INR 32.24 | 32.24 | 31
CONNECTOR, HEADER, THT, 2.5MM, 4WAY; Product Range:EH Series; Contact Termination Type:Through Hole; Gender:Header; No. of Contacts:4; Pitch Spacing:2.5mm; Contact Plating:Tin; Contact Material:Brass; No. of Rows:1; Cont | JST (JAPAN SOLDERLESS TERMINALS) | B4B-EH-A(LF)(SN) | 1 | INR 16.97 | INR 16.97 | 16.97 | 18 |  | Shelfkey
ZENER DIODE, 500mW, 5.1V, DO-35; Zener Voltage Vz Typ:5.1V; Power Dissipation Pd:500mW; Diode Case Style:DO-35; Zener Tolerance :5%; No. of Pins:2Pins; Operating Temperature Max:175 C; Product Range: 90R9455 | MULTICOMP | 1N5231B | 2 | INR 6.8 | INR 13.6 | 13.60 |  |  | Shelfkey
TRIMMER, TOP ADJUST, 22K; Track Resistance:22kohm; Power Rating:150mW; Resistance Tolerance:± 20%; Product Range:CB10 Series; No. of Turns:1Turns; Potentiometer Mounting:Through Hole; Temperature Coefficient:± 500ppm/°C; | TE CONNECTIVITY / CITEC | CB10LV223M | 1 | INR 19.72 | INR 19.72 | 19.72 | xx |  | Shelfkey
POT, TRIMMER, 10K, 1 TURN, THROUGH HOLE; Track Resistance:10kohm; Power Rating:150mW; Resistance Tolerance:± 20%; Product Range:CB10 Series; No. of Turns:1Turns; Potentiometer Mounting:Through Hole; Temperature Coefficie | TE CONNECTIVITY / CITEC | CB10LV103M | 1 | INR 43.55 | INR 43.55 | 43.55 |  |  | Shelfkey | 10k,100k
TRIMMER, TOP ADJUST, 1K; Product Range:CB10 Series; Track Resistance:1kohm; No. of Turns:1Turns; Power Rating:150mW; Resistance Tolerance:± 20%; Temperature Coefficient:± 500ppm/°C; Potentiometer Mounting:Through Hole; A | TE CONNECTIVITY / CITEC | CB10LV102M | 1 | INR 35.33 | INR 35.33 | 35.33 |  |  | Shelfkey | 5k
USB Connector Type:USB Type A; USB Standard:USB 2.0; Gender:Receptacle; No. of Positions:4Ways; Connector Mounting:Surface Mount; Orientation:Right Angle; Contact Material:Phosphor Bronze; Contact Plati | MULTICOMP | MC32602 | 1 | INR 59.81 | INR 59.81 | 59.81 | 84
USB, 2.0 TYPE A, PLUG, SMT; USB Connector Type:USB Type A; USB Standard:USB 2.0; Gender:Plug; No. of Positions:4Ways; Connector Mounting:Surface Mount; Orientation:Horizontal; Contact Material:Copper Alloy; Contact Plati | MULTICOMP | MC000991 | 1 | INR 65.55 | INR 65.55 | 65.55 | 84
RES, THICK FILM, 1KOHM, 1%, 0.0625W; Resistance:1kohm; Voltage Rating:50V; Resistor Case Style:0402 [1005 Metric]; Power Rating:62.5mW; Resistance Tolerance:± 1%; Product Range:MCWR Series; Packaging:Cut Tape; Resistor E | MULTICOMP | MCWR04X1001FTL | 50 | INR 0.33 | INR 16.5 | 16.50 | 84 |  | Shelfkey
 |  |  |  |  | SUM== | 3986.01
30pf |  |  |  |  |  |  |  |  | Shelfkey

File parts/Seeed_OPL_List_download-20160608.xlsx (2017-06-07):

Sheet: OPL on sale list
OPL on sale list. 20160608
Seeed SKU | MPN | Description | Category | Package | Manufacturer | Datasheet | Price（$）/pcs | Pieces/set | Solder points Qty | Assem.Cost/pcs（$） | Image URL | Distributor-URL
306010055 | FC-135 | SMD Crystal 32.768KHz-7pF-20ppm-70k | Crystal Oscillator | 2P-L3.2*W1.5mm | Xinhunjing | http://www.seeedstudio.com/wiki/images/7/78/306010055.pdf | 0.391 | 5 | 4 | 0.40 |  | http://www.seeedstudio.com/depot/OPLopen-parts-library-catalog-c-136_138/#306010055
306010037 | 49S/18PF | DIP Crystal 16MHz-18pF-30ppm-50R | Crystal Oscillator | HC49/US | Xinhunjing | http://www.seeedstudio.com/wiki/images/5/57/306010037.pdf | 0.131 | 10 | 2 | 0.20 |  | http://www.seeedstudio.com/depot/OPLopen-parts-library-catalog-c-136_138/#306010037
306010054 | X053201602002 | SMD Crystal 16MHz-8pF-20ppm-40R | Crystal Oscillator | 2P-SMD-5.0X3.2 | JINGPENGYUAN | http://www.seeedstudio.com/wiki/images/9/9f/0500290P1.pdf | 0.430 | 5 | 2 | 0.20 |  | http://www.seeedstudio.com/depot/OPLopen-parts-library-catalog-c-136_138/#0500290P1
306010047 | 5032/2P | SMD Crystal 12MHz-20pF-20ppm-40R | Crystal Oscillator | 2P-L5.0*W3.2mm | Xinhunjing | http://www.seeedstudio.com/wiki/images/c/c7/306010047.pdf | 0.449 | 5 | 2 | 0.20 |  | http://www.seeedstudio.com/depot/OPLopen-parts-library-catalog-c-136_138/#306010047
305030028 | 2N7002,215 | SMD MOSFET N-CH 60V 300mA | Transistor | SOT-23 | NXP | http://www.seeedstudio.com/wiki/images/c/c6/305030028.pdf | 0.037 | 30 | 3 | 0.30 |  | http://www.seeedstudio.com/depot/OPLopen-parts-library-catalog-c-136_138/#305030028
305030015 | CJ2302 | SMD MOSFET N-CH 20V 2.1A | Transistor | SOT23 | JCET | http://www.seeedstudio.com/wiki/images/e/e7/0440200P1.pdf | 0.090 | 10 | 3 | 0.30 |  | http://www.seeedstudio.com/depot/OPLopen-parts-library-catalog-c-136_138/#0440200P1
305030014 | CJ2305 | SMD MOSFET P-CH 8V 4.1A | Transistor | SOT-23 | JCET | http://www.seeedstudio.com/wiki/images/a/ac/0440210P1.pdf | 0.078 | 10 | 3 | 0.30 |  | http://www.seeedstudio.com/depot/OPLopen-parts-library-catalog-c-136_138/#0440210P1
305010018 | S9013 | SMD Transistors NPN 25V 500mA | Transistor | SOT-23 | JCET | http://www.seeedstudio.com/wiki/images/6/67/0400000P1.pdf | 0.023 | 50 | 3 | 0.30 |  | http://www.seeedstudio.com/depot/OPLopen-parts-library-catalog-c-136_138/#0400000P1
305020006 | S8550 | SMD Transistors PNP 25V 500mA | Transistor | SOT-23 |  | http://www.seeedstudio.com/wiki/images/e/e5/0410030P1.pdf | 0.023 | 50 | 3 | 0.30 |  | http://www.seeedstudio.com/depot/OPLopen-parts-library-catalog-c-136_138/#0410030P1
305010017 | S8050 | SMD Transistors NPN 25V 500mW | Transistor | SOT-23 | JCET | http://www.seeedstudio.com/wiki/images/b/ba/305010017.pdf | 0.023 | 50 | 3 | 0.30 |  | http://www.seeedstudio.com/depot/OPLopen-parts-library-catalog-c-136_138/#305010017
312010004 | KS-12065D03YA | DIP Buzzer 3V/30mA;2700±300Hz | Audio product | 2P-7.6-D12*H6.5mm | Guangjixing | http://www.seeedstudio.com/wiki/images/c/cb/312020003.pdf | 0.504 | 5 | 2 | 0.20 |  | http://www.seeedstudio.com/depot/OPLopen-parts-library-catalog-c-136_138/#312010004
302020027 | TAJD477M006RNJ | SMD CAP Tantalum 470uF-6.3V;D | Capacitor | AVX-D | AVX |  | 0.918 | 5 | 2 | 0.20 |  | http://www.seeedstudio.com/depot/OPLopen-parts-library-catalog-c-136_138/#302020027
302030031 |  | DIP CAP Aluminum 100uF-16V | Capacitor | Radial-D5.0*H7.0mm | JWCO | http://www.seeedstudio.com/wiki/images/1/14/302030031.pdf | 0.015 | 50 | 2 | 0.20 |  | http://www.seeedstudio.com/depot/OPLopen-parts-library-catalog-c-136_138/#302030031
302020025 | TAJC107K010RNJ | SMD CAP Tantalum 100uF-10V 10% | Capacitor | AVX-C | AVX | http://www.seeedstudio.com/wiki/images/a/ae/0130170P1.pdf | 0.281 | 10 | 2 | 0.20 |  | http://www.seeedstudio.com/depot/OPLopen-parts-library-catalog-c-136_138/#0130170P1
302020022 | TAJC476K016RNJ | SMD CAP Tantalum 47uF-16V | Capacitor | AVX-C | AVX | http://www.seeedstudio.com/wiki/images/c/c7/302020022.pdf | 0.300 | 10 | 2 | 0.20 |  | http://www.seeedstudio.com/depot/OPLopen-parts-library-catalog-c-136_138/#302020022
302020020 | TAJB476K010RNJ | SMD CAP Tantalum 47uF-10V 10% | Capacitor | AVX-B | AVX | http://www.seeedstudio.com/wiki/images/f/fb/0130180P1.pdf | 0.157 | 10 | 2 | 0.20 |  | http://www.seeedstudio.com/depot/OPLopen-parts-library-catalog-c-136_138/#0130180P1
302020005 | TAJC476K006RNJ | SMD CAP Tantalum 47uF-6.3V | Capacitor | AVX-A | AVX |  | 0.109 | 20 | 2 | 0.20 |  | http://www.seeedstudio.com/depot/OPLopen-parts-library-catalog-c-136_138/#302020005
302020021 | TAJB226K010RNJ | SMD CAP Tantalum 22uF-10V 10% | Capacitor | AVX-B | AVX | http://www.seeedstudio.com/wiki/images/8/82/0130240P1.pdf | 0.125 | 20 | 2 | 0.20 |  | http://www.seeedstudio.com/depot/OPLopen-parts-library-catalog-c-136_138/#0130240P1
302010171 | CC0805MKX5R5BB226 | SMD CAP Ceramic 22uF-6.3V-20%-X5R; | Capacitor | 0805 | YAGEO |  | 0.055 | 50 | 2 | 0.20 |  | http://www.seeedstudio.com/depot/OPLopen-parts-library-catalog-c-136_138/#302010171
302010181 | CC1206KKX5R8BB106 | SMD CAP Ceramic 10uF-25V-10%-X5R | Capacitor | 1206 | YAGEO |  | 0.091 | 20 | 2 | 0.20 |  | http://www.seeedstudio.com/depot/OPLopen-parts-library-catalog-c-136_138/#302010181
302010178 | CC0805KKX5R8BB106 | SMD CAP Ceramic 10uF-25V-10%-X5R | Capacitor | 0805 | YAGEO | http://www.seeedstudio.com/wiki/images/2/20/0100080P1.pdf | 0.055 | 50 | 2 | 0.20 |  | http://www.seeedstudio.com/depot/OPLopen-parts-library-catalog-c-136_138/#0100080P1
302020019 | TAJB106K016RNJ | SMD CAP Tantalum 10uF-16V 10% | Capacitor | AVX-B | AVX | http://www.seeedstudio.com/wiki/images/f/f6/0130120P1.pdf | 0.109 | 20 | 2 | 0.20 |  | http://www.seeedstudio.com/depot/OPLopen-parts-library-catalog-c-136_138/#0130120P1
302020002 | TAJA106K016RNJ | SMD CAP Tantalum 10uF-16V 10% | Capacitor | AVX-A | AVX | http://www.seeedstudio.com/wiki/images/1/1b/0130050P1.pdf | 0.098 | 20 | 2 | 0.20 |  | http://www.seeedstudio.com/depot/OPLopen-parts-library-catalog-c-136_138/#0130050P1
302020011 | TAJA106K010RNJ | SMD CAP Tantalum 10uF-10V 10% | Capacitor | AVX-A | AVX | http://www.seeedstudio.com/wiki/images/5/59/0130040P1.pdf (http://www.seeedstudio.com/wiki/images/0/0d/302010146.pdf) | 0.105 | 20 | 2 | 0.20 |  | http://www.seeedstudio.com/depot/OPLopen-parts-library-catalog-c-136_138/#0130040P1
302010146 | CC0805KKX5R8BB475 | SMD CAP Ceramic 4.7uF-25V-10%-X5R;0805 | Capacitor | C0805 | YAGEO | http://www.seeedstudio.com/wiki/images/0/0d/302010146.pdf | 0.041 | 50 | 2 | 0.20 |  | http://www.seeedstudio.com/depot/OPLopen-parts-library-catalog-c-136_138/#302010146
302010111 | CC0603KRX5R6BB475 | SMD CAP Ceramic 4.7uF-10V-10%-X5R; | Capacitor | 0603 | YAGEO |  | 0.023 | 50 | 2 | 0.20 |  | http://www.seeedstudio.com/depot/OPLopen-parts-library-catalog-c-136_138/#302010111
302010019 | CC0402MRX5R5BB475 | SMD CAP Ceramic 4.7uF-6.3V-20%-X5R | Capacitor | 0402 | YAGEO |  | 0.016 | 10 | 2 | 0.20 |  | http://www.seeedstudio.com/depot/OPLopen-parts-library-catalog-c-136_138/#302010019
302010148 | CC0805KKX7R8BB225 | SMD CAP Ceramic 2.2uF-25V-10%-X7R;0805 | Capacitor | C0805 | YAGEO | http://www.seeedstudio.com/wiki/images/a/ac/302010056.pdf | 0.042 | 50 | 2 | 0.20 |  | http://www.seeedstudio.com/depot/OPLopen-parts-library-catalog-c-136_138/#302010148
302010179 | CC0805KKX7R8BB105 | SMD CAP Ceramic 1uF-25V-10%-X7R | Capacitor | 0805 | YAGEO | http://www.seeedstudio.com/wiki/images/8/89/0100440P1.pdf (http://www.seeedstudio.com/wiki/images/a/ac/302010056.pdf) | 0.014 | 50 | 2 | 0.20 |  | http://www.seeedstudio.com/depot/OPLopen-parts-library-catalog-c-136_138/#0100440P1
302010139 | CC0603KRX7R8BB105 | SMD CAP Ceramic 1uF-25V-10%-X7R | Capacitor | 0603 | YAGEO | http://www.seeedstudio.com/wiki/images/a/af/0100340P1.pdf (http://www.seeedstudio.com/wiki/File:302010056.pdf) | 0.010 | 100 | 2 | 0.20 |  | http://www.seeedstudio.com/depot/OPLopen-parts-library-catalog-c-136_138/#0100340P1
302010040 | CC0402KRX5R6BB105 | SMD CAP Ceramic 1uF-10V-10%-X5R | Capacitor | 0402 | YAGEO |  | 0.010 | 100 | 2 | 0.20 |  | http://www.seeedstudio.com/depot/OPLopen-parts-library-catalog-c-136_138/#302010040
302010073 | CC0603KRX7R8BB224 | SMD CAP Ceramic 220nF-25V-10%-X7R;0603 | Capacitor | 0603 | YAGEO | http://www.seeedstudio.com/wiki/images/a/ac/302010056.pdf | 0.014 | 100 | 2 | 0.20 |  | http://www.seeedstudio.com/depot/OPLopen-parts-library-catalog-c-136_138/#302010073
302010165 | CC0805KRX7R9BB104 | SMD CAP Ceramic 100nF-50V-10%-X7R; | Capacitor | 0805 | YAGEO | http://www.seeedstudio.com/wiki/File:302010056.pdf (http://www.seeedstudio.com/wiki/images/a/ac/302010056.pdf) | 0.010 | 100 | 2 | 0.20 |  | http://www.seeedstudio.com/depot/OPLopen-parts-library-catalog-c-136_138/#302010165
302010138 | CC0603KRX7R9BB104 | SMD CAP Ceramic 100nF-50V-10%-X7R | Capacitor | 0603 | YAGEO | http://www.seeedstudio.com/wiki/images/3/35/0100020P1.pdf | 0.010 | 100 | 2 | 0.20 |  | http://www.seeedstudio.com/depot/OPLopen-parts-library-catalog-c-136_138/#0100020P1
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

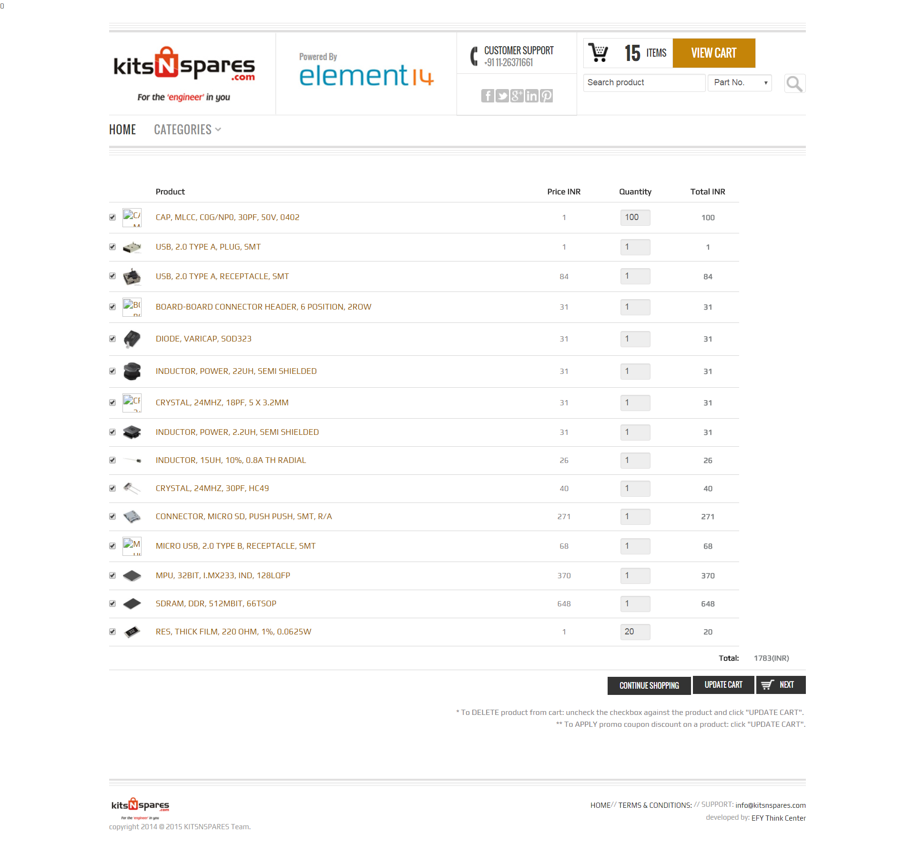
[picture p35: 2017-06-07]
parts/KitsNSpares.png

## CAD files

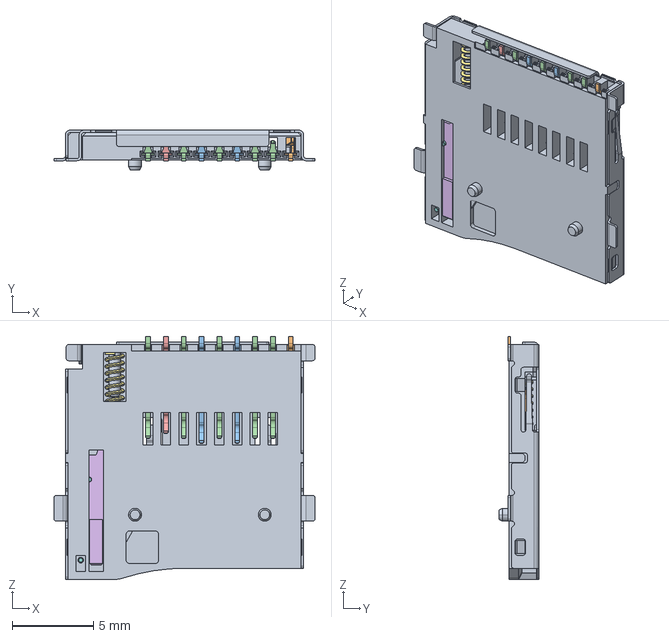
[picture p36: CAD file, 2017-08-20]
parts/uSD_push-push_ebay112J-TXAR-R_C_1.stp
16.1 x 2.45 x 15.0 mm

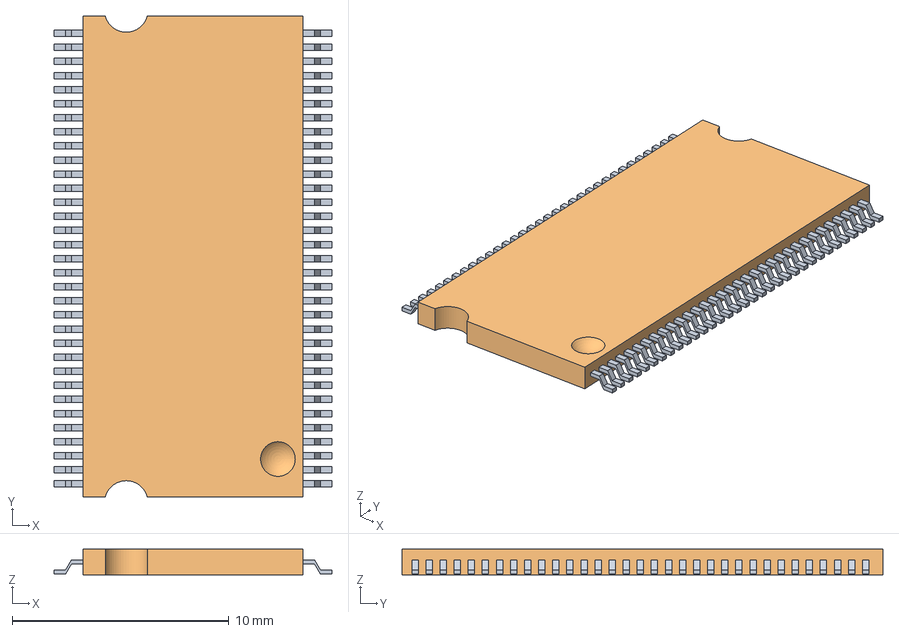
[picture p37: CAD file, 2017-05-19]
plot_sch/DDR_66_TSOP_40mil.step
12.8 x 22.2 x 1.20 mm
Array_(Mirror_#1)

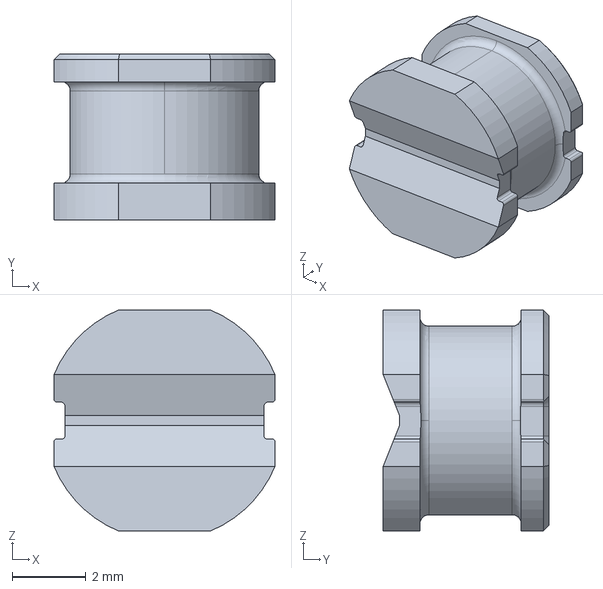
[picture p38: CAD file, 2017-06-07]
parts/InductorBourns_srn6045.stp
6.00 x 4.50 x 6.00 mm

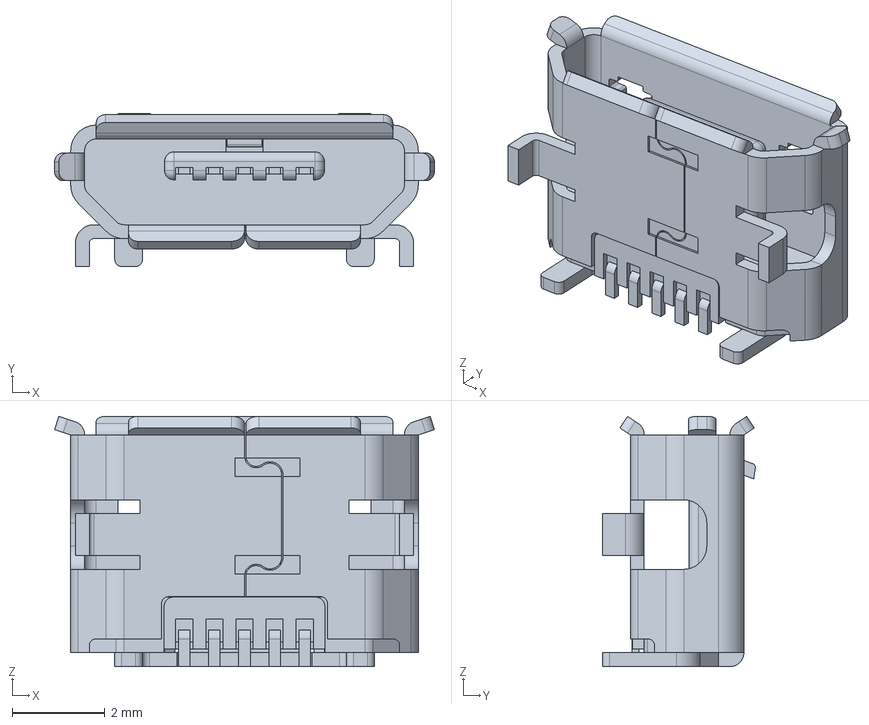
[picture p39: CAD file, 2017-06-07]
parts/MicroUSB.stp
8.20 x 3.30 x 5.40 mm

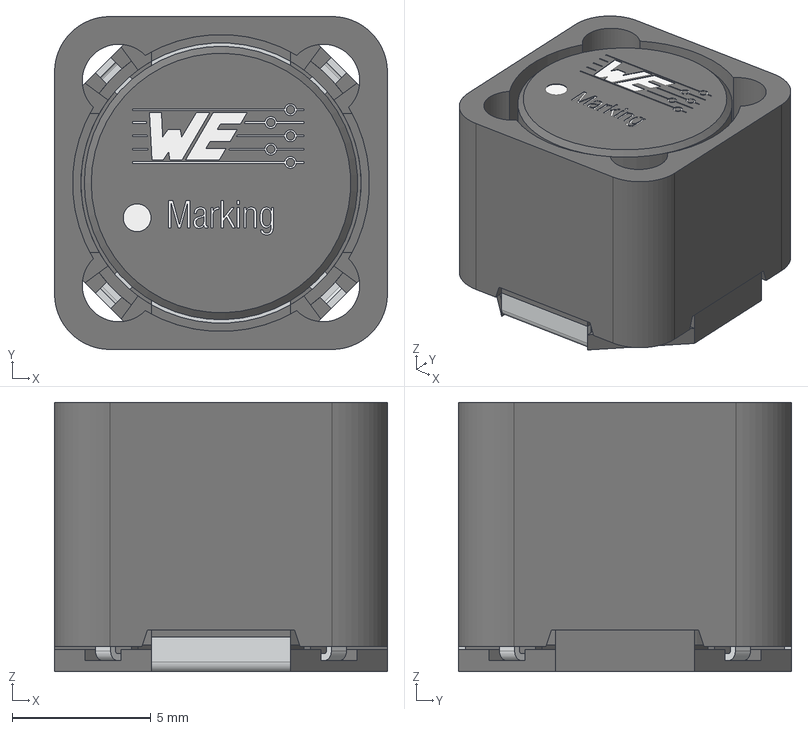
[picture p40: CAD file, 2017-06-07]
parts/STEP-WE-PD-HV-1210-rev1.stp
12.0 x 12.0 x 9.70 mm

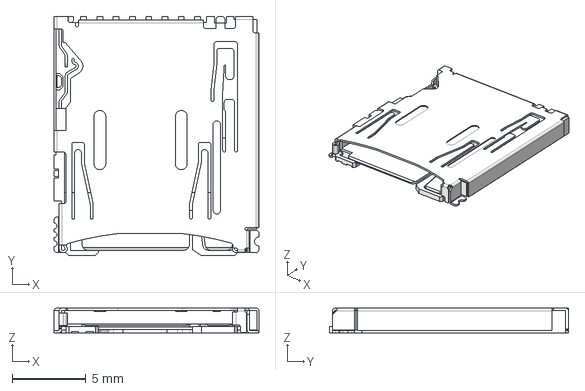
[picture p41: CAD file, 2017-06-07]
parts/DM3AT-SF-PEJM5-SD_card.stp
13.8 x 16.2 x 1.68 mm

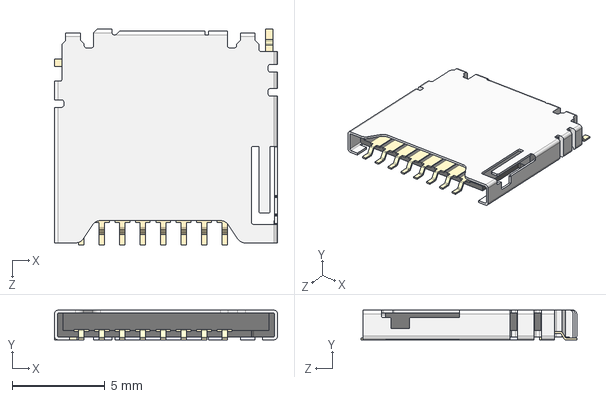
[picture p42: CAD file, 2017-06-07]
parts/Micro SD Holder 114-00841-68.STEP
12.0 x 1.60 x 11.6 mm

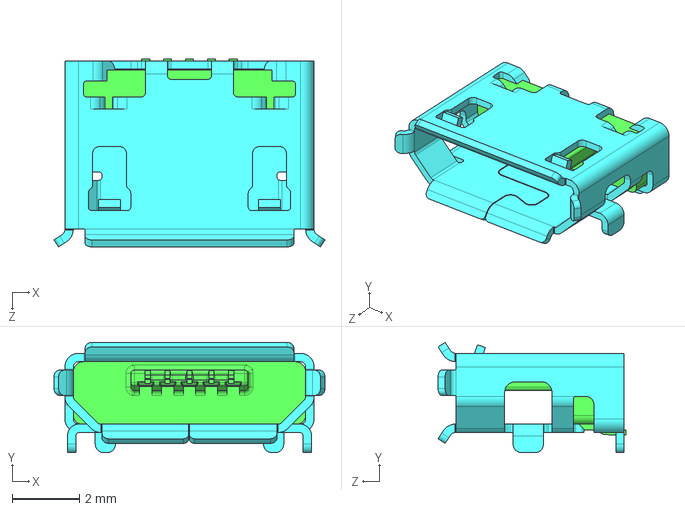
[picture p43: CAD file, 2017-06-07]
parts/10118194-0001LF.STEP
8.05 x 3.28 x 5.58 mm

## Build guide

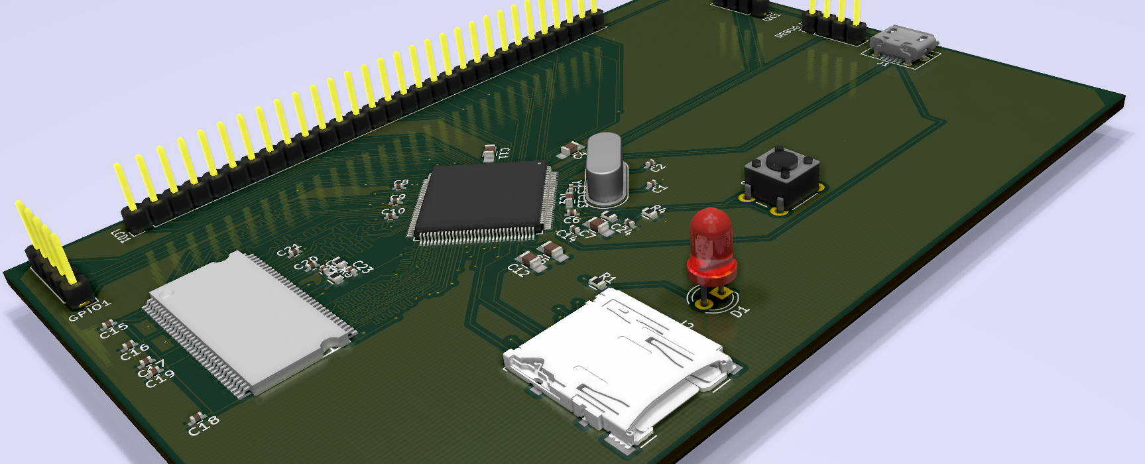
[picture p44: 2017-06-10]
plot_pcb/MyIMX233_0.2-step.png

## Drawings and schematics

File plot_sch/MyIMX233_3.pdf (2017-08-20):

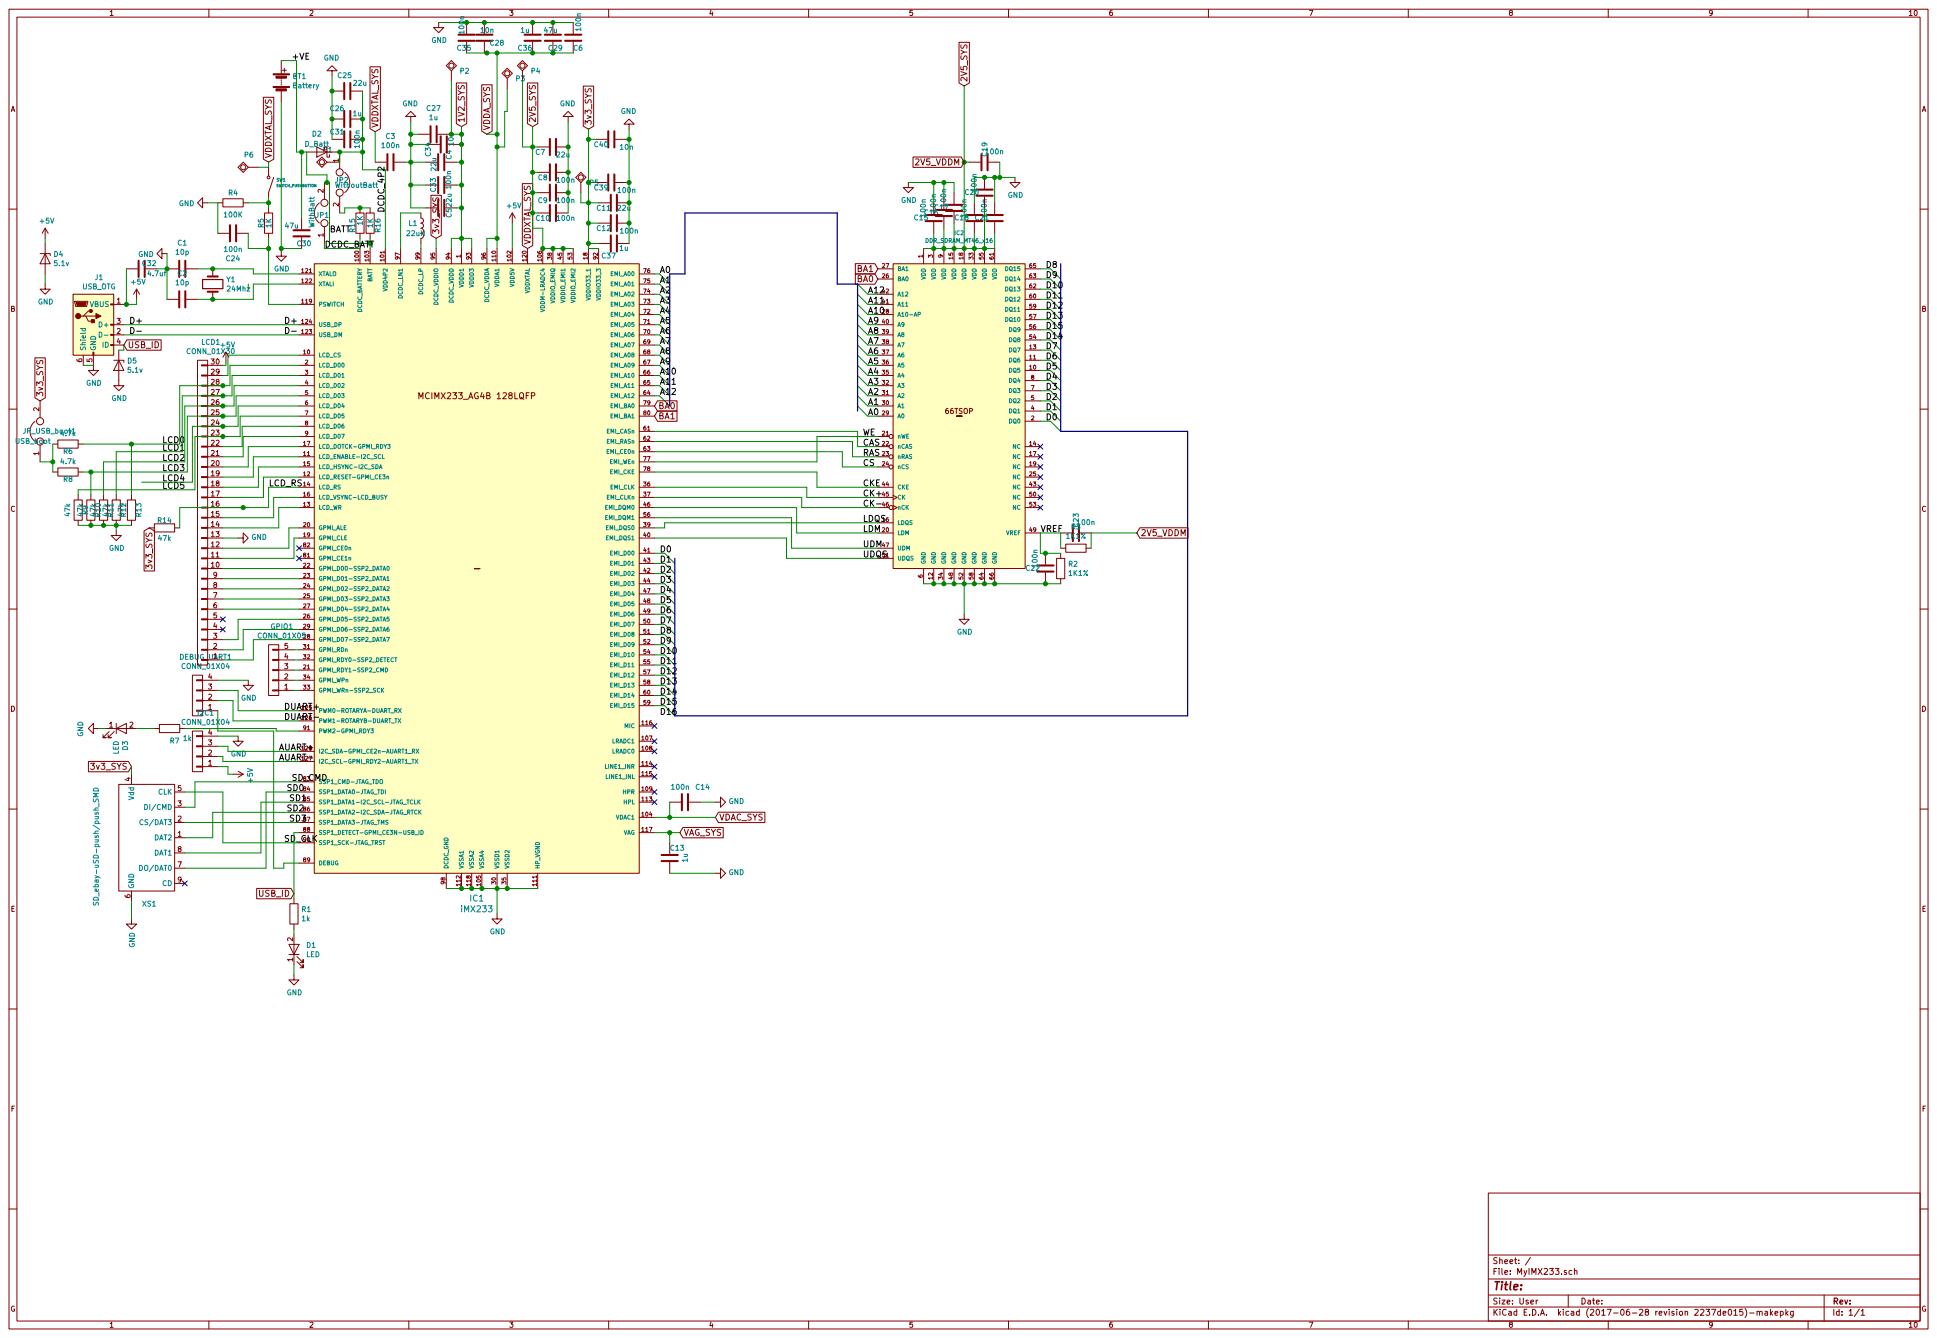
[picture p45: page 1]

Schematic Symbol Drawn By Opendous Inc. www.opendous.org VDDD1 1

29 | | LCD_D01 3
28 | | LCD_D02 4
27 | | LCD_D03 5
26 | | LCD_D04 6
25 | | LCD_D05 7
24 | | LCD_D06 8
23 | | LCD_D07 9
22

LCD1 | | 21 | | | RAS
LCD2
LCD3
LCD4

17 | | CK+
16 | | CK-
15

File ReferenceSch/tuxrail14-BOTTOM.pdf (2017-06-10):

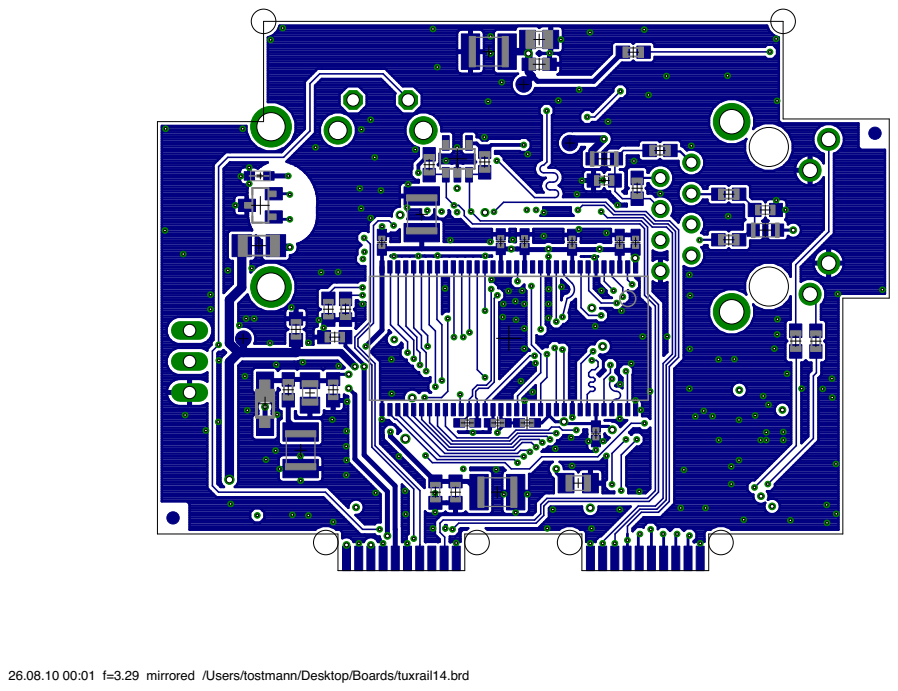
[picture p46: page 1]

26.08.10 00:01 f=3.29 mirrored /Users/tostmann/Desktop/Boards/tuxrail14.brd

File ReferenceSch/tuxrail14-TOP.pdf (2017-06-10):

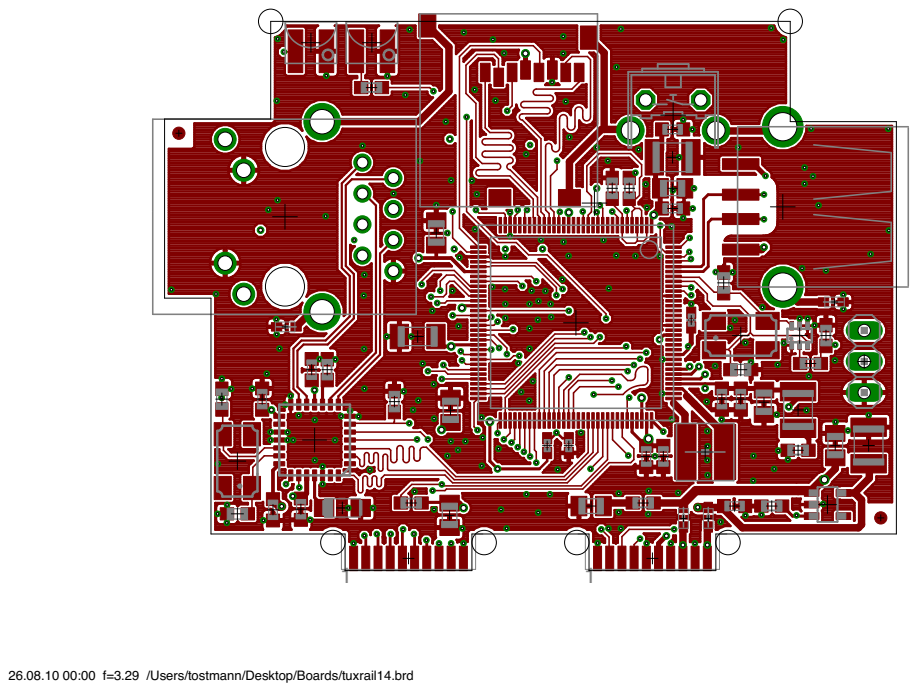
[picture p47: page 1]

26.08.10 00:00 f=3.29 /Users/tostmann/Desktop/Boards/tuxrail14.brd

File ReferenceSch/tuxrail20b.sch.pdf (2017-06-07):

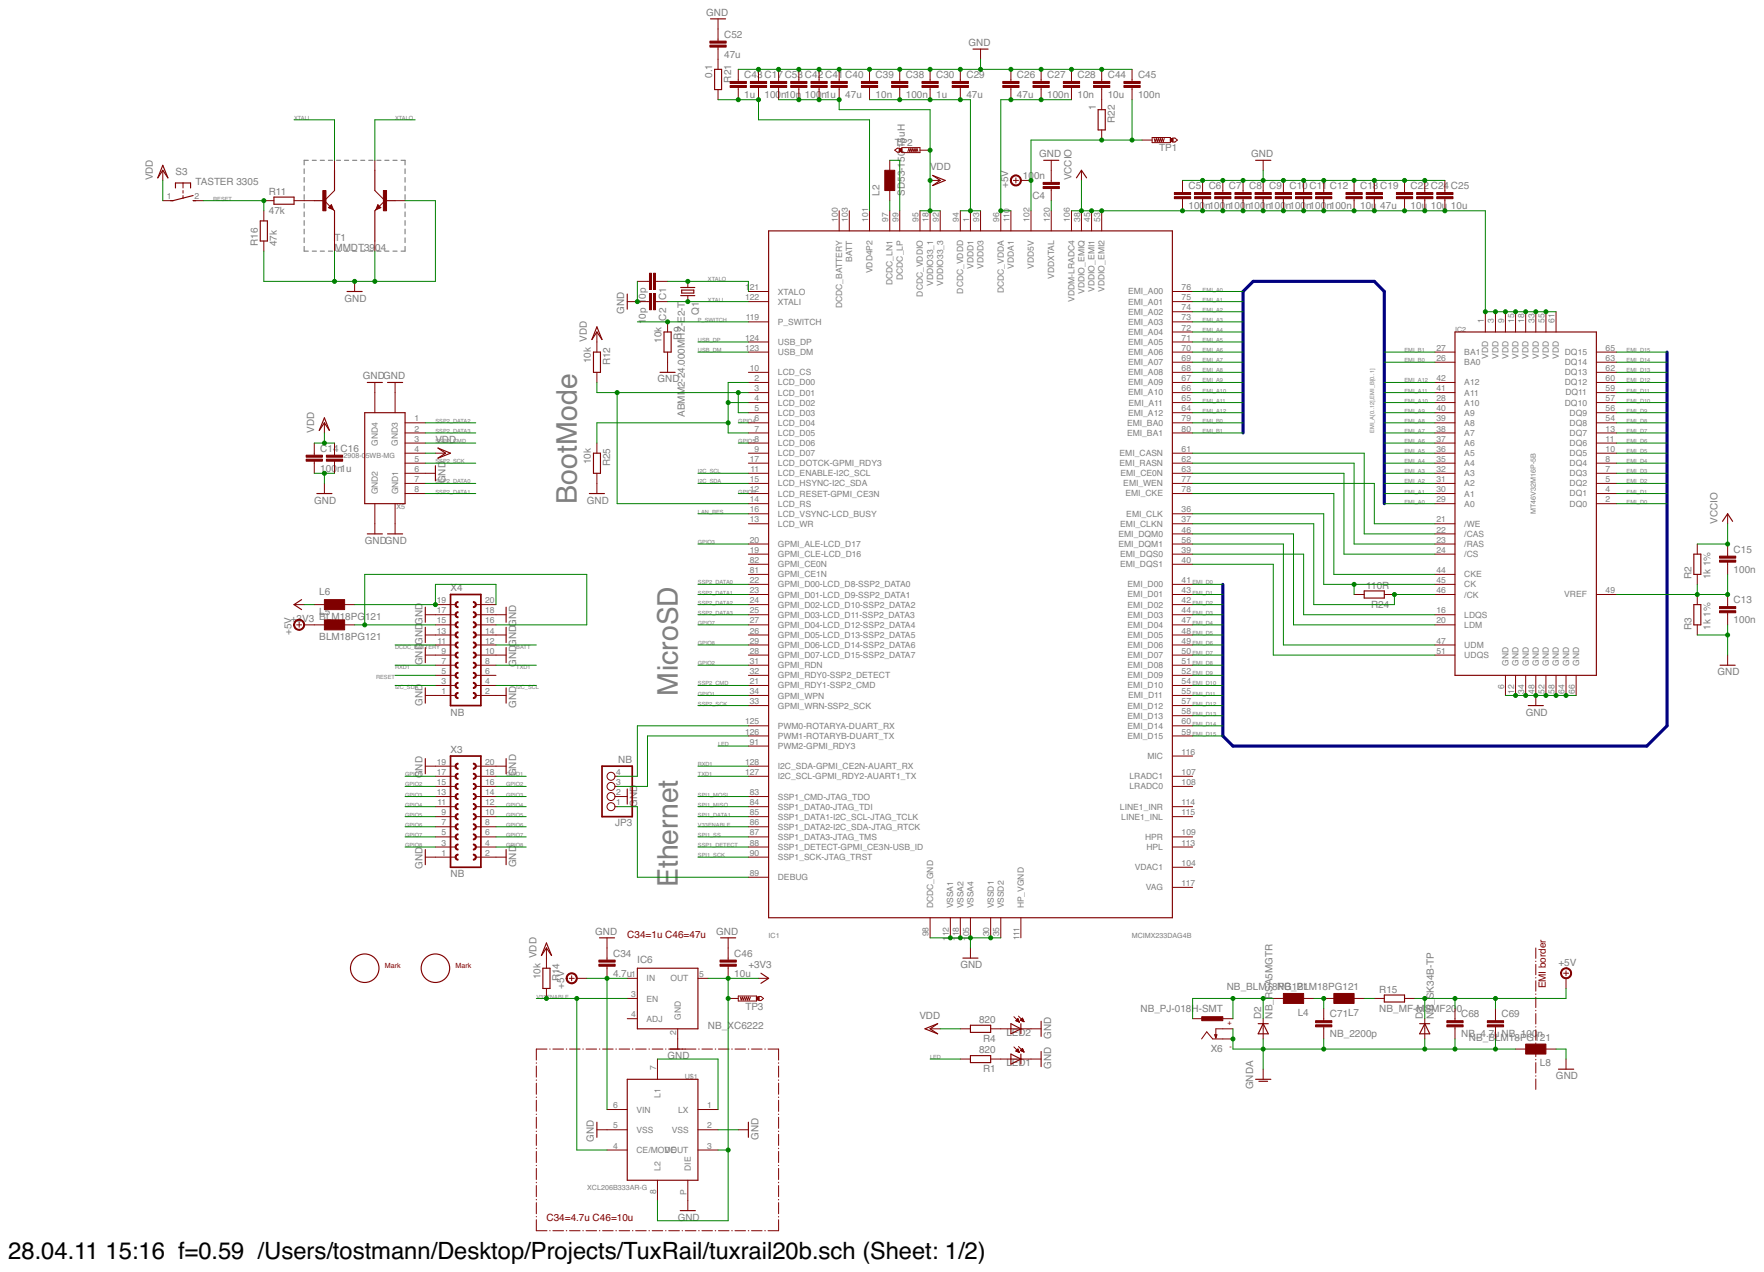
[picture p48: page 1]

28.04.11 15:16 f=0.59 /Users/tostmann/Desktop/Projects/TuxRail/tuxrail20b.sch (Sheet: 1/2)

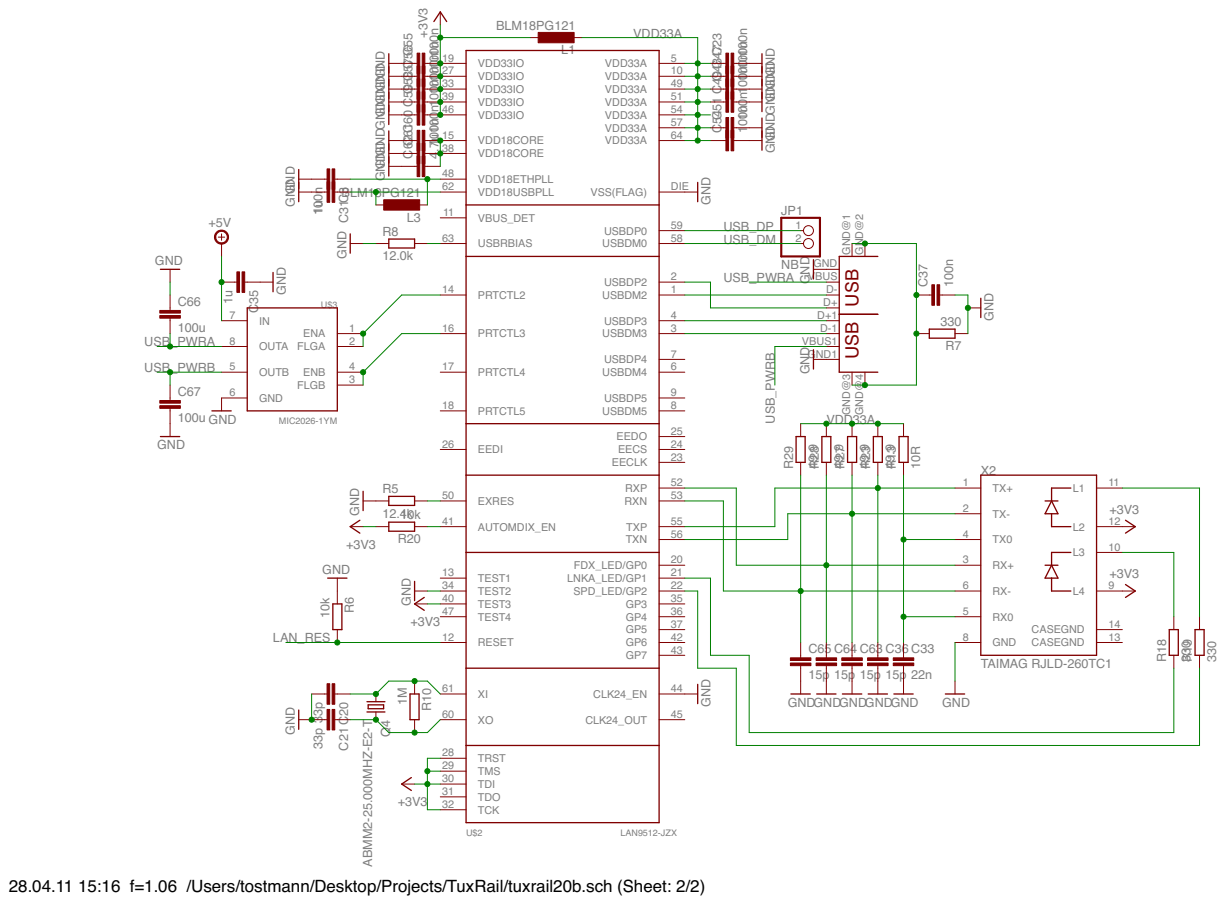
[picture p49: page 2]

00n 10 n 10 n 10 n 10 nGND GND GND GND GND

39 | 51
46 | 54

28.04.11 15:16 f=1.06 /Users/tostmann/Desktop/Projects/TuxRail/tuxrail20b.sch (Sheet: 2/2)

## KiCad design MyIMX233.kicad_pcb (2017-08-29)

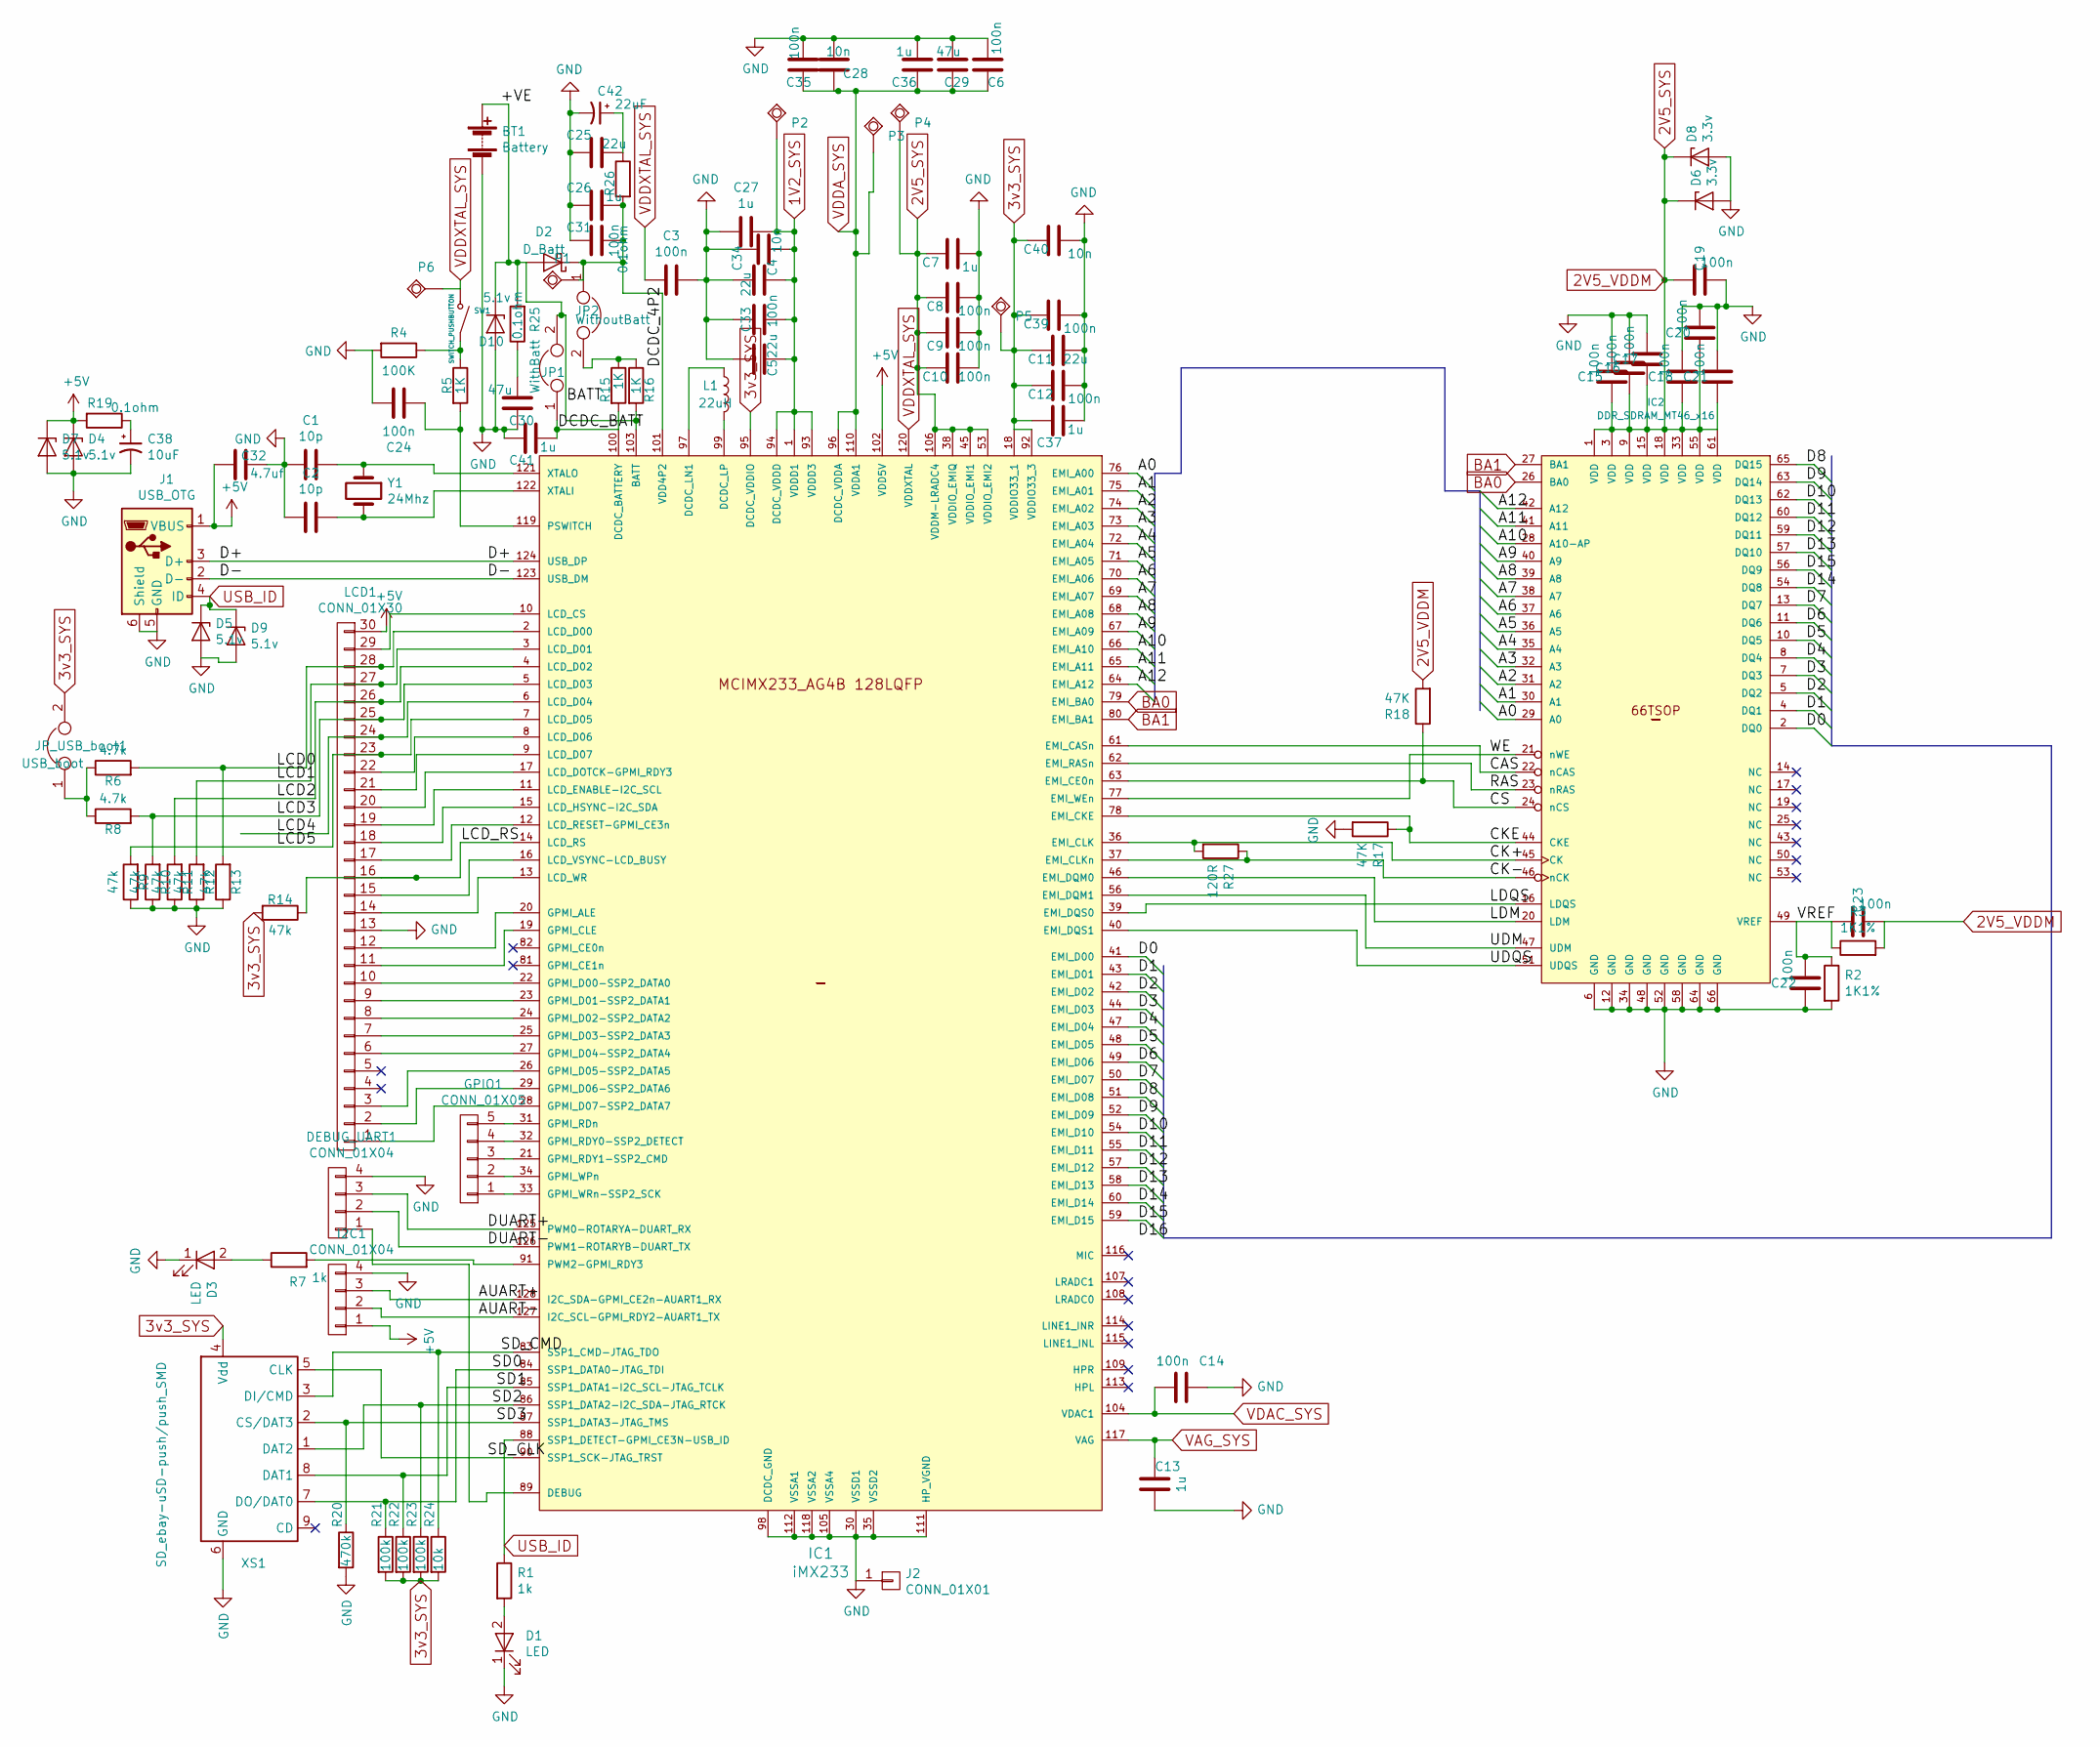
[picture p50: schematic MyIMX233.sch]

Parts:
BT1: Battery; JST_XH_B02B-XH-A_02x2.50mm_Straight
C1, C2: 10p; C_0402
C3, C6, C8, C9, C10, C12, C14, C15, C16, C17, C18, C19, C20, C21, C22, C23, C24, C31, C33, C35, C39: 100n; C_0402
C4, C5, C11, C25: 22u; C_0805_HandSoldering
C7: 1u; C_0805_HandSoldering
C13, C36, C37, C41: 1u; C_0603_HandSoldering
C26, C27: 1u; C_0402
C28, C34, C40: 10n; C_0402
C29, C30: 47u; C_0805_HandSoldering
C32: 4.7uf; C_0603_HandSoldering
C38: 10uF; CP_Radial_D5.0mm_P2.50mm
C42: 22uF; CP_Radial_D5.0mm_P2.50mm
D1: LED; LED_D4.0mm
D2: D_Batt; D_SOD-323_HandSoldering
D3: LED; LED_0603
D4, D5, D10: 5.1v; D_SOD-323_HandSoldering
D6: 3.3v; D_SOD-123
D7, D9: 5.1v; D_DO-35_SOD27_P7.62mm_Horizontal
D8: 3.3v; D_DO-35_SOD27_P7.62mm_Horizontal
DEBUG_UART1: CONN_01X04; Pin_Header_Straight_1x04_Pitch2.54mm
GPIO1: CONN_01X05; Pin_Header_Straight_1x05_Pitch2.54mm
I2C1: CONN_01X04; Pin_Header_Straight_1x04_Pitch2.54mm
IC1: iMX233; LQFP-128_14x14mm_Pitch0.4mm
IC2: DDR_SDRAM_MT46_x16; TSOP66_JEDEC_DDR_SDRAM
J1: USB_OTG; USB_Micro-B_MOLEX_105017-0001
J2: CONN_01X01; 1pin
JP1: WithBatt; Pin_Header_Straight_1x02_Pitch2.54mm
JP2: WithoutBatt; Pin_Header_Straight_1x02_Pitch2.54mm
JP_USB_boot1: USB_boot; Pin_Header_Straight_1x02_Pitch2.54mm
L1: 22uH; Bourns22uh6x6mm
LCD1: CONN_01X30; Pin_Header_Straight_1x30_Pitch2.54mm
P1: 4p2; GOGO_TESTPAD2
P2: 1v2; GOGO_TESTPAD2
P3: VDDA1v8; GOGO_TESTPAD2
P4: 2v5; GOGO_TESTPAD2
P5: 3v3; GOGO_TESTPAD2
P6: 1v; GOGO_TESTPAD2
R1, R7: 1k; R_0603_HandSoldering
R2, R3: 1K1%; R_0603
R4: 100K; R_0603_HandSoldering
R5: 1K; R_0603_HandSoldering
R6, R8: 4.7k; R_0603_HandSoldering
R9, R10, R11, R12, R13, R14: 47k; R_0603_HandSoldering
R15, R16: 1K; R_0603
R17, R18: 47K; R_0603
R19, R25, R26: 0.1ohm; R_0603_HandSoldering
R20: 470k; R_0603_HandSoldering
R21, R22, R23: 100k; R_0603_HandSoldering
R24: 10k; R_0603_HandSoldering
R27: 120R; R_0603
SW1: SWITCH_PUSHBUTTON; SW_PUSH_6mm
XS1: SD_ebay-uSD-push/push_SMD; uSDcard
Y1: 24Mhz; Crystal_HC49-4H_Vertical

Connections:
1V2_SYS: C4.2, C5.2, C27.2, C33.1, C34.1, IC1.1 (VDDD1), IC1.93 (VDDD3), IC1.94 (DCDC_VDDD), P2.P$1
2V5_SYS: C7.2, C8.2, C9.2, C10.2, C15.1, C16.1, C17.1, C18.1, C19.1, C20.1, C21.1, C23.2, D6.1 (K), D8.1 (K), IC1.38 (VDDIO_EMIQ), IC1.45 (VDDIO_EMI1), IC1.53 (VDDIO_EMI2), IC1.106 (VDDM-LRADC4), IC2.1 (VDD), IC2.3 (VDD), IC2.9 (VDD), IC2.15 (VDD), IC2.18 (VDD), IC2.33 (VDD), IC2.55 (VDD), IC2.61 (VDD), P4.P$1, R3.2, R18.2
3v3_SYS: C11.2, C12.2, C37.1, C39.2, C40.2, IC1.18 (VDDIO33_1), IC1.92 (VDDIO33_3), IC1.95 (DCDC_VDDIO), JP_USB_boot1.2, P5.P$1, R14.2, R21.2, R22.2, R23.2, R24.2, XS1.4 (Vdd)
+5V: C32.1, D4.1 (K), D7.1 (K), I2C1.1, IC1.102 (VDD5V), J1.1 (VBUS), LCD1.30, R19.2
/+VE: BT1.1 (+), D2.2 (A), D10.1 (K), IC1.103 (BATT), JP1.2, R16.2, R25.2
/A0: IC1.76 (EMI_A00), IC2.29 (A0)
/A1: IC1.75 (EMI_A01), IC2.30 (A1)
/A2: IC1.74 (EMI_A02), IC2.31 (A2)
/A3: IC1.73 (EMI_A03), IC2.32 (A3)
/A4: IC1.72 (EMI_A04), IC2.35 (A4)
/A5: IC1.71 (EMI_A05), IC2.36 (A5)
/A6: IC1.70 (EMI_A06), IC2.37 (A6)
/A7: IC1.69 (EMI_A07), IC2.38 (A7)
/A8: IC1.68 (EMI_A08), IC2.39 (A8)
/A9: IC1.67 (EMI_A09), IC2.40 (A9)
/A10: IC1.66 (EMI_A10), IC2.28 (A10-AP)
/A11: IC1.65 (EMI_A11), IC2.41 (A11)
/A12: IC1.64 (EMI_A12), IC2.42 (A12)
/AUART+: I2C1.3, IC1.128 (I2C_SDA-GPMI_CE2n-AUART1_RX)
/AUART-: I2C1.2, IC1.127 (I2C_SCL-GPMI_RDY2-AUART1_TX)
/CAS: IC1.61 (EMI_CASn), IC2.22 (nCAS)
/CK+: IC1.36 (EMI_CLK), IC2.45 (CK), R27.2
/CK-: IC1.37 (EMI_CLKn), IC2.46 (nCK), R27.1
/CKE: IC1.78 (EMI_CKE), IC2.44 (CKE), R17.1
/CS: IC1.63 (EMI_CE0n), IC2.24 (nCS), R18.1
/D0: IC1.41 (EMI_D00), IC2.2 (DQ0)
/D1: IC1.43 (EMI_D01), IC2.4 (DQ1)
/D2: IC1.42 (EMI_D02), IC2.5 (DQ2)
/D3: IC1.44 (EMI_D03), IC2.7 (DQ3)
/D4: IC1.47 (EMI_D04), IC2.8 (DQ4)
/D5: IC1.48 (EMI_D05), IC2.10 (DQ5)
/D6: IC1.49 (EMI_D06), IC2.11 (DQ6)
/D7: IC1.50 (EMI_D07), IC2.13 (DQ7)
/D8: IC1.51 (EMI_D08), IC2.65 (DQ15)
/D9: IC1.52 (EMI_D09), IC2.63 (DQ14)
/D10: IC1.54 (EMI_D10), IC2.62 (DQ13)
/D11: IC1.55 (EMI_D11), IC2.60 (DQ12)
/D12: IC1.57 (EMI_D12), IC2.59 (DQ11)
/D13: IC1.58 (EMI_D13), IC2.57 (DQ10)
/D14: IC1.60 (EMI_D14), IC2.54 (DQ8)
/D15: IC1.59 (EMI_D15), IC2.56 (DQ9)
/D+: IC1.124 (USB_DP), J1.3 (D+)
/D-: IC1.123 (USB_DM), J1.2 (D-)
/DCDC_4P2: C26.2, C31.1, D2.1 (K), IC1.101 (VDD4P2), JP2.1, P1.P$1, R26.2
/DCDC_BATT: C41.2, IC1.100 (DCDC_BATTERY), JP1.1, R15.2
/DUART+: DEBUG_UART1.3, IC1.125 (PWM0-ROTARYA-DUART_RX)
/DUART-: DEBUG_UART1.2, IC1.126 (PWM1-ROTARYB-DUART_TX)
/LCD0: IC1.2 (LCD_D00), LCD1.28, R6.2, R13.2
/LCD1: IC1.3 (LCD_D01), LCD1.27, R12.2
/LCD2: IC1.4 (LCD_D02), LCD1.26, R11.2
/LCD3: IC1.5 (LCD_D03), LCD1.25, R8.2, R10.2
/LCD4: IC1.6 (LCD_D04), LCD1.24
/LCD5: IC1.7 (LCD_D05), LCD1.23, R9.2
/LCD_RS: IC1.14 (LCD_RS), LCD1.16, R14.1
/LDM: IC1.46 (EMI_DQM0), IC2.20 (LDM)
/LDQS: IC1.39 (EMI_DQS0), IC2.16 (LDQS)
/RAS: IC1.62 (EMI_RASn), IC2.23 (nRAS)
/SD0: IC1.84 (SSP1_DATA0-JTAG_TDI), R21.1, XS1.7 (DO/DAT0)
/SD1: IC1.85 (SSP1_DATA1-I2C_SCL-JTAG_TCLK), R22.1, XS1.8 (DAT1)
/SD2: IC1.86 (SSP1_DATA2-I2C_SDA-JTAG_RTCK), R23.1, XS1.1 (DAT2)
/SD3: IC1.87 (SSP1_DATA3-JTAG_TMS), R20.1, XS1.2 (CS/DAT3)
/SD_CLK: IC1.90 (SSP1_SCK-JTAG_TRST), XS1.5 (CLK)
/SD_CMD: IC1.83 (SSP1_CMD-JTAG_TDO), R24.1, XS1.3 (DI/CMD)
/UDM: IC1.56 (EMI_DQM1), IC2.47 (UDM)
/UDQS: IC1.40 (EMI_DQS1), IC2.51 (UDQS)
/VREF: C22.2, C23.1, IC2.49 (VREF), R2.1, R3.1
/WE: IC1.77 (EMI_WEn), IC2.21 (nWE)
BA0: IC1.79 (EMI_BA0), IC2.26 (BA0)
BA1: IC1.80 (EMI_BA1), IC2.27 (BA1)
GND: BT1.2 (-), C1.1, C2.1, C3.2, C4.1, C5.1, C6.1, C7.1, C8.1, C9.1, C10.1, C11.1, C12.1, C13.2, C14.1, C15.2, C16.2, C17.2, C18.2, C19.2, C20.2, C21.2, C22.1, C24.1, C25.1, C26.1, C27.1, C28.1, C29.1, C30.2, C31.2, C32.2, C33.2, C34.2, C35.1, C36.1, C37.2, C38.2, C39.1, C40.1, C41.1, C42.2, D1.1 (K), D3.1 (K), D4.2 (A), D5.2 (A), D6.2 (A), D7.2 (A), D8.2 (A), D9.2 (A), D10.2 (A), DEBUG_UART1.4, I2C1.4, IC1.30 (VSSD1), IC1.35 (VSSD2), IC1.98 (DCDC_GND), IC1.105 (VSSA4), IC1.111 (HP_VGND), IC1.112 (VSSA1), IC1.118 (VSSA2), IC2.6 (GND), IC2.12 (GND), IC2.34 (GND), IC2.48 (GND), IC2.52 (GND), IC2.58 (GND), IC2.64 (GND), IC2.66 (GND), J1.5 (GND), J1.6 (Shield), J2.1, LCD1.13, R2.2, R4.2, R9.1, R10.1, R11.1, R12.1, R13.1, R17.2, R20.2, XS1.6 (GND)
unnamed: C1.2, IC1.121 (XTALO), Y1.1
unnamed: C2.2, IC1.122 (XTALI), Y1.2
unnamed: C24.2, IC1.119 (PSWITCH), R5.2
unnamed: C25.2, C42.1, R26.1
unnamed: C30.1, R25.1
unnamed: C38.1, R19.1
unnamed: D1.2 (A), R1.2
unnamed: D3.2 (A), R7.1
unnamed: DEBUG_UART1.1, IC1.89 (DEBUG)
unnamed: GPIO1.1, IC1.33 (GPMI_WRn-SSP2_SCK)
unnamed: GPIO1.2, IC1.34 (GPMI_WPn)
unnamed: GPIO1.3, IC1.21 (GPMI_RDY1-SSP2_CMD)
unnamed: GPIO1.4, IC1.32 (GPMI_RDY0-SSP2_DETECT)
unnamed: GPIO1.5, IC1.31 (GPMI_RDn)
unnamed: IC1.8 (LCD_D06), LCD1.22
unnamed: IC1.9 (LCD_D07), LCD1.21
unnamed: IC1.10 (LCD_CS), LCD1.29
unnamed: IC1.11 (LCD_ENABLE-I2C_SCL), LCD1.19
unnamed: IC1.12 (LCD_RESET-GPMI_CE3n), LCD1.17
unnamed: IC1.13 (LCD_WR), LCD1.14
unnamed: IC1.15 (LCD_HSYNC-I2C_SDA), LCD1.18
unnamed: IC1.16 (LCD_VSYNC-LCD_BUSY), LCD1.15
unnamed: IC1.17 (LCD_DOTCK-GPMI_RDY3), LCD1.20
unnamed: IC1.19 (GPMI_CLE), LCD1.11
unnamed: IC1.20 (GPMI_ALE), LCD1.12
unnamed: IC1.22 (GPMI_D00-SSP2_DATA0), LCD1.10
unnamed: IC1.23 (GPMI_D01-SSP2_DATA1), LCD1.9
unnamed: IC1.24 (GPMI_D02-SSP2_DATA2), LCD1.8
unnamed: IC1.25 (GPMI_D03-SSP2_DATA3), LCD1.7
unnamed: IC1.26 (GPMI_D05-SSP2_DATA5), LCD1.3
unnamed: IC1.27 (GPMI_D04-SSP2_DATA4), LCD1.6
unnamed: IC1.28 (GPMI_D07-SSP2_DATA7), LCD1.1
unnamed: IC1.29 (GPMI_D06-SSP2_DATA6), LCD1.2
unnamed: IC1.91 (PWM2-GPMI_RDY3), R7.2
unnamed: IC1.97 (DCDC_LN1), L1.1
unnamed: IC1.99 (DCDC_LP), L1.2
unnamed: JP2.2, R15.1, R16.1
unnamed: JP_USB_boot1.1, R6.1, R8.1
unnamed: R4.1, R5.1, SW1.2 (B)
USB_ID: D5.1 (K), D9.1 (K), IC1.88 (SSP1_DETECT-GPMI_CE3N-USB_ID), J1.4 (ID), R1.1
VAG_SYS: C13.1, IC1.117 (VAG)
VDAC_SYS: C14.2, IC1.104 (VDAC1)
VDDA_SYS: C6.2, C28.2, C29.2, C35.2, C36.2, IC1.96 (DCDC_VDDA), IC1.110 (VDDA1), P3.P$1
VDDXTAL_SYS: C3.1, IC1.120 (VDDXTAL), P6.P$1, SW1.1 (A)

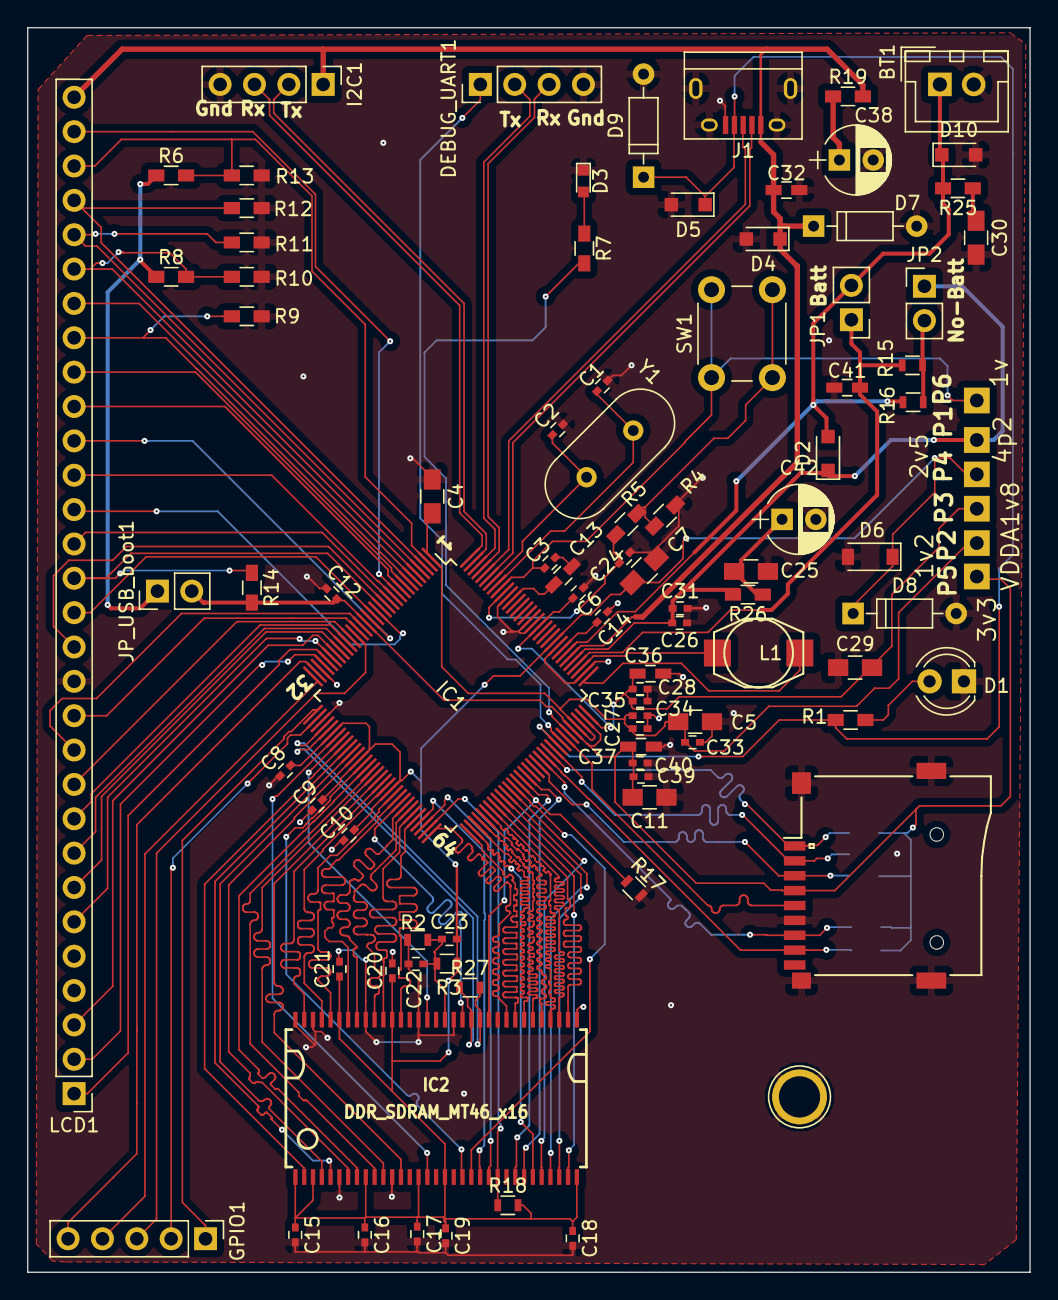
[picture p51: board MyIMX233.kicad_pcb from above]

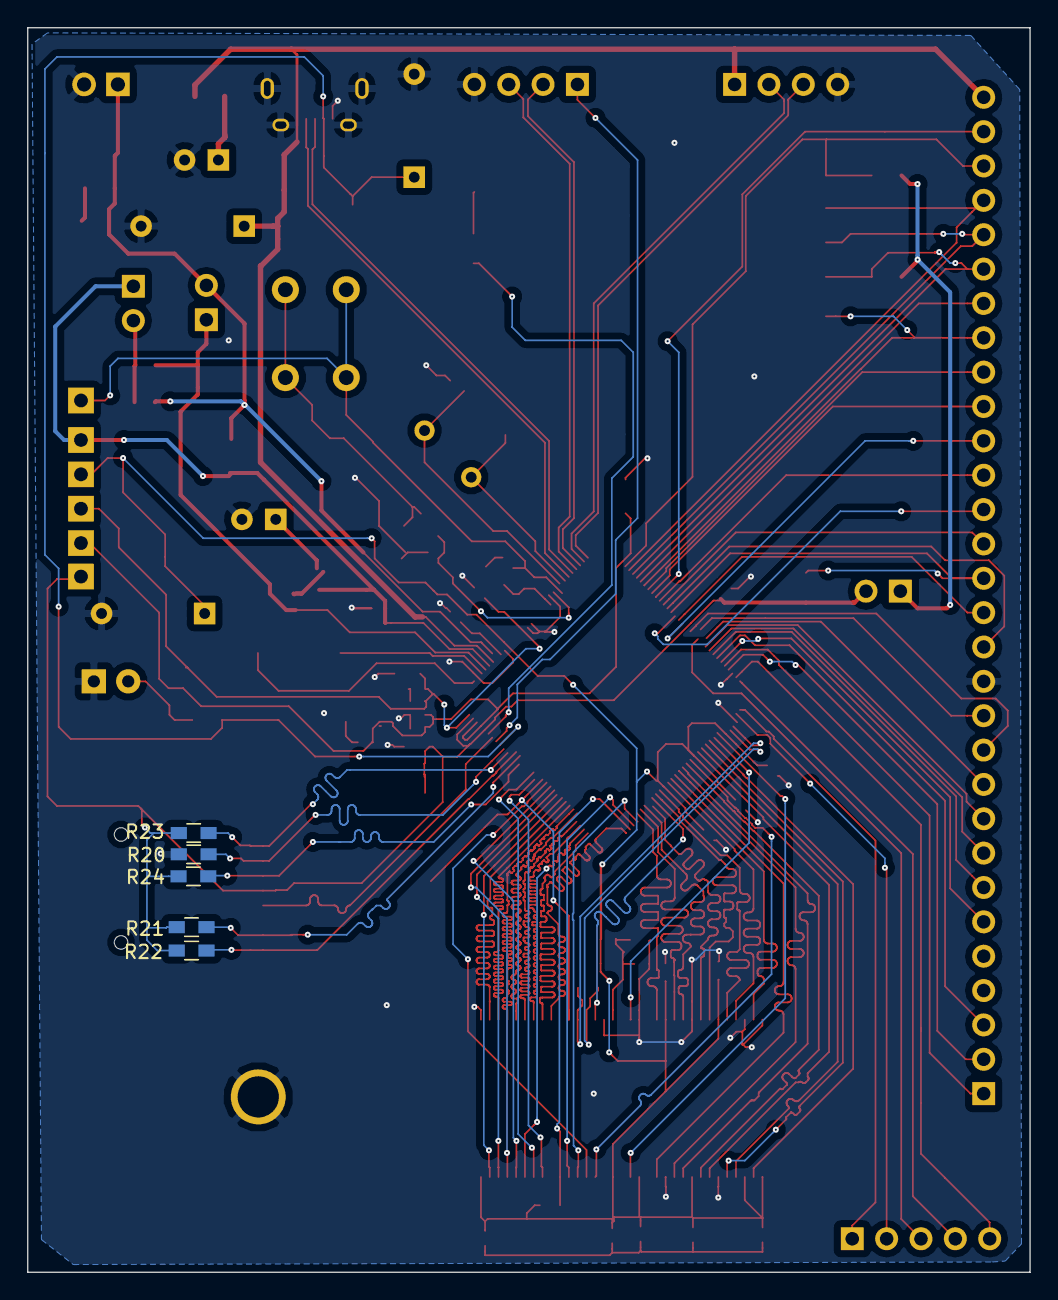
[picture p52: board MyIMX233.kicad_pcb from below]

Board: 2 copper layers, 74.1 x 92.0 mm, 101 parts (5 on the bottom side), 114 nets.

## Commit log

2017-05-01 first schematic
    [MyIMX233.sch]
2017-05-01 footprint mapped
    [MyIMX233.sch]
2017-05-07 pcb without length matching and plot
    [MyIMX233.kicad_pcb, MyIMX233.sch]
2017-05-08 pcb without length matching added
2017-05-09 lane 1 length matched 42.4
    [MyIMX233.kicad_pcb]
2017-05-10 refs added plus tuned lengths of d8..15 and addr
    [MyIMX233.kicad_pcb, MyIMX233.sch]
2017-05-19 updated pcb export with 3d step files plus my new DDR step and FreeCAD proj
    [DDR_66_TSOP_40mil.step, MyIMX233.kicad_pcb, MyIMX233.sch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]
2017-06-01 before dcdc
    [MyIMX233.kicad_pcb, MyIMX233.sch]
2017-06-07 updated with step files new battery and inductor diag
    [10118194-0001LF.STEP, 10501-70001-USB.stp, Element14Dump.xlsx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]
2017-06-07 updated cap comparision
    [cap_comp.xlsx]
2017-06-10 pcb gerber sent
    [MyIMX233.kicad_pcb]
2017-06-16 updated via size
    [MyIMX233-B.Cu.gbl, MyIMX233-B.Mask.gbs, MyIMX233-B.SilkS.gbo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]
2017-08-10 2nd version
    [DM3AT-SF-PEJM5-SD_card.stp, MyIMX233.kicad_pcb, MyIMX233.sch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]
2017-08-10 updated README and added uSD mod and lib which might work without 3D
    [_saved_MyIMX233.sch]
2017-08-15 new uSD card connector added
    [MyIMX233.kicad_pcb, MyIMX233.sch, _saved_MyIMX233.sch]
2017-08-15 usb footprint updated
    [MyIMX233.kicad_pcb, MyIMX233.sch]
2017-08-15 added boot resistors and 2.5v_VDDM is separated for ram, new battery connections with resistors for non battery mode
    [MyIMX233.kicad_pcb, MyIMX233.sch]
2017-08-15 resistors placement
    [MyIMX233.kicad_pcb, MyIMX233.sch]
2017-08-18 boot resistors added
    [MyIMX233.kicad_pcb, MyIMX233.sch, _saved_MyIMX233.sch]
2017-08-20 re routed because of pad length extention to 2mm. Generated gerver files too
    [MyIMX233-B.Cu.gbl, MyIMX233-B.Mask.gbs, MyIMX233-B.SilkS.gbo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]
2017-08-20 updated SD card line tuning
    [MyIMX233-B.Cu.gbl, MyIMX233-B.Mask.gbs, MyIMX233-B.SilkS.gbo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]
2017-08-20 updated readme added 3d step model for SD card
    [MyIMX233.kicad_pcb, uSD_push-push_ebay112J-TXAR-R_C_1.stp]
2017-08-20 some more export schematic and pcb images added
2017-08-21 added electrolytic caps and fixed a bug in RAM CS and CE resistors
    [MyIMX233.kicad_pcb, MyIMX233.sch, _saved_MyIMX233.sch]
2017-08-25 squashed 5 commits
    [MyIMX233-B.Cu.gbl, MyIMX233-B.Mask.gbs, MyIMX233-B.SilkS.gbo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]
2017-08-27 added SD data resistors, clk nCLK resistor, series resistor to stop oscillation
    [MyIMX233.kicad_pcb, MyIMX233.sch]
2017-08-27 added optional 22uf electrolyte cap in 4p2
    [MyIMX233-B.Cu.gbl, MyIMX233-B.Mask.gbs, MyIMX233-B.SilkS.gbo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]
2017-08-27 mounting hole added once for all time in schematic
    [MyIMX233-B.Cu.gbl, MyIMX233-B.Mask.gbs, MyIMX233-B.SilkS.gbo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]
2017-08-29 kicad removed unconnected wire and added bill of materials plus some images in kitsnspares
    [KitsNsparesFinal.ods, MyIMX233.kicad_pcb, MyIMX233_v2_bom.csv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]
2017-08-29 clk nclk termination resistor position fixed and due to which some more length tuning of udq udm
    [MyIMX233-B.Cu.gbl, MyIMX233-B.Mask.gbs, MyIMX233-B.SilkS.gbo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]
2017-08-29 gerber created again
    [MyIMX233-B.Cu.gbl, MyIMX233-B.Mask.gbs, MyIMX233-B.SilkS.gbo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]
2017-10-08 first time working board
